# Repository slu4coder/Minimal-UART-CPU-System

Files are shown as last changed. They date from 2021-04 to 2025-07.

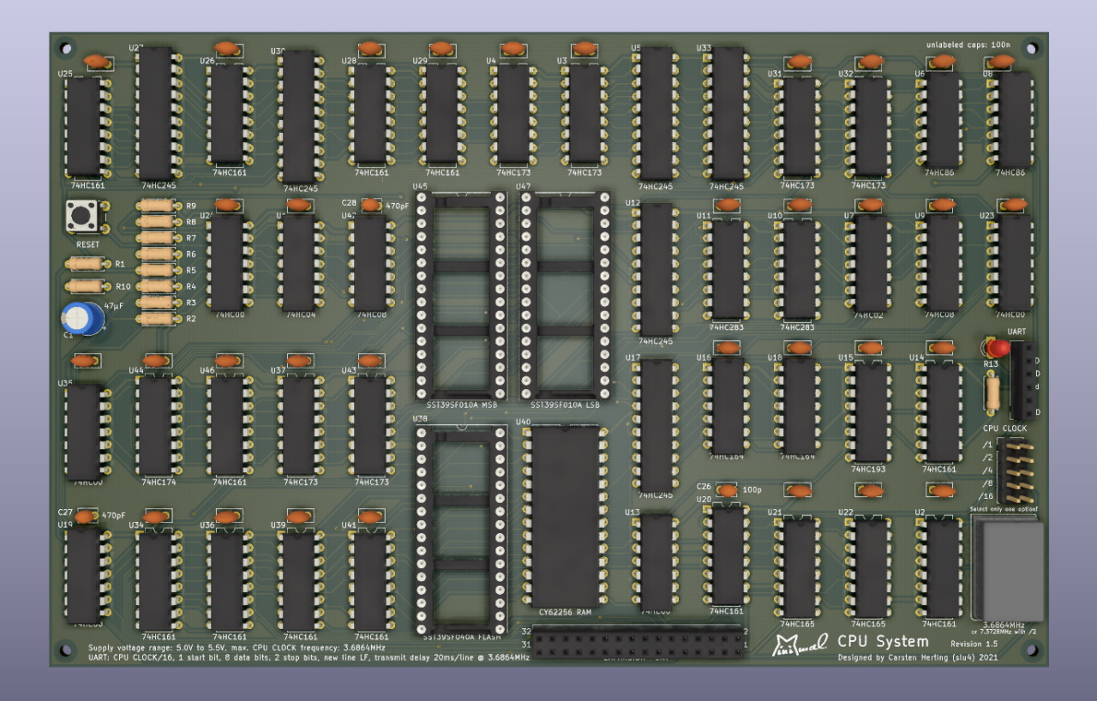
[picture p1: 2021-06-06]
Revisions 1.3 - 1.6 (FLASH)/Revision 1.5 (Expanded)/Minimal 1.5 Layout.jpg

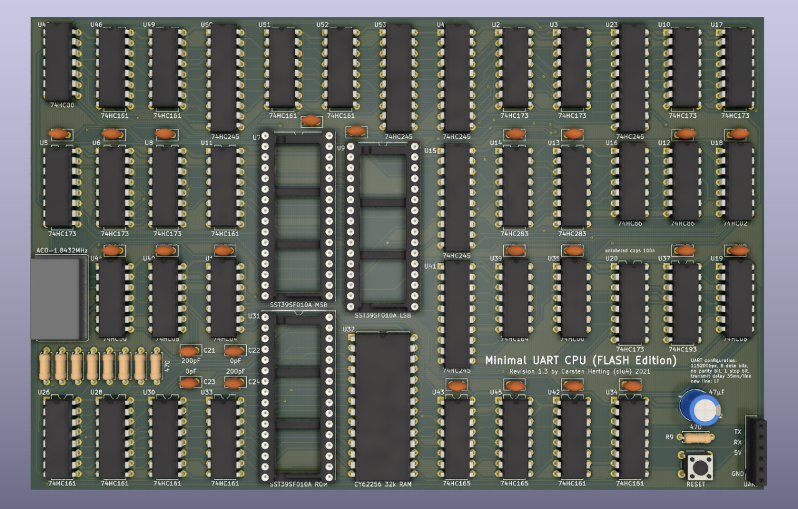
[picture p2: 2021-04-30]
Revisions 1.3 - 1.6 (FLASH)/Revision 1.3 (FLASH Edition)/Minimal 1.3 Layout.jpg

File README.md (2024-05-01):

# Legacy: Minimal UART CPU System

See https://github.com/slu4coder/Minimal-64x4-Home-Computer for the most recent version.

Quick note: This is a free and non-commercial project. I am in no way associated with any activies selling this as a product.
Any such activity represents a license violation. Individual licenses apply for hardware and software parts. Please refer to
appropriate documentations for detailed licensing information.

Minimal CPU 2.0 'Ultra' is now running at 10MHz(!) and may well be the fastest 8-bit general purpose 74HC logic breadboard computer to this date:

Ultra

Latest PCB version 1.5:

test

● Build your own 'Minimal CPU System' on breadboards: https://www.youtube.com/watch?v=Gz1VVOsNn_8

● Python-like high-level programming language MIN released: https://www.youtube.com/watch?v=H342TwW4R7k

● 'Minimal VGA Extension Card' released! https://github.com/slu4coder/DIY-VideoRAM/tree/main/KiCAD

● 'Minimal CPU System' Emulator released! See user manual chapter 'Minimal Emulator' for details.

● Native assembler and text editor released!

● User Manual and Reference: https://docs.google.com/document/d/1c2ZHtLd1BBAwcBAjBZZJmCA3AXpbpv80dlAtsMYpuF4/edit?usp=sharing

● Revision 1.5 is out now featuring 512KB FLASH SSD, 3.6864MHz clock speed and an expansion port!
https://www.youtube.com/watch?v=osVi06VKvA0

● Minimal Python Assembler released: https://www.youtube.com/watch?v=rdKX9hzA2lU

● The Minimal CPU System now has a dedicated hardware serial 'Minimal Terminal': https://github.com/slu4coder/Minimal-Terminal
but can also be operated via a USB-to-serial breakout board and a terminal emulation (e. g. Tera Term) of cause.

I've built my own Computer from scratch - using nothing but TTL chips, because, well, why not? I wanted a CPU that is easy to understand, fun to build and powerful enough to allow for programming educational stuff and little games on it. Ah, and by the way - it should be as simple as possible - sort of the "Simplest Usable Personal Computer". This repo provides you with everything you need to follow my one-and-a-half-year journey down this rabbit hole. Besides running some video game classics, this little DIY CPU is capable of parsing arbitrary mathmatical expressions and performing floating point calculations in single (32-bit) precision. And it comes with an SSD file system, too, since it uses it's own FLASH IC as permanent SSD storage. Over the last year I have written an entire native toolchain: a text editor, an assembler and the Python-like high-level programming language MIN.

WHAT YOU GET:

  ● Block diagram of the CPU and overview it's instruction set
  
  ● KiCAD project files with detailed schematics and PCB layout
  
  ● Gerber files ready to be submitted at any PCB manufacturer of your choice
  
  ● Bill of material
  
  ● Images in .bin format of both the ROM and the CPU's control microcode
  
  ● Source code of the minimal operating system MinOS and several demos and games
  
  ● Cross-assembler 'asm.exe' running on Windows (or Python) to comfortably write, assemble and upload your own software

TECHNICAL SPECIFICATION:
  
  ● Processing power (1.0Mips @8.3MHz) comparable to 2.3 x Commodore 64 or Apple II
  
  ● Clear(est?) and simple(st? – you judge!) design for fun and education
  
  ● 8-bit data bus, 16-bit address bus, Von-Neumann architecture
  
  ● 64 instructions (conditional branching, subroutines, stack and word ops)
  
  ● 32KB RAM / 512KB FLASH ROM (OS, memory monitor, disassembler, tools)
  
  ● SSD file system (commands LOAD, SAVE, DIR, DELETE, FORMAT as you'd expect)
  
  ● UART interface (up to 500kbps) for terminal display, keyboard input and file I/O
 
  ● Expansion port (I/O card and VGA card available, build your own!)
   
  ● 24 (16) control signals, 2 registers A and B, ALU (arithmetic and logic unit) = simple adder, 3 flags (negative, carry and zero)
  
  ● Built from 74HCxx TTL logic on 120mm x 190mm PCB or 8 breadboards

I hope you find this information useful, educational or otherwise interesting. I'd love to hear about your build, so meet me on YouTube.

https://www.youtube.com/channel/UCXYQcMpUBT3aaQKfmAVJNow

Have fun!
slu4

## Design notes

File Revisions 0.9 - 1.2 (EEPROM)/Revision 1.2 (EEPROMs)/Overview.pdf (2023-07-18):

- Comparable to Altair 8800 or Apple 1
- Clear(est?) and simple(st? – you judge!) design for fun and education
- 8-bit data bus, 16-bit address bus, Von-Neumann architecture
- 64 instructions (conditional branching, subroutines, stack and word ops)
- 1,8432MHz clock with 0.25Mips
(Altair 8800: 0.29Mips, Apple 1: 0.43Mips)
- 24kB RAM / 8kB ROM (OS, memory monitor, disassembler, tools, games)
- UART interface (115.2kbps)
for terminal display, keyboard input and file I/O
- 16 control signals
- 2 registers A and B
- ALU (arithmetic and logic unit) = simple adder
- 3 flags (negative, carry and zero)
- 74HCxx TTL logic on 120mm x 190mm PCB
- Cross-assembler (Windows 10) for easy programming and upload via terminal 'cut & past'

## Minimal UART Computer – Performance Overview

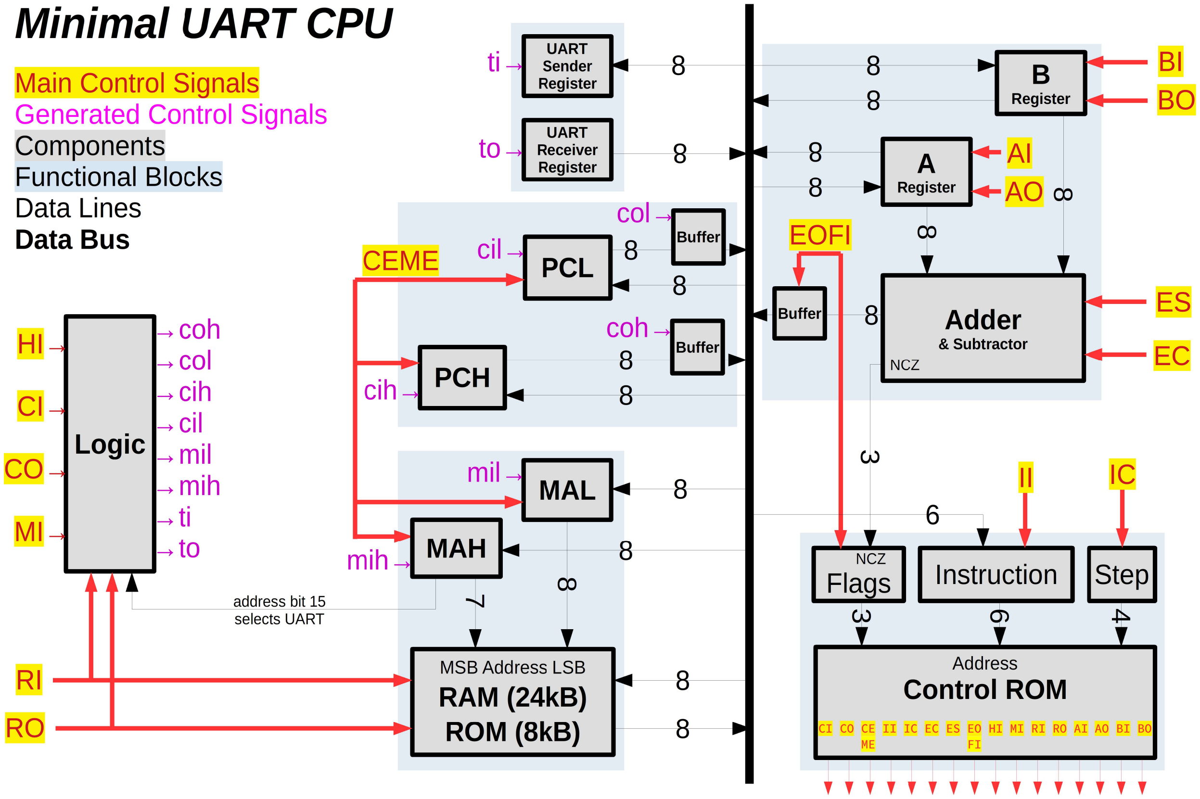
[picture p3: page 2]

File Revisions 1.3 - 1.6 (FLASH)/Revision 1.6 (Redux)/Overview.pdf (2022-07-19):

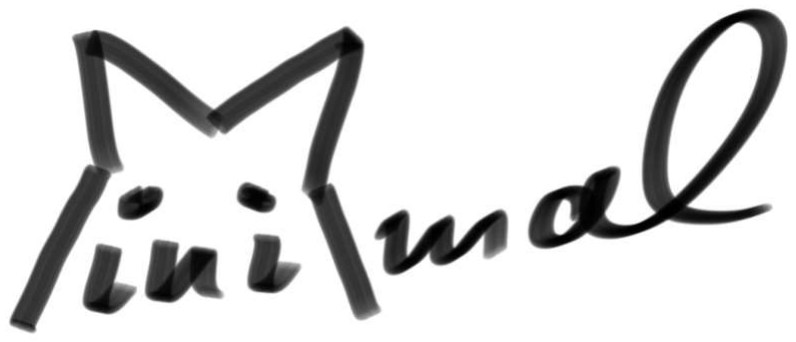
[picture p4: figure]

- Von-Neumann architecture, 8-bit data bus, 16-bit address bus
- 64 instructions including conditional branching, subroutines, stack and word operations
- UART interface for terminal display, keyboard input, data I/O & upload via 'cut & paste'
- 32KB RAM, 512KB FLASH with file system (format, load, save, dir, delete commands)
- Expansion port (I/O card, VGA card)
- Maximum clock speed 8.3MHz, 1.01Mips =
- 2 data registers A and B
- Simple adder
- 3 flags (negative, carry and zero)
- 24 control signals
- 39 TTL chips (74HCxx logic, 62256 SRAM, 39SF0x0 FLASH)
- Online reference manual
- Games like TETRIS, cross-assembler (Win10 or Python), cycle-exact emulator (Win10)
- Native tool-chain: Operating system, text editor, assembler, Python-like interpreter

# CPU System 1.6 Redux Beast Mode

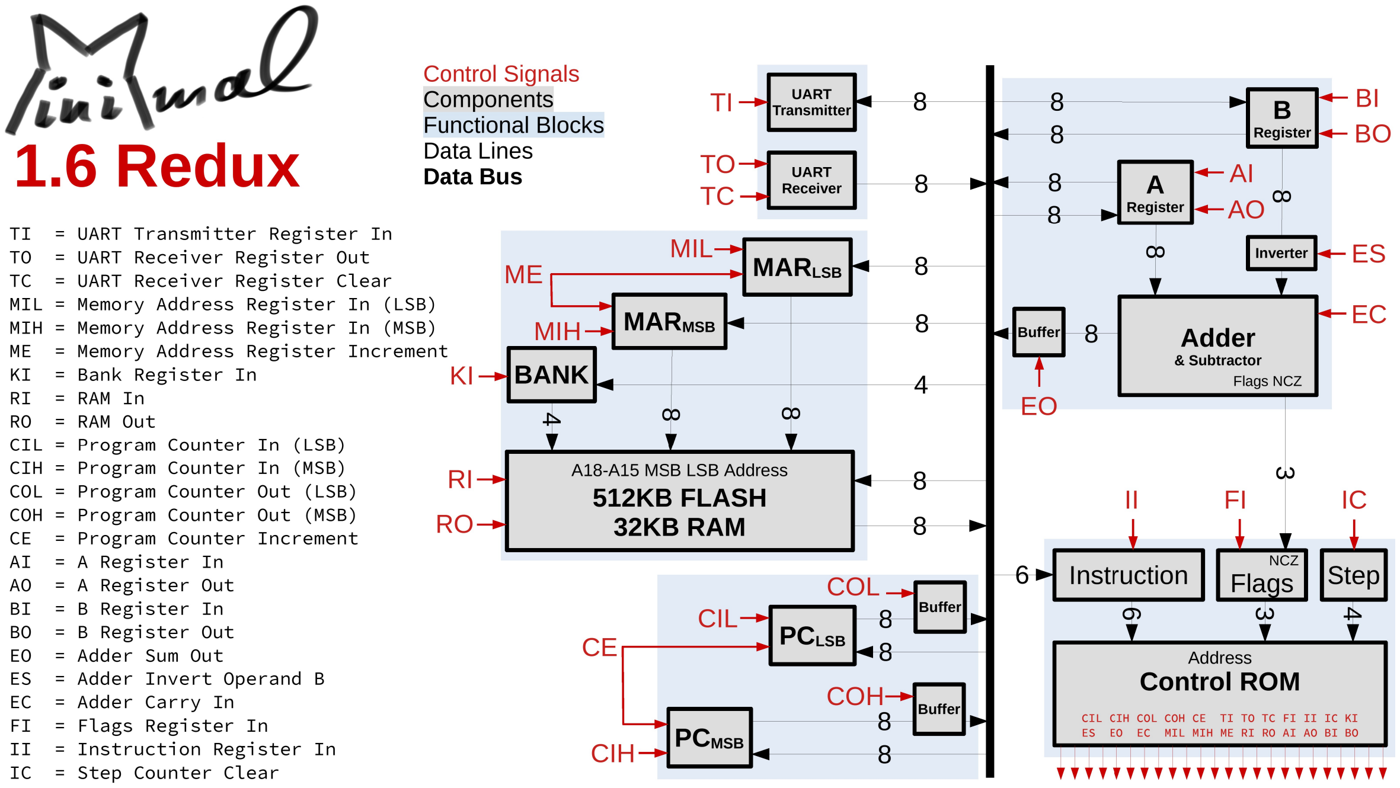
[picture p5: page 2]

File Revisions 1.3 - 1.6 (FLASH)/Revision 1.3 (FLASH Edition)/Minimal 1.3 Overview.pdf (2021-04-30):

- Comparable to Altair 8800 or Apple 1
- Clear(est?) and simple(st? – you judge!) design for fun and education
- 8-bit data bus, 16-bit address bus, Von-Neumann architecture
- 64 instructions (conditional branching, subroutines, stack and word operations)
- 1,8432MHz clock speed with 0.25Mips (Altair 8800: 0.29Mips, Apple 1: 0.43Mips)
- 32KB RAM and 4KB FLASH ROM (OS: memory monitor, tools, file system)
- 28KB SSD (file system: LOAD, SAVE, DELETE, SHOW) for games and demos
- UART interface (115.2kbps) for terminal display, keyboard input and data I/O
- only 16 control signals
- 2 data registers A and B
- ALU (arithmetic and logic unit) = simple adder
- 3 flags (negative, carry and zero)
- 74HCxx TTL logic on 115mm x 175mm PCB (all ICs also available in SMD package)
- Cross-assembler (Windows 10) for easy programming / upload via terminal 'cut & past'

## Minimal UART CPU (FLASH Edition) – Overview

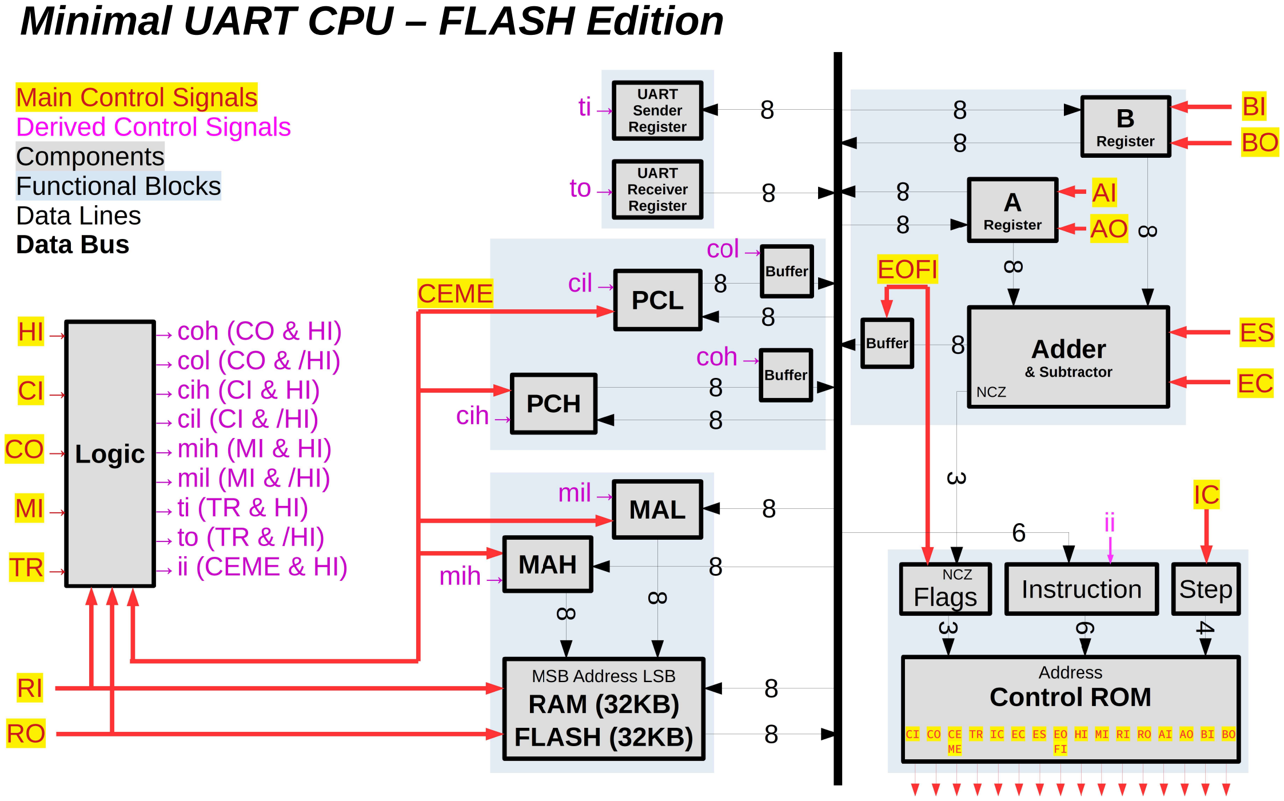
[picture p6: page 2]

Minimal UART CPU – FLASH Edition

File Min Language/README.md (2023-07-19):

# Min Is Not Python...
... but an interpreted computer language I develop for fun and as a learning experience, mainly to deploy it on my DIY 'Minimal UART CPU' project and also on my latest 'Minimal 64 Home Computer'.

This educational version of Min is written in 230 lines of Python code. Visit my YouTube channel for more information: https://www.youtube.com/channel/UCXYQcMpUBT3aaQKfmAVJNow

USAGE: python min.py blocks.min

What you get:

o Python-style indentation

o if-elif-else, while-break, print, def-return

o str(), input(), int(), len(), key(), random()

o string and integer data types

o local and global variables and 1-dimensional arrays

o functions with parameters and C-style referencing

o optional : and ; syntax sugar

o .. slicing operator replacing :

o 'A' replacing ord("A")

Have fun!

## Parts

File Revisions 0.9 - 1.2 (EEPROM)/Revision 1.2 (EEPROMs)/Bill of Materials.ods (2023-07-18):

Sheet: BOM sorted by reference
Ref | Value | Footprint
C1-C9 | 100nF | Capacitor_THT:C_Disc_D5.0mm_W2.5mm_P2.50mm
C10 | 100pF | Capacitor_THT:C_Disc_D5.0mm_W2.5mm_P2.50mm
C11-C51 | 100nF | Capacitor_THT:C_Disc_D5.0mm_W2.5mm_P2.50mm
C52 | 47µF | Capacitor_THT:CP_Radial_D7.5mm_P2.50mm
J1 | UART | Connector_PinSocket_1x06_P2.54mm_Vertical
R1-R8 | 470 | Resistor_THT_Axial_L6.3mm_D2.5mm_P7.62mm_Horizontal
R9 | 10k | Resistor_THT_Axial_L6.3mm_D2.5mm_P7.62mm_Horizontal
R10 | jumper wire | Resistor_THT_Axial_L6.3mm_D2.5mm_P7.62mm_Horizontal
SW1 | RESET | Button_Switch_THT:SW_PUSH_6mm
U1 | 74HC04 | Package_DIP:DIP-14_W7.62mm
U2 | 74HC173 | Package_DIP:DIP-16_W7.62mm
U3 | 74HC173 | Package_DIP:DIP-16_W7.62mm
U4 | 74HC245 | Package_DIP:DIP-20_W7.62mm
U5 | 74HC173 | Package_DIP:DIP-16_W7.62mm
U6 | 74HC173 | Package_DIP:DIP-16_W7.62mm
U7 | AT28C64B CTRL MSB | Package_DIP:DIP-28_W15.24mm_Socket
U8 | 74HC173 | Package_DIP:DIP-16_W7.62mm
U9 | AT28C64B CTRL LSB | Package_DIP:DIP-28_W15.24mm_Socket
U10 | 74HC173 | Package_DIP:DIP-16_W7.62mm
U11 | 74HC161 | Package_DIP:DIP-16_W7.62mm
U12 | 74HC86 | Package_DIP:DIP-14_W7.62mm
U13 | 74HC283 | Package_DIP:DIP-16_W7.62mm
U14 | 74HC283 | Package_DIP:DIP-16_W7.62mm
U15 | 74HC245 | Package_DIP:DIP-20_W7.62mm
U16 | 74HC86 | Package_DIP:DIP-14_W7.62mm
U17 | 74HC173 | Package_DIP:DIP-16_W7.62mm
U18 | 74HC02 | Package_DIP:DIP-14_W7.62mm
U19 | 74HC08 | Package_DIP:DIP-14_W7.62mm
U23 | 74HC245 | Package_DIP:DIP-20_W7.62mm
U24 | 74HC32 | Package_DIP:DIP-14_W7.62mm
U26 | 74HC161 | Package_DIP:DIP-16_W7.62mm
U28 | 74HC161 | Package_DIP:DIP-16_W7.62mm
U29 | 74HC32 | Package_DIP:DIP-14_W7.62mm
U30 | 74HC161 | Package_DIP:DIP-16_W7.62mm
U31 | AT28C64B 8k ROM | Package_DIP:DIP-28_W15.24mm_Socket
U32 | CY62256 32k RAM | Package_DIP:DIP-28_W15.24mm
U33 | 74HC161 | Package_DIP:DIP-16_W7.62mm
U34 | 74HC161 | Package_DIP:DIP-16_W7.62mm
U35 | 74HC00 | Package_DIP:DIP-14_W7.62mm
U36 | 74HC173 | Package_DIP:DIP-16_W7.62mm
U37 | 74HC193 | Package_DIP:DIP-16_W7.62mm
U38 | 74HC173 | Package_DIP:DIP-16_W7.62mm
U39 | 74HC164 | Package_DIP:DIP-14_W7.62mm
U40 | 74HC02 | Package_DIP:DIP-14_W7.62mm
U41 | 74HC173 | Package_DIP:DIP-16_W7.62mm
U42 | 74HC161 | Package_DIP:DIP-16_W7.62mm
U43 | 74HC165 | Package_DIP:DIP-16_W7.62mm
U44 | 74HC00 | Package_DIP:DIP-14_W7.62mm
U45 | 74HC165 | Package_DIP:DIP-16_W7.62mm
U46 | 74HC161 | Package_DIP:DIP-16_W7.62mm
U48 | 74HC32 | Package_DIP:DIP-14_W7.62mm
U49 | 74HC161 | Package_DIP:DIP-16_W7.62mm
U50 | 74HC245 | Package_DIP:DIP-20_W7.62mm
U51 | 74HC161 | Package_DIP:DIP-16_W7.62mm
U52 | 74HC161 | Package_DIP:DIP-16_W7.62mm
U53 | 74HC245 | Package_DIP:DIP-20_W7.62mm
X1 | ACO-1.8432MHz | Oscillator:Oscillator_DIP-14

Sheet: BOM sorted by value
Qty | Value | Footprint
47 | 100nF | Capacitor_THT:C_Disc_D5.0mm_W2.5mm_P2.50mm
1 | 100pF | Capacitor_THT:C_Disc_D5.0mm_W2.5mm_P2.50mm
1 | 47µF | Capacitor_THT:CP_Radial_D7.5mm_P2.50mm
1 | UART | Connector_PinSocket_2.54mm:PinSocket_1x06_P2.54mm_Vertical
8 | 470 | Resistor_THT:R_Axial_DIN0207_L6.3mm_D2.5mm_P7.62mm_Horizontal
1 | 10k | Resistor_THT:R_Axial_DIN0207_L6.3mm_D2.5mm_P7.62mm_Horizontal
1 | jumper wire | Resistor_THT:R_Axial_DIN0207_L6.3mm_D2.5mm_P7.62mm_Horizontal
1 | RESET | Button_Switch_THT:SW_PUSH_6mm
1 | 74HC04 | Package_DIP:DIP-14_W7.62mm
10 | 74HC173 | Package_DIP:DIP-16_W7.62mm
5 | 74HC245 | Package_DIP:DIP-20_W7.62mm
11 | 74HC161 | Package_DIP:DIP-16_W7.62mm
2 | 74HC86 | Package_DIP:DIP-14_W7.62mm
2 | 74HC283 | Package_DIP:DIP-16_W7.62mm
2 | 74HC02 | Package_DIP:DIP-14_W7.62mm
1 | 74HC08 | Package_DIP:DIP-14_W7.62mm
3 | 74HC32 | Package_DIP:DIP-14_W7.62mm
3 | AT28C64B 8k EEPROM | Package_DIP:DIP-28_W15.24mm
3 | DIP-28_W15.24mm_Socket | Package_DIP:DIP-28_W15.24mm_Socket
1 | CY62256 32k RAM | Package_DIP:DIP-28_W15.24mm
2 | 74HC00 | Package_DIP:DIP-14_W7.62mm
1 | 74HC193 | Package_DIP:DIP-16_W7.62mm
1 | 74HC164 | Package_DIP:DIP-14_W7.62mm
2 | 74HC165 | Package_DIP:DIP-16_W7.62mm
1 | ACO-1.8432MHz | Oscillator:Oscillator_DIP-14

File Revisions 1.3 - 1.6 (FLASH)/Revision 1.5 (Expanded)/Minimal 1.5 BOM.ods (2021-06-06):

Item | Qty | Reference(s) | Value | LibPart | Footprint
1 | 1 | C1 | 47µF | Device:CP_Small | Capacitor_THT:CP_Radial_D6.3mm_P2.50mm
2 | 33 | C2, C3, C4, C5, C6, C7, C8, C9, C10, C11, C12, C13, C14, C15, C16, C17, C18, C19, C20, C21, C22, C23, C24, C25, C29, C30, C31, C32, C33, C34, C35, C36, C37 | 100nF | Device:C_Small | Capacitor_THT:C_Disc_D5.0mm_W2.5mm_P2.50mm
3 | 1 | C26 | 100p | Device:C_Small | Capacitor_THT:C_Disc_D3.8mm_W2.6mm_P2.50mm
4 | 2 | C27, C28 | 470pF | Device:C_Small | Capacitor_THT:C_Disc_D3.8mm_W2.6mm_P2.50mm
5 | 1 | D3 | 5V | Device:LED | LED_THT:LED_D3.0mm
7 | 1 | J1 | UART | Connector:Conn_01x06_Female | Connector_PinSocket_2.54mm:PinSocket_1x06_P2.54mm_Vertical
8 | 1 | J2 | CLOCK SEL | Connector_Generic:Conn_02x04_Odd_Even | Connector_PinHeader_2.54mm:PinHeader_2x04_P2.54mm_Vertical
9 | 1 | J3 | EXPANSION PORT | Connector_Generic:Conn_02x16_Top_Bottom | Connector_PinSocket_2.54mm:PinSocket_2x16_P2.54mm_Vertical
10 | 2 | R1, R10 | 4.7k | Device:R | Resistor_THT:R_Axial_DIN0207_L6.3mm_D2.5mm_P7.62mm_Horizontal
11 | 8 | R2, R3, R4, R5, R6, R7, R8, R9 | 470 | Device:R | Resistor_THT:R_Axial_DIN0207_L6.3mm_D2.5mm_P7.62mm_Horizontal
12 | 1 | R13 | 1k | Device:R | Resistor_THT:R_Axial_DIN0207_L6.3mm_D2.5mm_P7.62mm_Horizontal
13 | 1 | SW1 | RESET | Switch:SW_Push | Button_Switch_THT:SW_PUSH_6mm
14 | 1 | U1 | 74HC04 | 74xx:74HC04 | Package_DIP:DIP-14_W7.62mm
15 | 12 | U2, U14, U20, U25, U26, U28, U29, U34, U36, U39, U41, U46 | 74HC161 | 8-Bit CPU 32k:74HC161 | Package_DIP:DIP-16_W7.62mm
16 | 6 | U3, U4, U31, U32, U37, U43 | 74HC173 | 8-Bit CPU 32k:74HC173 | Package_DIP:DIP-16_W7.62mm
17 | 6 | U5, U12, U17, U27, U30, U33 | 74HC245 | 74xx:74HC245 | Package_DIP:DIP-20_W7.62mm
18 | 2 | U6, U8 | 74HC86 | 74xx:74HC86 | Package_DIP:DIP-14_W7.62mm
19 | 1 | U7 | 74HC02 | 74xx:74HC02 | Package_DIP:DIP-14_W7.62mm
20 | 2 | U9, U42 | 74HC08 | 8-Bit CPU 32k:74HC08 | Package_DIP:DIP-14_W7.62mm
21 | 2 | U10, U11 | 74HC283 | 8-Bit CPU 32k:74HC283 | Package_DIP:DIP-16_W7.62mm
22 | 5 | U13, U19, U23, U24, U35 | 74HC00 | 74xx:74HC00 | Package_DIP:DIP-14_W7.62mm
23 | 1 | U15 | 74HC193 | 8-Bit CPU 32k:74HC193 | Package_DIP:DIP-16_W7.62mm
24 | 2 | U16, U18 | 74HC164 | 74xx:74HC164 | Package_DIP:DIP-14_W7.62mm
25 | 2 | U21, U22 | 74HC165 | 8-Bit CPU 32k:74HC165 | Package_DIP:DIP-16_W7.62mm
26 | 1 | U38 | SST39SF040A FLASH | 8-Bit CPU 32k:SST39SF040A | Package_DIP:DIP-32_W15.24mm_Socket
27 | 1 | U40 | CY62256 RAM | 8-Bit CPU 32k:CY62256 | Package_DIP:DIP-28_W15.24mm_Socket
28 | 1 | U44 | 74HC174 | 8-Bit CPU 32k:74HC174 | Package_DIP:DIP-16_W7.62mm
29 | 1 | U45 | SST39SF010A MSB | 8-Bit CPU 32k:SST39SF010A | Package_DIP:DIP-32_W15.24mm_Socket
30 | 1 | U47 | SST39SF010A LSB | 8-Bit CPU 32k:SST39SF010A | Package_DIP:DIP-32_W15.24mm_Socket
31 | 1 | X1 | 7.3728MHz or 3.6864MHz | Oscillator:ACO-xxxMHz | Oscillator:Oscillator_DIP-14

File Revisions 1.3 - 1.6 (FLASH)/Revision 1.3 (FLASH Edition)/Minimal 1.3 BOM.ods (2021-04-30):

Qty | Reference(s) | Value
20 | C1-C20 | 100nF ceramic cap
4 | C21, C22, C23, C24 | 200pF ceramic cap
1 | C52 | 47µF electrolytic cap
1 | J1 | Connector 1x6 2,54mm female
9 | R1, R2, R3, R4, R5, R6, R7, R8, R9 | 470R
1 | SW1 | 6mm x 6mm x 5mm push button
1 | U1 | 74HC04
8 | U2, U3, U5, U6, U8, U10, U17, U20 | 74HC173
6 | U4, U15, U23, U41, U50, U53 | 74HC245
11 | U11, U26, U28, U30, U33, U34, U42, U46, U49, U51, U52 | 74HC161
2 | U12, U16 | 74HC86
2 | U13, U14 | 74HC283
1 | U18 | 74HC02
2 | U19, U40 | 74HC08
3 | U35, U44, U48 | 74HC00
1 | U37 | 74HC193
1 | U39 | 74HC164
2 | U43, U45 | 74HC165
1 | X1 | ACO-1.8432MHz crystal
3 | U7, U9, U31 | SST39SF010A FLASH
1 | U32 | CY62256 RAM

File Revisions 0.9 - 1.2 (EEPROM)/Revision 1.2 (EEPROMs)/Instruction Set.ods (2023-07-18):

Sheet: Overview
Version 1.2.0 | Legend: | not applicable |  | not implemented |  | implemented
Description | Accumulator No Operand | Accumulator Immediate | Accumulator Abs Address | Accumulator Rel Address | Byte at Abs Address | Word at Abs Address | Stack at SP + Offset | 64
Load A from |  | LDI | LDA | LDR |  |  | LDS |  | 1 | 1 | 1 |  |  | 1
Store A to |  |  | STA | STR |  |  | STS |  |  | 1 | 1 |  |  | 1
Clear |  |  |  |  | CLB | CLW |  |  |  |  |  | 1 | 1
Negate | NEG |  |  |  | NEB | NEW |  | 1 |  |  |  | 1 | 1
Increment | INC |  |  |  | INB | INW |  | 1 |  |  |  | 1 | 1
Decrement | DEC |  |  |  | DEB | DEW |  | 1 |  |  |  | 1 | 1
Add |  | ADI | ADA | ADR | ADB | ADW |  |  | 1 | 1 | 1 | 1 | 1
Subtract |  | SBI | SBA | SBR | SBB | SBW |  |  | 1 | 1 | 1 | 1 | 1
Compare |  | CPI | CPA | CPR |  |  |  |  | 1 | 1 | 1
Add with Carry In |  | ACI | ACA | ACR | ACB | ACW |  |  | 1 | 1 | 1 | 1 | 1
Subtract with Carry In |  | SCI | SCA | SCR | SCB | SCW |  |  | 1 | 1 | 1 | 1 | 1
Jump to |  |  | JPA | JPR |  |  |  |  |  | 1 | 1
Jump to Subroutine |  |  | JPS |  |  |  |  |  |  | 1
Return from Subroutine | RTS |  |  |  |  |  |  | 1
No Operation (16 clocks) | NOP |  |  |  |  |  |  | 1
Terminal Input | INP |  |  |  |  |  |  | 1
Wait on Terminal Input | WIN |  |  |  |  |  |  | 1
Output A to Terminal | OUT |  |  |  |  |  |  | 1
Clear Carry In Flag | CLC |  |  |  |  |  |  | 1
Set Carry In Flag | SEC |  | Description |  | Accumulator No Operand | Accumulator Immediate | Accumulator Abs Address | 1
Logical Shift Left (= ASL) | LSL |  |  |  |  |  |  | 1
Rotate Shift Left | ROL |  | Branch on Non-Zero |  |  |  | BNE | 1 |  |  |  |  |  | 1
Logical Shift Right | LSR |  | Branch on Zero |  |  |  | BEQ | 1 |  |  |  |  |  | 1
Rotate Shift Right | ROR |  | Branch on Carry Clear |  |  |  | BCC | 1 |  |  |  |  |  | 1
Arithmetic Shift Right | ASR |  | Branch on Carry Set |  |  |  | BCS | 1 |  |  |  |  |  | 1
Push on Stack | PHS |  | Branch on Plus |  |  |  | BPL | 1 |  |  |  |  |  | 1
Pull from Stack | PLS |  | Branch on Minus |  |  |  | BMI | 1 |  |  |  |  |  | 1

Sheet: Properties
Version 1.2.0 |  |  |  | Legend: A=accumulator, R=result, M=most significant byte, ?=undefined, -=unchanged
Instruction | Code |  | Description | Target | Operand |  | Accumulator | Flags |  |  | Clock
Name | DEC | HEX |  |  | Type | Size | Change | N | C | Z | Cycles
NOP | 0 | 00 | No Operation | none | none | 0 | none | - | - | - | 16
WIN | 1 | 01 | Wait on Terminal Input | A | UART | 0 | result | A | 0 | A | n/a
OUT | 2 | 02 | Output to Terminal | UART | A | 0 | none | 1 | 0 | 0 | 6
CLC | 3 | 03 | Clear Carry In Flag | none | none | 0 | none | 1 | 0 | 0 | 5
SEC | 4 | 04 | Set Carry In Flag | none | none | 0 | none | 0 | 1 | 1 | 5
LSL | 5 | 05 | Logical Shift Left (=ASL) | A | none | 0 | result | R | R | R | 5
ROL | 6 | 06 | Rotate Shift Left | A | none | 0 | result | R | R | R | 5
LSR | 7 | 07 | Logical Shift Right | A | none | 0 | result | R | R | R | 13
ROR | 8 | 08 | Rotate Shift Right | A | none | 0 | result | R | R | R | 12
ASR | 9 | 09 | Arithmetic Shift Right | A | none | 0 | result | R | R | R | 15
INP | 10 | 0A | Clear | A | none | 0 | result | 1 | 0 | 0 | 6
NEG | 11 | 0B | Negate | A | none | 0 | result | A | ? | A | 6
INC | 12 | 0C | Increment | A | none | 0 | result | R | R | R | 5
DEC | 13 | 0D | Decrement | A | none | 0 | result | R | R | R | 5
LDI | 14 | 0E | Load from | A | immediate | 1 | result | - | - | - | 4
ADI | 15 | 0F | Add | A | immediate | 1 | result | R | R | R | 5
SBI | 16 | 10 | Subtract | A | immediate | 1 | result | R | R | R | 5
CPI | 17 | 11 | Compare | A | immediate | 1 | none | R | R | R | 5
ACI | 18 | 12 | Add with Carry In | A | immediate | 1 | result | R | R | R | 5
SCI | 19 | 13 | Subtract with Carry In | A | immediate | 1 | result | R | R | R | 5
JPA | 20 | 14 | Jump to | PC | abs address | 2 | none | - | - | - | 6
LDA | 21 | 15 | Load from | A | abs address | 2 | result | - | - | - | 7
STA | 22 | 16 | Store A to | byte @ | abs address | 2 | none | - | - | - | 8
ADA | 23 | 17 | Add | A | abs address | 2 | result | R | R | R | 8
SBA | 24 | 18 | Subtract | A | abs address | 2 | result | R | R | R | 8
CPA | 25 | 19 | Compare | A | abs address | 2 | none | R | R | R | 8
ACA | 26 | 1A | Add with Carry In | A | abs address | 2 | result | R | R | R | 8
SCA | 27 | 1B | Subtract with Carry In | A | abs address | 2 | result | R | R | R | 8
JPR | 28 | 1C | Jump to | PC | rel address | 2 | none | - | - | - | 9
LDR | 29 | 1D | Load from | A | rel address | 2 | result | - | - | - | 10
STR | 30 | 1E | Store A to | byte @ | rel address | 2 | none | - | - | - | 10
ADR | 31 | 1F | Add | A | rel address | 2 | result | R | R | R | 11
SBR | 32 | 20 | Subtract | A | rel address | 2 | result | R | R | R | 11
CPR | 33 | 21 | Compare | A | rel address | 2 | none | R | R | R | 11
ACR | 34 | 22 | Add with Carry In | A | rel address | 2 | result | R | R | R | 11
SCR | 35 | 23 | Subtract with Carry In | A | rel address | 2 | result | R | R | R | 11
CLB | 36 | 24 | Clear | byte @ | abs address | 2 | like target | 0 | 1 | 0 | 8
NEB | 37 | 25 | Negate | byte @ | abs address | 2 | like target | A | ? | A | 10
INB | 38 | 26 | Increment | byte @ | abs address | 2 | like target | R | R | R | 10
DEB | 39 | 27 | Decrement | byte @ | abs address | 2 | like target | R | R | R | 10
ADB | 40 | 28 | Add | byte @ | abs address | 2 | none | R | R | R | 9
SBB | 41 | 29 | Subtract | byte @ | abs address | 2 | none | R | R | R | 10
ACB | 42 | 2A | Add with Carry In | byte @ | abs address | 2 | none | R | R | R | 9
SCB | 43 | 2B | Subtract with Carry In | byte @ | abs address | 2 | none | R | R | R | 10
CLW | 44 | 2C | Clear | word @ | abs address | 2 | none | 0 | 1 | 0 | 10
NEW | 45 | 2D | Negate | word @ | abs address | 2 | not preserved | M | ? | M | 12
INW | 46 | 2E | Increment | word @ | abs address | 2 | not preserved | M | M | M | 12
DEW | 47 | 2F | Decrement | word @ | abs address | 2 | not preserved | M | M | M | 12
ADW | 48 | 30 | Add | word @ | abs address | 2 | not preserved | M | M | M | 11
SBW | 49 | 31 | Subtract | word @ | abs address | 2 | not preserved | M | M | M | 12
ACW | 50 | 32 | Add with Carry In | word @ | abs address | 2 | not preserved | M | M | M | 12
SCW | 51 | 33 | Subtract with Carry In | word @ | abs address | 2 | not preserved | M | M | M | 13
LDS | 52 | 34 | Load from Stack | A | offset | 1 | result | ? | ? | ? | 9
STS | 53 | 35 | Store A on Stack | stack | offset | 1 | none | ? | ? | ? | 16
PHS | 54 | 36 | Push on Stack | stack | none | 0 | none | ? | ? | ? | 12
PLS | 55 | 37 | Pull from Stack | A | none | 0 | result | ? | ? | ? | 10
JPS | 56 | 38 | Jump to Subroutine | PC | abs address | 2 | not preserved | ? | ? | ? | 16
RTS | 57 | 39 | Return from Subroutine | PC | none | 0 | not preserved | ? | ? | ? | 14
BNE | 58 | 3A | Branch on Non-Zero | PC | abs address | 2 | none | - | - | - | 5/6
BEQ | 59 | 3B | Branch on Zero | PC | abs address | 2 | none | - | - | - | 5/6
BCC | 60 | 3C | Branch on Carry Clear | PC | abs address | 2 | none | - | - | - | 5/6
BCS | 61 | 3D | Branch on Carry Set | PC | abs address | 2 | none | - | - | - | 5/6
BPL | 62 | 3E | Branch on Plus | PC | abs address | 2 | none | - | - | - | 5/6
BMI | 63 | 3F | Branch on Minus | PC | abs address | 2 | none | - | - | - | 5/6

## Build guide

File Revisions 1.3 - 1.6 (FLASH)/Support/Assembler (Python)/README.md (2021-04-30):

# Let's Code an Assembler from Scratch in Python (< 100 Lines)

Project files of YouTube video https://www.youtube.com/watch?v=rdKX9hzA2lU

Usage: python asm.py hello.txt

Cut & paste output into your terminal (e. g. Tera Term) to upload the program into the 'Minimal CPU System'.

Have fun!
slu4

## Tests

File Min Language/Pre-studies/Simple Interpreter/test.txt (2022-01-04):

sub demo                    # do some commenting
{
  a = "math expressions "
  b = (10 + 1*2 + (4 + 5)*2 )*3 - val("111")
	print "Test " + a + str(b), "\n"
	if 0 | 5 > -2 | 0 print "True" else print "False"
	x=0 
  while x<20
	{
		if !x<10 break
		print "." x=x+1
	}
}

print "Hello, World!\n"     # program entry point
gosub demo

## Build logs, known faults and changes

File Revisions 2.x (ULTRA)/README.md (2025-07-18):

# Breadboard version 2.0 (Experimental)

Experimental evolutionary revision of my Minimal UART CPU, exploring the idea of efficient PC-to-MAR transfer.
My later Minimal 64x4 TTL computer uses a better approach.

ONLY USE HIGH-QUALITY BREADBOARDS FOR YOUR BUILD!

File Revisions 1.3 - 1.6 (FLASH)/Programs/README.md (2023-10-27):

0. Copy "Support/Assembler (Win64)/asm.exe" into this folder.

1. Start a command shell (cmd) and type:

	asm hello.txt

2. Cut and paste the output into your terminal emulation (e. g. Tera Term)
   to upload the program into the memory of the Minimal UART CPU System.

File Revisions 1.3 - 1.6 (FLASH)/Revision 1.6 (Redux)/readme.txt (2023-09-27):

Revision 1.6 ("Redux") is software-compatible to revision 1.5. The schematics and the microcode, however, have been optimized for build-simplicity on breadboards. Only 39 ICs are being used, compared to the 47 ICs of revision 1.5.

NEW: Minimal 'Beast Mode' can run at up to 8.3MHz clock speed.

ONLY USE HIGH-QUALITY BREADBOARDS FOR YOUR BUILD!

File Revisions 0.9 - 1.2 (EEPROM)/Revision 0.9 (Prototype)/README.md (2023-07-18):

# Minimalistic 8-Bit CPU Revision 0.9 (First Breadboard Prototype)

This a legacy version! Latest revision: https://github.com/slu4coder/Minimal-UART-CPU-System

Hi there! You have made it to my repo where I keep track of the files relevant to my 'Minimal 8-Bit Computer' design.
This includes:

- KiCad schematics
- Control logic microcode (EEPROM data)
- Arduino sketches (VGA card and clock / RAM upload)
- Assember written in C++ (Win64 only)
- Emulator written in C++/OpenGL (Win64 only)
- Operating system 'MinOS' (memory monitor aka WOZMON, absolute loader, bootstrap loader, save routine, memory filler, help screen, etc.)
- Software projects (32-bit math, displaying numbers in HEX / DEC, PONG and TETRIS clones I've written for fun, etc.)

See my video series about the design on YouTube: https://www.youtube.com/channel/UCXYQcMpUBT3aaQKfmAVJNow

Cheers,
Slu4

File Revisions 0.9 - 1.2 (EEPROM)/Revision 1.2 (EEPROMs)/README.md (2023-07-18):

# Minimal UART Computer Revision 1.2 with EEPROMs

Current version: https://github.com/slu4coder/Minimal-UART-CPU-System

Hi there, I built my own Computer from scratch - using nothing but TTL chips, because, well, that's what I wanted to do, I guess! I wanted
a CPU that is easy to understand, fun to build and powerful enough to allow for programming educational stuff and little games on it.
Ah, and by the way - it should be as simple as possible - sort of the "Simplest Usable Personal Computer Ever". Well, in case you're
interested, this repo aims to provide you with everything you need to follow my one-and-a-half year journey down this rabbit hole. 

WHAT YOU GET HERE:

  ● Block diagram of the CPU and overview it's instruction set

  ● KiCAD project files with detailed schematics and PCB layout

  ● Gerber files ready to be submitted at any PCB manufacturer of your choice

  ● Bill of material

  ● Images in .bin format of both the ROM and the CPU's control microcode

  ● Source code of the minimal operating system MinOS and several demos and games

  ● Cross-assembler 'asm.exe' running on Windows in order to comfortably write, assemble and upload your own software

TECHNICAL SPECIFICATION:

  ● Comparable to Altair 8800 or Apple 1

  ● Clear(est?) and simple(st? – you judge!) design for fun and education

  ● 8-bit data bus, 16-bit address bus, Von-Neumann architecture

  ● 64 instructions (conditional branching, subroutines, stack and word ops)

  ● 1,8432MHz clock with 0.25Mips (Altair 8800: 0.29Mips, Apple 1: 0.43Mips)

  ● 24kB RAM / 8kB ROM (OS, memory monitor, disassembler, tools, games)

  ● UART interface (115.2kbps) for terminal display, keyboard input and file I/O

  ● 16 control signals, 2 registers A and B, ALU (arithmetic and logic unit) = simple adder, 3 flags (negative, carry and zero)

  ● Built from 74HCxx TTL logic on 120mm x 190mm PCB

I hope you find this information useful, educational or otherwise interesting. I'd love to hear about you build, so meet me on YouTube.

https://www.youtube.com/channel/UCXYQcMpUBT3aaQKfmAVJNow

Cheers,
Slu4

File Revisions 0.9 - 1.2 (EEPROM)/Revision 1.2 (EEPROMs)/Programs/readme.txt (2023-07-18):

1. Start a command shell (cmd) in this folder and type:

	asm examples/hello.txt

2. Cut and paste the output into your terminal emulation to upload the program into the memory of the Minimal UART CPU.

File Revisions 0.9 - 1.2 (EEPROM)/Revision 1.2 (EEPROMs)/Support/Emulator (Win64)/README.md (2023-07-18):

# Legacy Educational Version of the 'Minimal-UART-CPU Emulator' Revision 1.2

Files I've used in my educational YouTube video about how to emulate a 'Minimal UART CPU System' cycle-exactly and in real-time in under 250 lines of C++ code.

I write a cycle exact real-time emulator for a simple CPU system in C++ in about 250 lines of code and briefly explain some of my concepts along the way. Update: The instruction set is now compatible with the Minimal UART Computer (FLASH Edition).

Infos on the current state of the corresponding hardware project: https://github.com/slu4coder/Minimal-UART-Computer

Visit my YouTube channel to check out my latest developments: https://www.youtube.com/channel/UCXYQcMpUBT3aaQKfmAVJNow

Have fun!

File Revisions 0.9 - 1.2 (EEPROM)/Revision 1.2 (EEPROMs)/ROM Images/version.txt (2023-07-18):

2020_12_23 Initial release, microcode version 1.2, ROM version 1.2.0
2021_02_12 Updated instruction set. Please note that it is NOT 100% compatible to board
           revisions 1.3 and onwards (aka FLASH Editions) due to a slightly different CPU architecture.

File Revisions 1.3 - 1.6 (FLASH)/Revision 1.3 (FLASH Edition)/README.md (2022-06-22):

See folder "Revision 1.5" for ROM images and microcode information.

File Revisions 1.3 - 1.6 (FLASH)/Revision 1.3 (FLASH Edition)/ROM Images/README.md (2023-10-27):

See folder "Revision 1.5" for ROM images and microcode information.

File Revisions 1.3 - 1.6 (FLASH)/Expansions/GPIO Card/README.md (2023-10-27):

See my YouTube channel for more information.

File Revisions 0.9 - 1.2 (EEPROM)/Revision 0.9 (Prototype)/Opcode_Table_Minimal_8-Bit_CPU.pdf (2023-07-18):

Opcode Table of the Minimal 8-Bit CPU

description | no operand (A) | immediate | abs address | rel address | word at abs adr | (SP + rel offset)
Load A from | | LDI (0x0b) | LDA (0x15) | LDR (0x21) | | LDS (0x2c)
Store A to | | | STA (0x16) | STR (0x22) | | STS (0x2d)
Clear | | | CLA (0x17) | CLR (0x23) | CLW (0x32)
Negate | NEG (0x0c) | | NEA (0x18) | NER (0x24) | NEW (0x33)
Increment | INC (0x0d) | | INA (0x19) | INR (0x25) | INW (0x34)
Decrement | DEC (0x0e) | | DEA (0x1a) | DER (0x26) | DEW (0x35)
Add | | ADI (0x0f) | ADA (0x1b) | ADR (0x27) | ADW (0x36)
Subtract | | SBI (0x10) | SBA (0x1c) | SBR (0x28) | SBW (0x37)
Compare | | CPI (0x11) | CPA (0x1d) | CPR (0x29)
Add with Carry | | ACI (0x12) | ACA (0x1e) | ACR (0x2a) | ACW (0x38)
Sub with Carry | | SCI (0x13) | SCA (0x1f) | SCR (0x2b) | SCW (0x39)
Jump to | | | JPA (0x14) | JPR (0x20)
Jump to subroutine | | | JPS (0x30)
description | no operand (A) | immediate | abs address | rel address | word at abs adr | (SP + rel offset)
No Operation | NOP (0x00)
Wait on Terminal Input | WIN (0x01)
Output A to Terminal | OUT (0x02)
Clear Carry In Flag | CLC (0x03)
Set Carry In Flag | SEC (0x04)
Logical NOT | NOT (0x05)
Logical Shift Left | LSL (0x06)
Rotate Shift Left | ROL (0x07)
Logical Shift Right | LSR (0x08)
Rotate Shift Right | ROR (0x09)
Arithmetic Shift Right | ASR (0x0a)
Return from Subroutine | RTS (0x31)
Push on Stack | PHS (0x2e)
Pull from Stack | PLS (0x2f)
description | no operand (A) | immediate | abs address | rel address | word at abs adr | (SP + rel offset)
Branch on Carry Set | | | BCS (0x3d)
Branch on Carry Clear | | | BCC (0x3c)
Branch on minus | | | BMI (0x3f)
Branch on plus | | | BPL (0x3e)
Branch if Zero | | | BEQ (0x3b)
Branch if not Zero | | | BNE (0x3a)

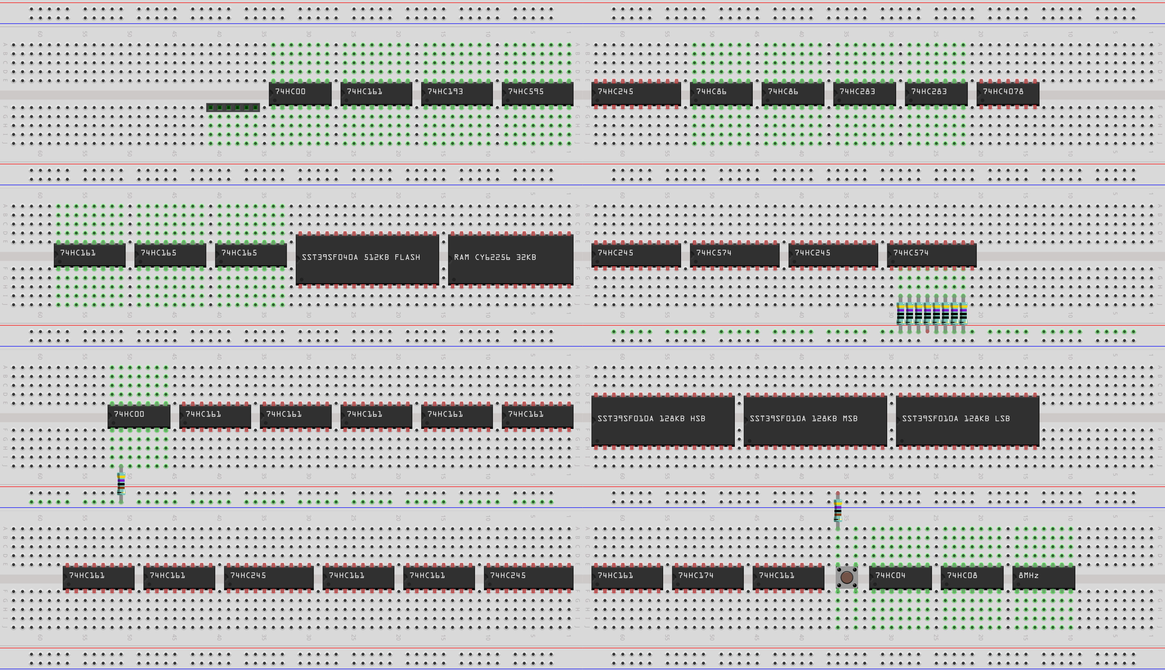
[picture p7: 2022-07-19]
Revisions 1.3 - 1.6 (FLASH)/Revision 1.6 (Redux)/Layout.jpg

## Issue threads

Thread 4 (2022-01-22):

Potential error in OS.TXT

paulscottrobson, 2022-01-22:
In the listing code the following sequence occurs :

```
listweiter:     INW OS_PtrA
                  DEB OS_Count
                  CPI 8 BNE notmiddle
                    JPS OS_PrintSpace               ; print an extra space after 8 bytes
  notmiddle:      CPI 0 BNE nextlist
                    JPS OS_PrintEnter

```
This works because RTS changes A to an undefined value, which could, theoretically be 0, though I think A is set to SP.Low so it's very unlikely :) It should probably skip out past the CPI 0 test.

Closed 2022-01-25.

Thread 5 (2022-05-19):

Why not use some on-board signal for flow control of the UART port?

NeoNatural, 2022-05-19:
Since this machine is of no UART interrupt or timer-based polling mechanism for RX, the programme should take full responsibility to read out the received byte before the next one coming in. This may constrain the programme staying within a polling loop for not missing any bytes. I think a hardware flow control signal like RTS/CTS may help avoid data loss while maintaining code flexibility (the PC terminal side is with much larger TX buffer than only one byte RX buffer on this board).

I guess 2 signals within the UART receiver block can server as the RTS: the output Q of the SR latch (marked with blue frame) or the DATA_READY (DR, marked with orange frame) signal. The former one turns High after the first falling edge of RX input while the latter one turns High after the entire byte being received. And they both will not turn Low unless the received byte is read out, which makes them suitable to act as the RTS flow control signal.
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

I will link these wires to the CTS pin of the serial adapter and check whether this would work (as soon as I receive the chips and PCB and build up this machine). Post this issue here for discussion first.

slu4coder, 2022-05-20:
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

Hi NeoNatural,

I've tried Q and DR as RTS and connected the signal to CTS of my FTDI interface with RTS/CTS handshaking enabled. This works well *in principle*, however, unfortunately if Q goes high at the start of a datum (DR does the same at the end of a datum), this does not prevent the sender from sending one more(!) datum. It seems to already be in the pipeline of my FTDI chip. This 2nd datum is too much for the single-byte buffer of the Minimal CPU if the CPU is busy and thus not constantly polling. So we have to stick to avoid that situation in software.

It's a bit of a pity, but this very nice idea does not work in practice - and this is not because of the Minimal CPU System but because the FTDI chip being as it is. Anyway, thanks a lot for thinking through this and for coming up with this plan.

Cheers,
slu4.

NeoNatural, 2022-05-28:
Hi! I'd like to make a supplement. I tried simulating the DR line of the UART receiver module, which turns high after receiving one datum. This could work (Figure 1), but the actual time delay should be considered further. Roughly speaking, if the RTS signal was given after  the half time of the stop bit, the second datum would not be blocked (Figure 2).

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

Closed 2022-05-20.

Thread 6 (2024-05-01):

ULTRA2.0: which flash goes with which file?

joelburton, 2024-05-01:
I've been assembling the v2 ULTRA of this, and am at the point of burning the flash chips to add them. Apologies if I'm missing something obvious, but I don't see which of U6/U12/U30 goes with which of the lsb/msb/hsb files. Any help would be appreciated!

(also: I've looked through the [very helpful!] docs, but those focus on v1.6 or before --- if I get this started up, what would the baud rate for the serial port be? 115200? Something else?)

Thanks, and thanks for all the videos and interesting designs, @slu4coder .

slu4coder, 2024-05-01:
Hi Joel,

please note that revision 2.0 was intended and released as a 'breadboard only' version to demonstrate higher clockrates (see my videos about it on YouTube). The PCB version is untested and was never released.

joelburton, 2024-05-01:
Ah! I hadn't realized that. I also had some of your 64x4 boards made, but I was going to make this first since I assumed it would be a bit easier to debug given that it doesn't have VGA/keyboard in the circuit.

Thanks for the help — and I'll let you know if the design works :)

Closed 2024-05-01.

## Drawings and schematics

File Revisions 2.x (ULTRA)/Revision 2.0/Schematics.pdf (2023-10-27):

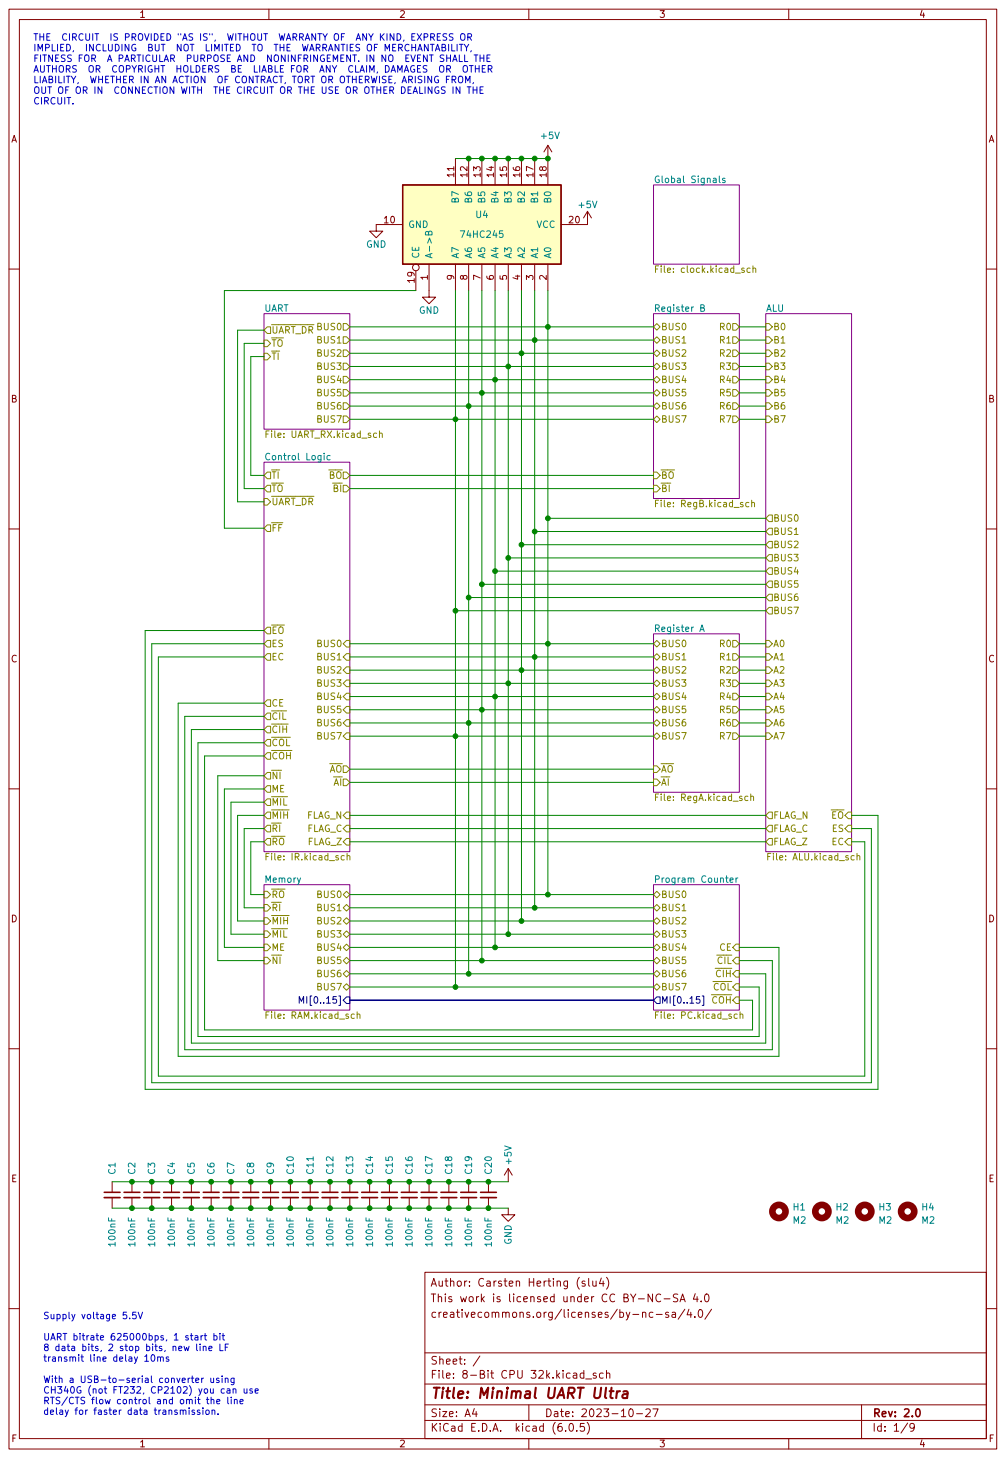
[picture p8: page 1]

THE CIRCUIT IS PROVIDED "AS IS", WITHOUT WARRANTY OF ANY KIND, EXPRESS OR
IMPLIED, INCLUDING BUT NOT LIMITED TO THE WARRANTIES OF MERCHANTABILITY, FITNESS FOR A PARTICULAR PURPOSE AND NONINFRINGEMENT. IN NO EVENT SHALL THE

AUTHORS OR COPYRIGHT HOLDERS BE LIABLE FOR ANY CLAIM, DAMAGES OR OTHER
LIABILITY, WHETHER IN AN ACTION OF CONTRACT, TORT OR OTHERWISE, ARISING FROM, OUT OF OR IN CONNECTION WITH THE CIRCUIT OR THE USE OR OTHER DEALINGS IN THE CIRCUIT.

Global Signals File: clock.kicad_sch BUS0 BUS1 BUS2 BUS3 BUS4 BUS5 ~{AI}

File: 8-Bit CPU 32k.kicad_sch Sheet: / creativecommons.org/licenses/by-nc-sa/4.0/ This work is licensed under CC BY-NC-SA 4.0 Author: Carsten Herting (slu4) BUS0 BUS1 BUS2 BUS3 BUS4 BUS5 BUS6 BUS7 ~{RO} ME
~{MIH}
~{MIL}

Program Counter File: PC.kicad_sch
~{COL} BUS3 BUS1 BUS0 BUS2 BUS4 BUS6 BUS7 BUS5 MI[0..15]

UART bitrate 625000bps, 1 start bit
8 data bits, 2 stop bits, new line LF
transmit line delay 10ms

With a USB-to-serial converter using
CH340G (not FT232, CP2102) you can use RTS/CTS flow control and omit the line

Id: 1/9 Title: Minimal UART Ultra

delay for faster data transmission.

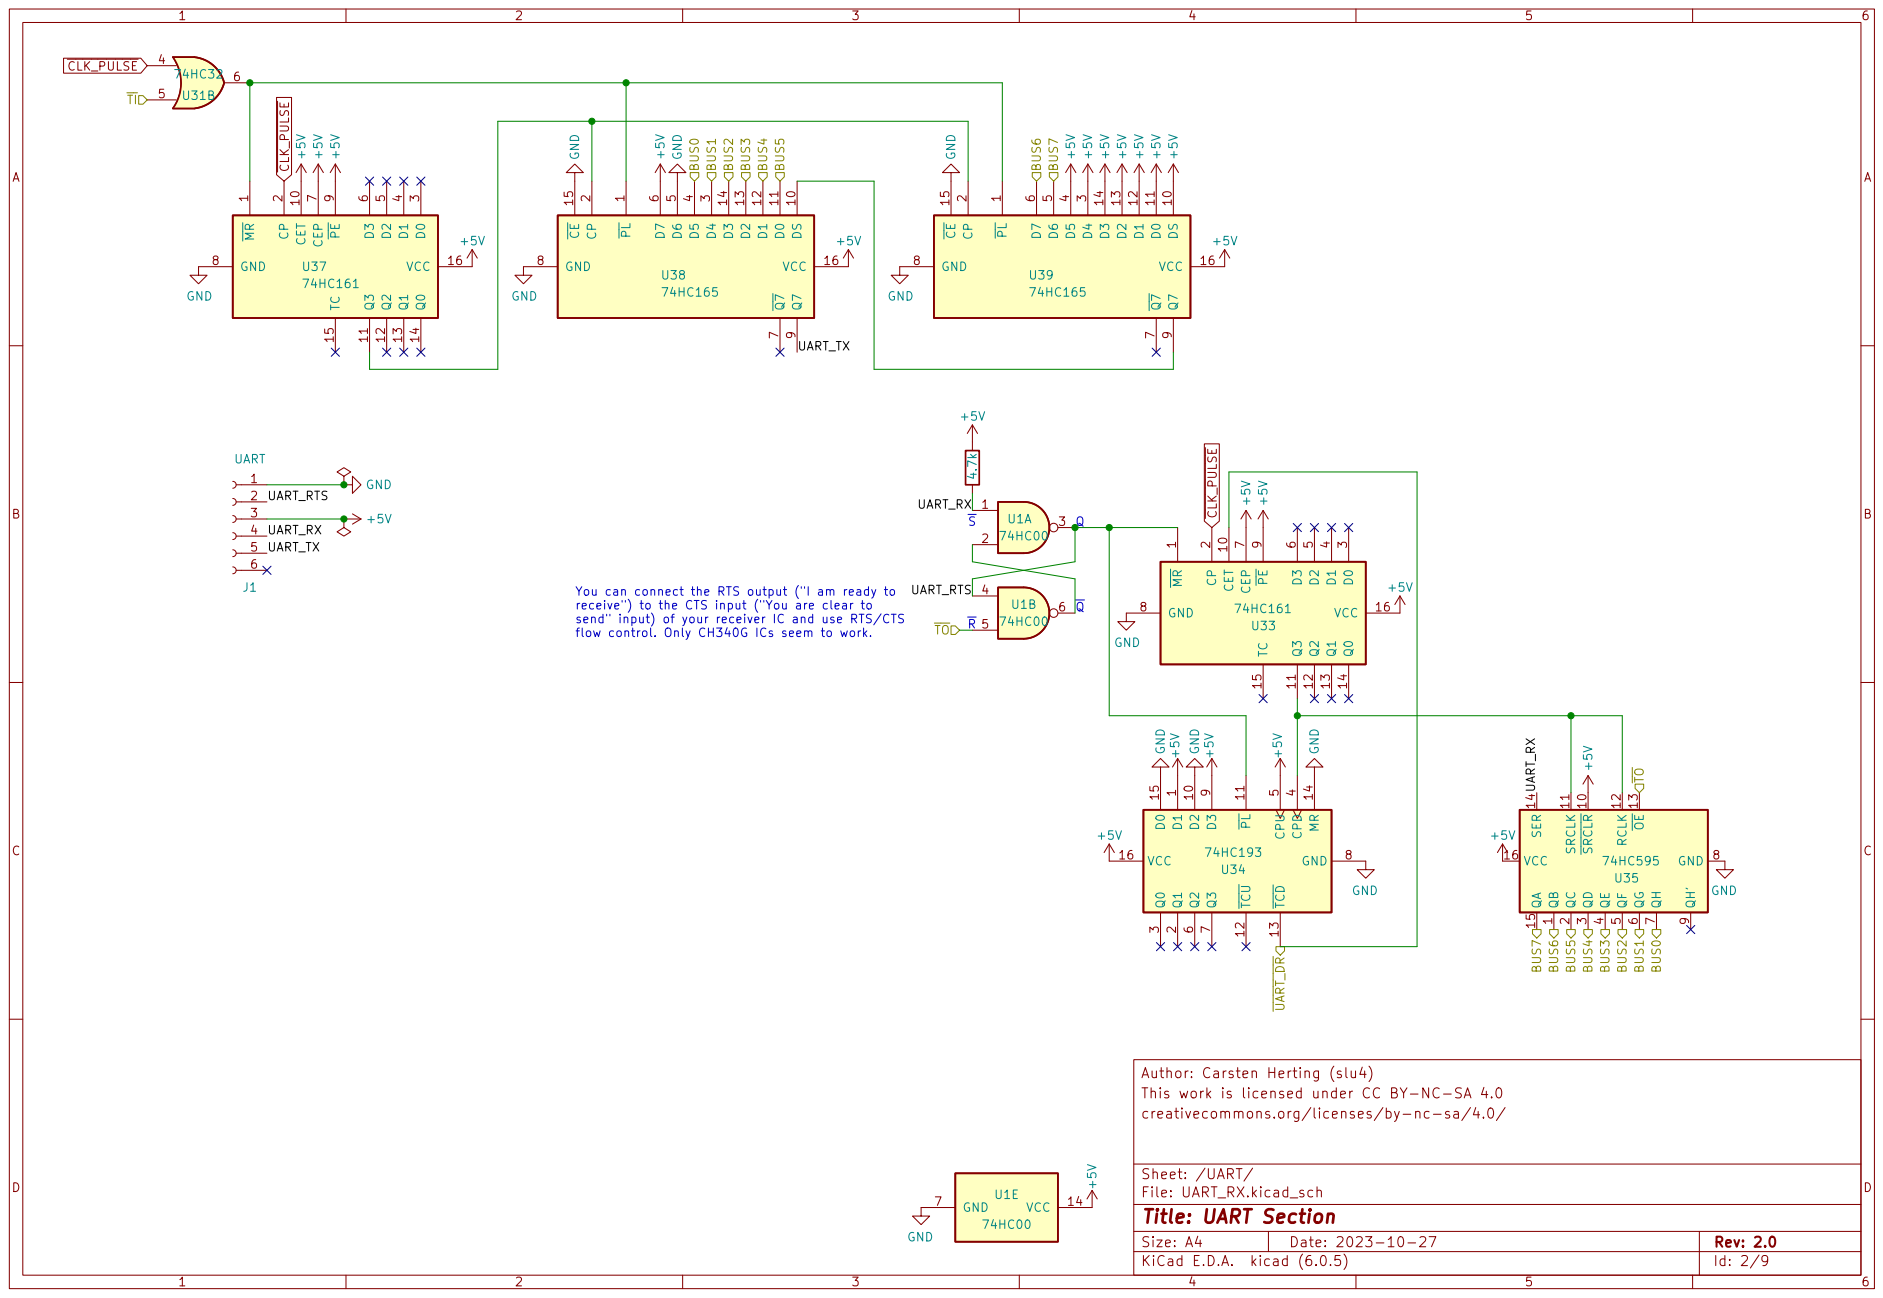
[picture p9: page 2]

1 DS 10 D0 11 D1 12 D2 13 D3 14 ~{CE} 15 VCC 16 CP

You can connect the RTS output ("I am ready to
receive") to the CTS input ("You are clear to
send" input) of your receiver IC and use RTS/CTS
flow control. Only CH340G ICs seem to work.

1 D2 10 ~{PL} 11 ~{TCU} 12 ~{TCD} 13 MR 14 D0 15 VCC 16 Q1

1 ~{SRCLR}10 SRCLK 11 RCLK 12 ~{OE}13 SER 14 QA 15 VCC 16 QC

File: UART_RX.kicad_sch Sheet: /UART/ creativecommons.org/licenses/by-nc-sa/4.0/ This work is licensed under CC BY-NC-SA 4.0 Author: Carsten Herting (slu4)

Id: 2/9 Title: UART Section

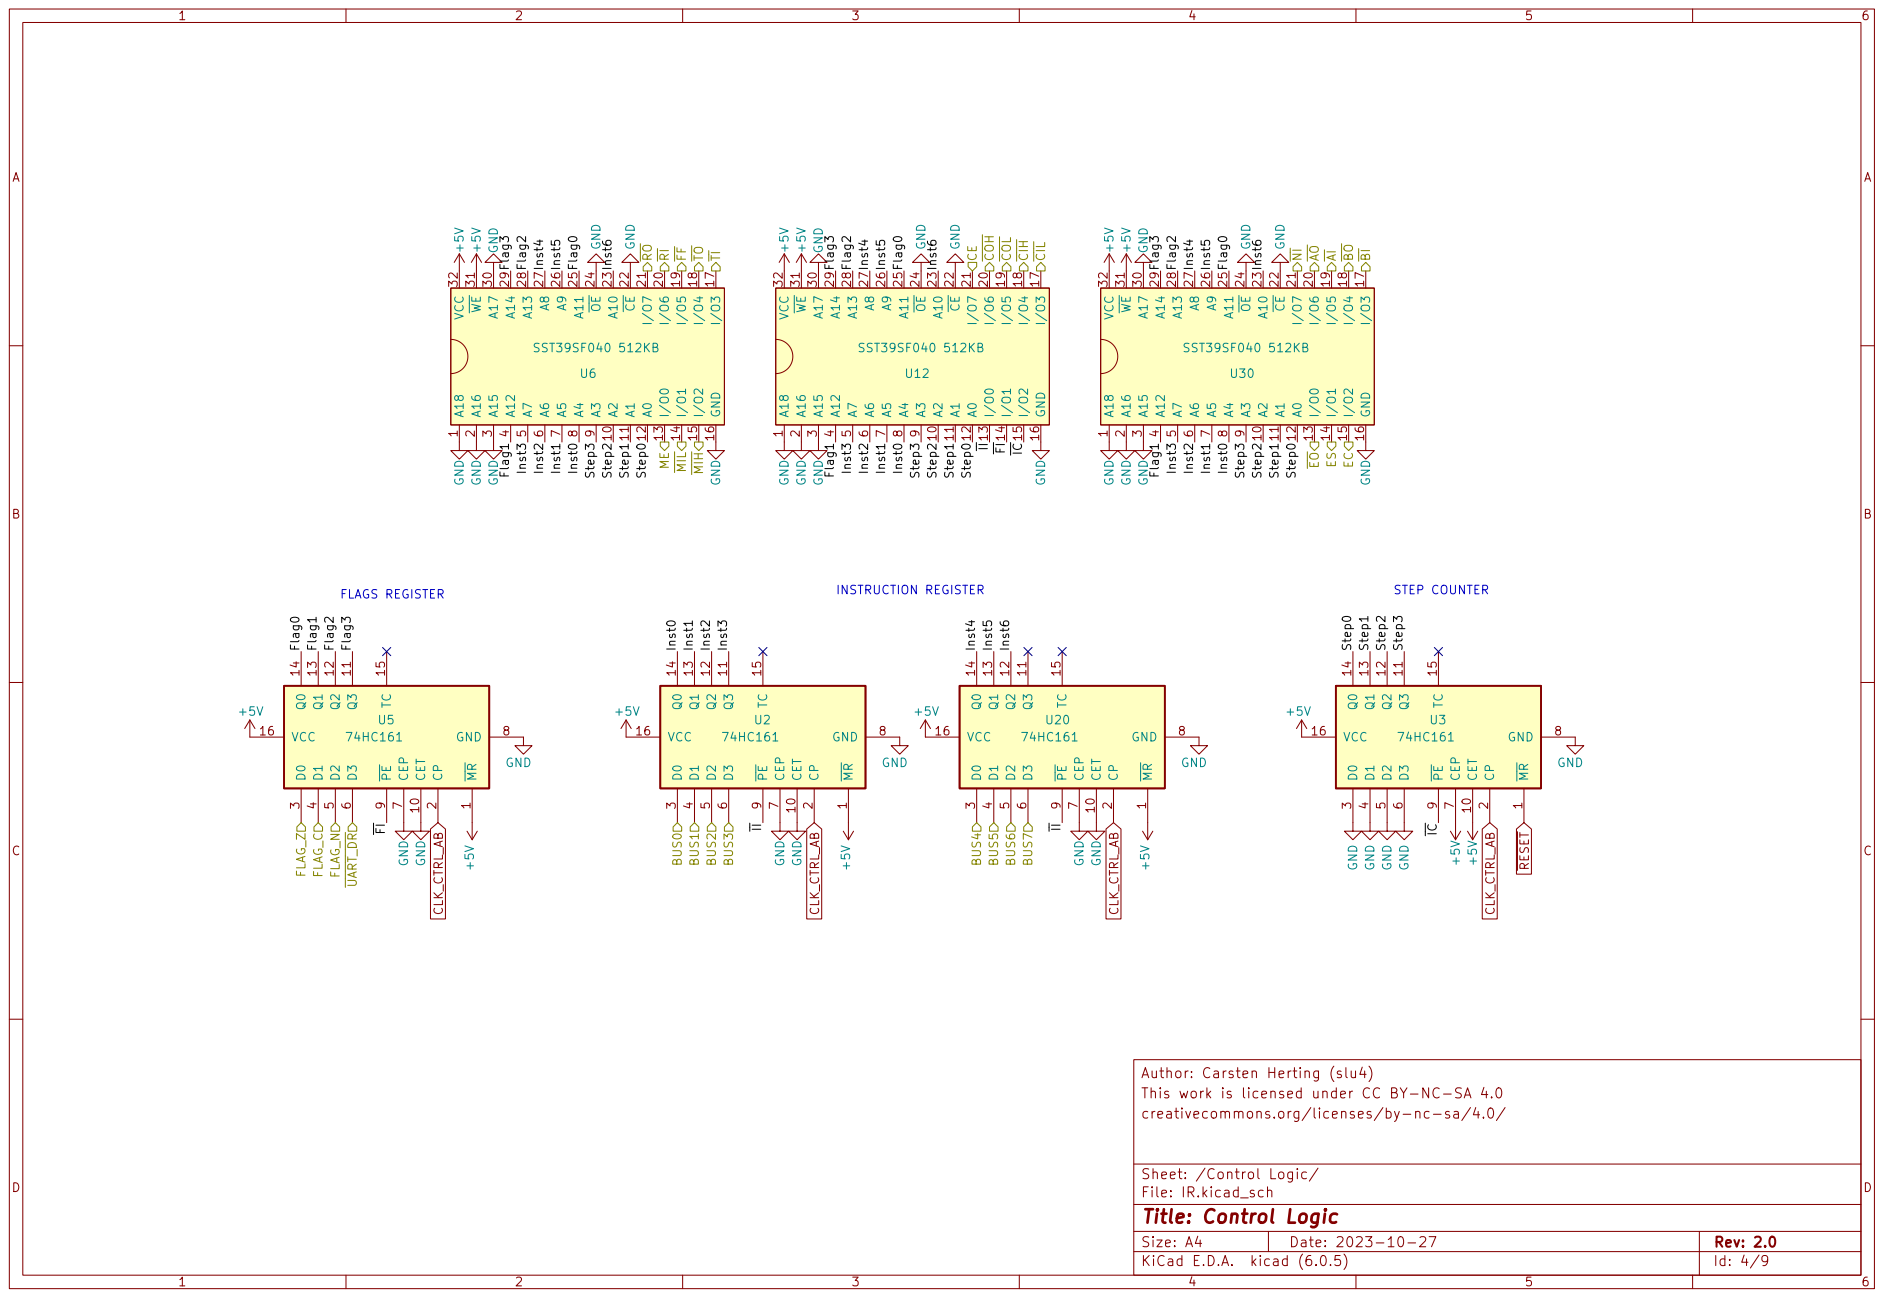
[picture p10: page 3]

9 U30 SST39SF040 512KB GND GND GND GND GND CE~{AI} ~{BO} BUS5 BUS6 ~{RO} ~{RI} ~{FF} ~{TO} ~{TI} ~{CIH} ~{NI} ~{MIH} ME ~{UART_DR} ~{COH} ~{MIL} EC ~{COL} BUS0 BUS1 BUS2 BUS3 BUS4 ~{CIL} ~{AO} ~{BI} ~{EO} ES FLAG_C BUS7 FLAG_Z FLAG_N CLK_CTRL_AB ~{RESET} CLK_CTRL_AB CLK_CTRL_AB CLK_CTRL_AB Flag0 Flag1 Flag2 Flag3 Flag1 Inst3 Inst2 Inst1 Inst0 ~{II} Inst4 Inst5 Flag0 Inst6 Step0 Inst5 ~{FI} Flag3 Flag2 Inst4 Flag0 Step2 Step1 Step0~{II} Step3 Inst2 Inst1 Inst0 Flag3 Flag2 Inst5 Flag0 Flag1 Inst5 Inst3 Inst0 Inst1 Inst2 Inst3 Inst4 Inst6 Inst3 Inst2 Inst0 ~{IC} Inst6 Step1 Step0 Inst1 Step2 Flag1 Step3 Step2 Step0 Step1 Step2 Step3 ~{IC} Step3 Step1 ~{II} Flag3 Flag2 Inst4 Inst6 ~{FI}

9 U6 SST39SF040 512KB GND GND GND +5V GND +5V +5V GND A18

creativecommons.org/licenses/by-nc-sa/4.0/ This work is licensed under CC BY-NC-SA 4.0 Author: Carsten Herting (slu4) GND

Sheet: /Control Logic/
File: IR.kicad_sch
Id: 4/9 Title: Control Logic

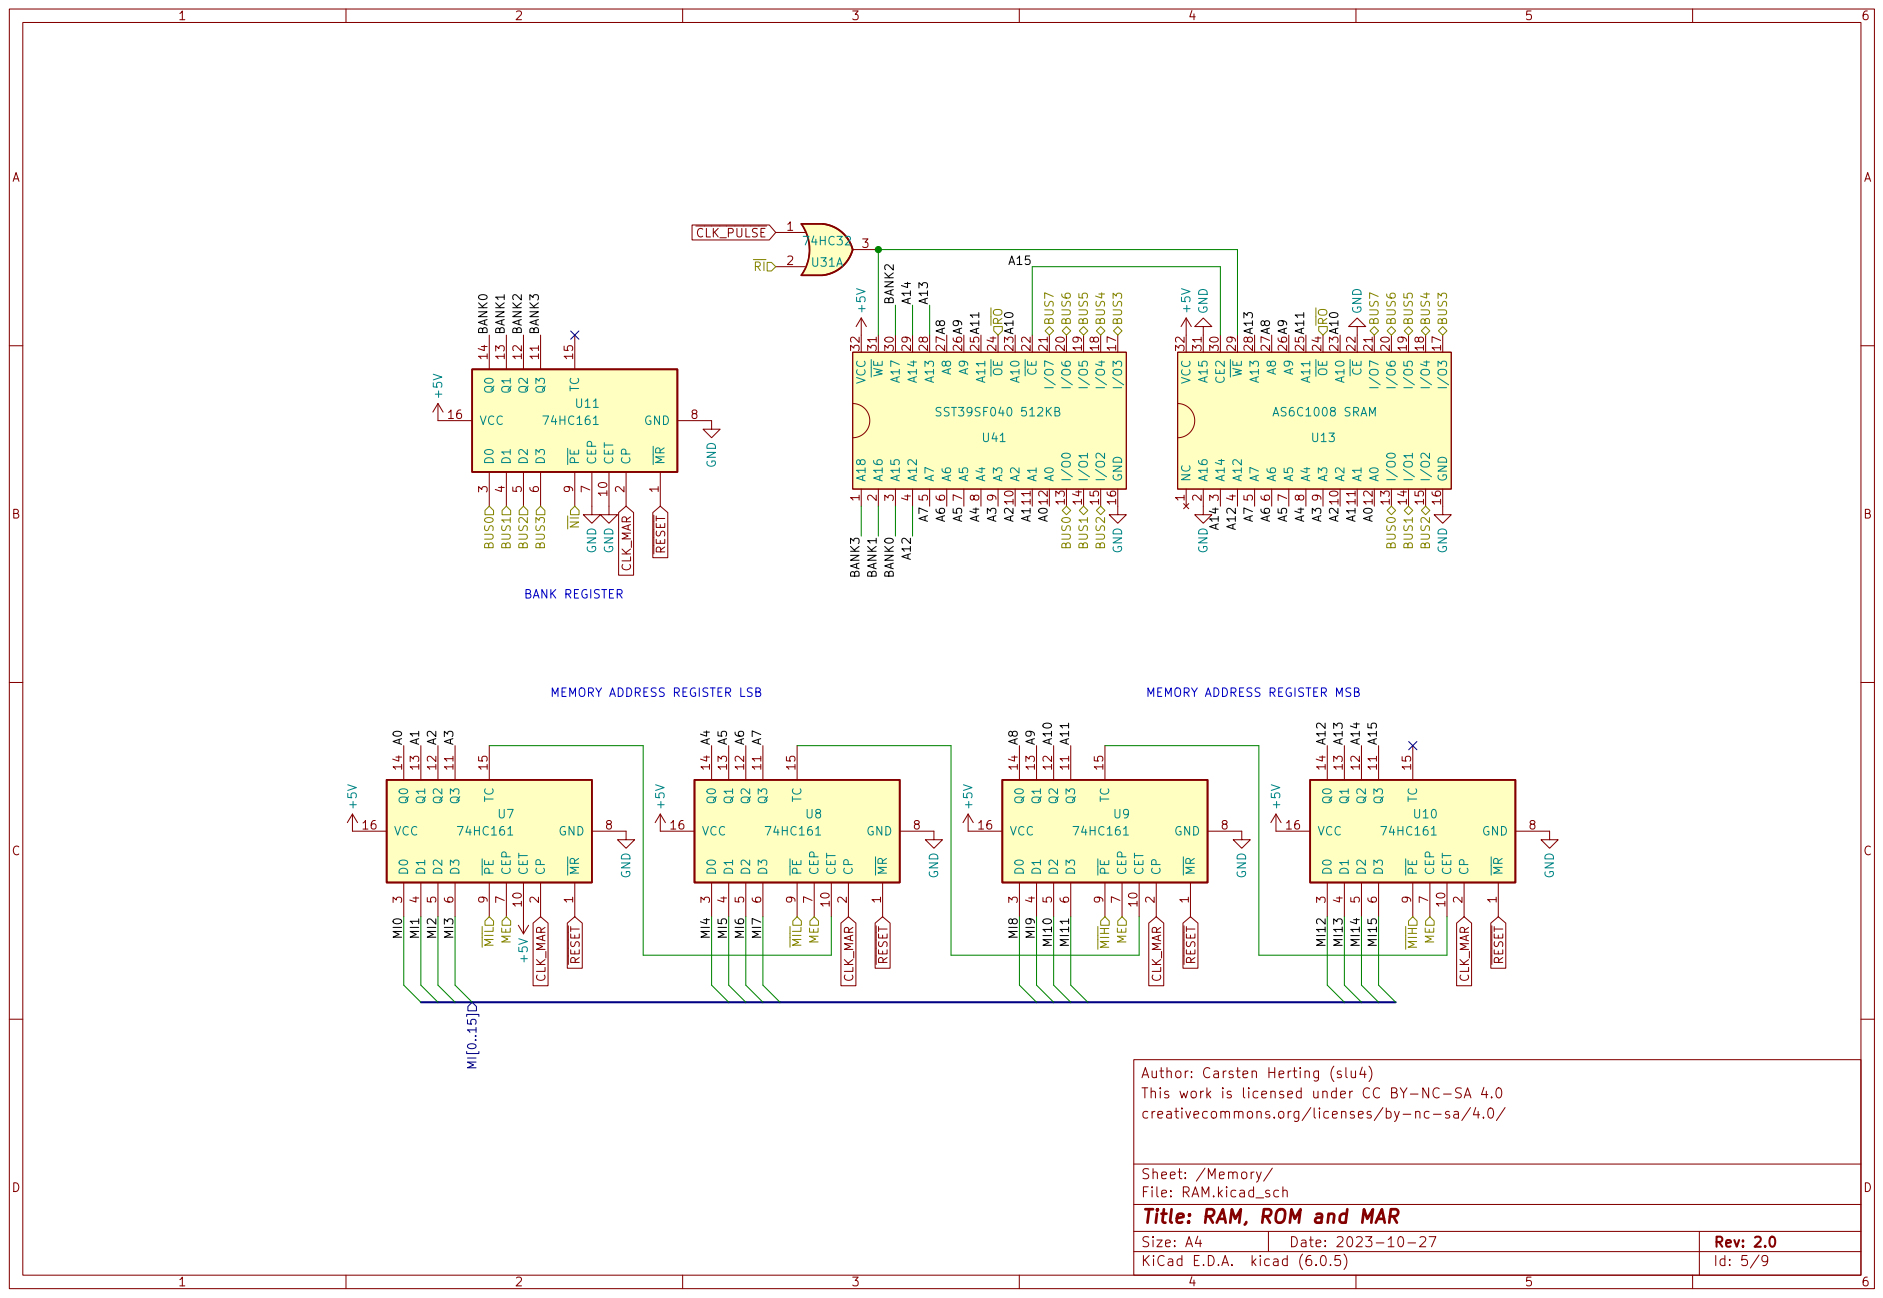
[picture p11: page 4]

9 U13 AS6C1008 SRAM GND GND ~{MR} 1 CET 10 Q3 11 Q2 12 Q1 13 Q0 14 TC 15 VCC 16 CP

9 U41 SST39SF040 512KB +5V ~{MR} 1 CET 10 Q3 11 Q2 12 Q1 13 Q0 14 TC 15 VCC 16 CP

1 CET 10 Q3 11 Q2 12 Q1 13 Q0 14 TC 15 VCC 16 CP

Sheet: /Memory/
File: RAM.kicad_sch
Id: 5/9 Title: RAM, ROM and MAR

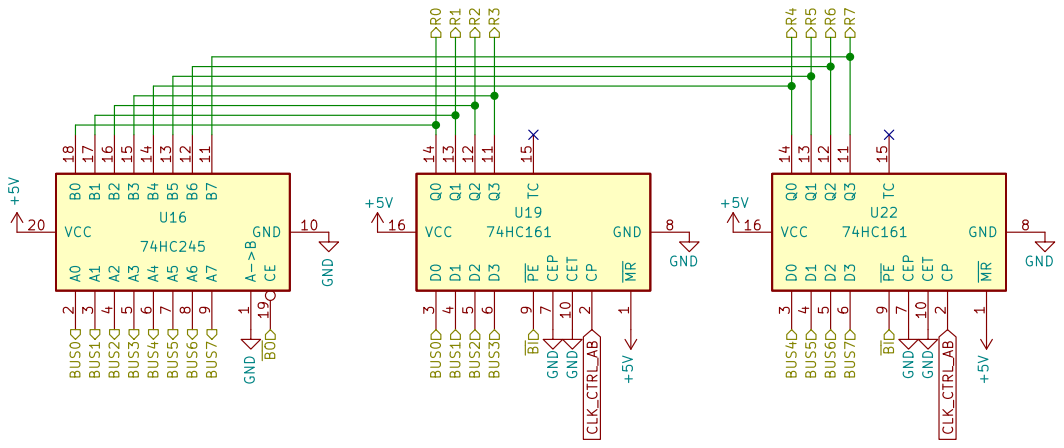
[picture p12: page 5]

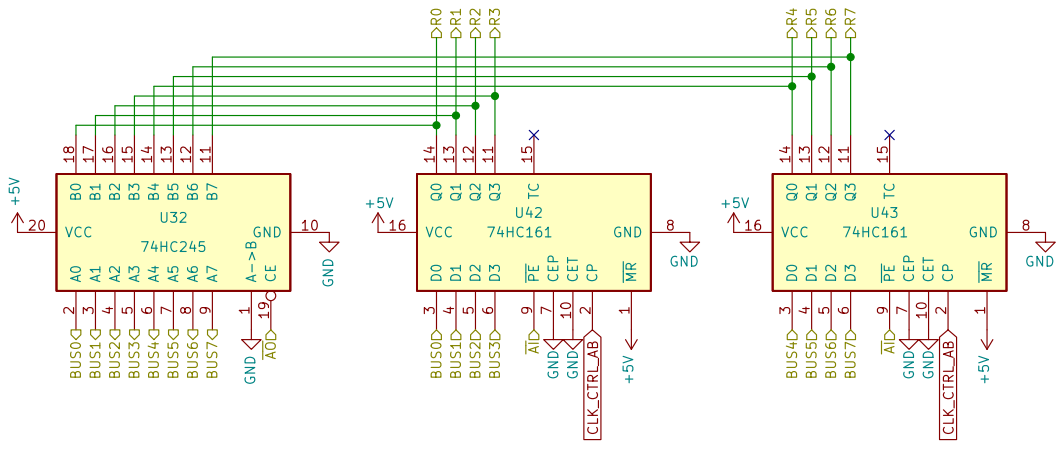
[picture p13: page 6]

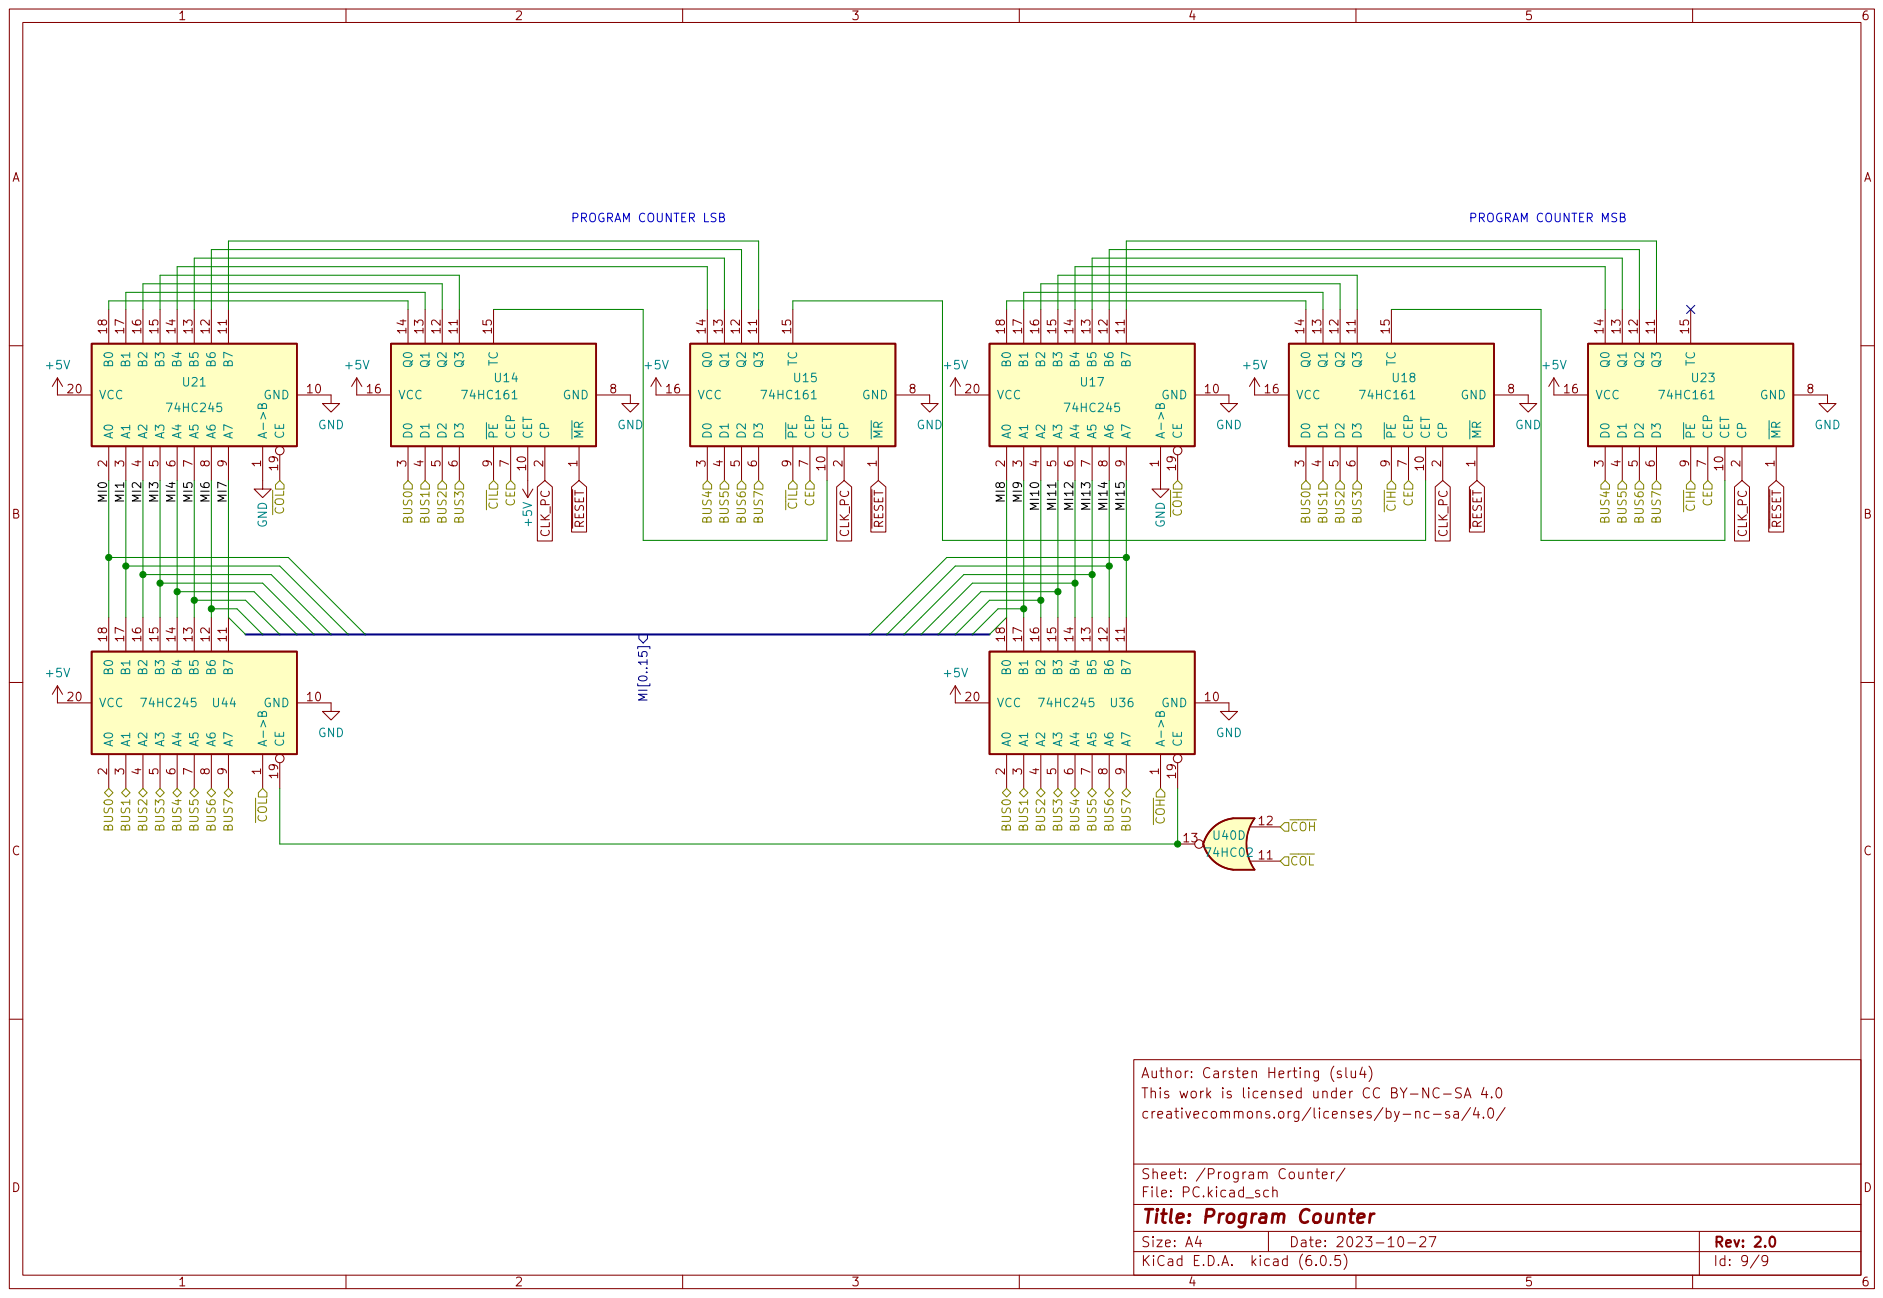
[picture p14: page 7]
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

Sheet: /Program Counter/
File: PC.kicad_sch
Id: 9/9 Title: Program Counter

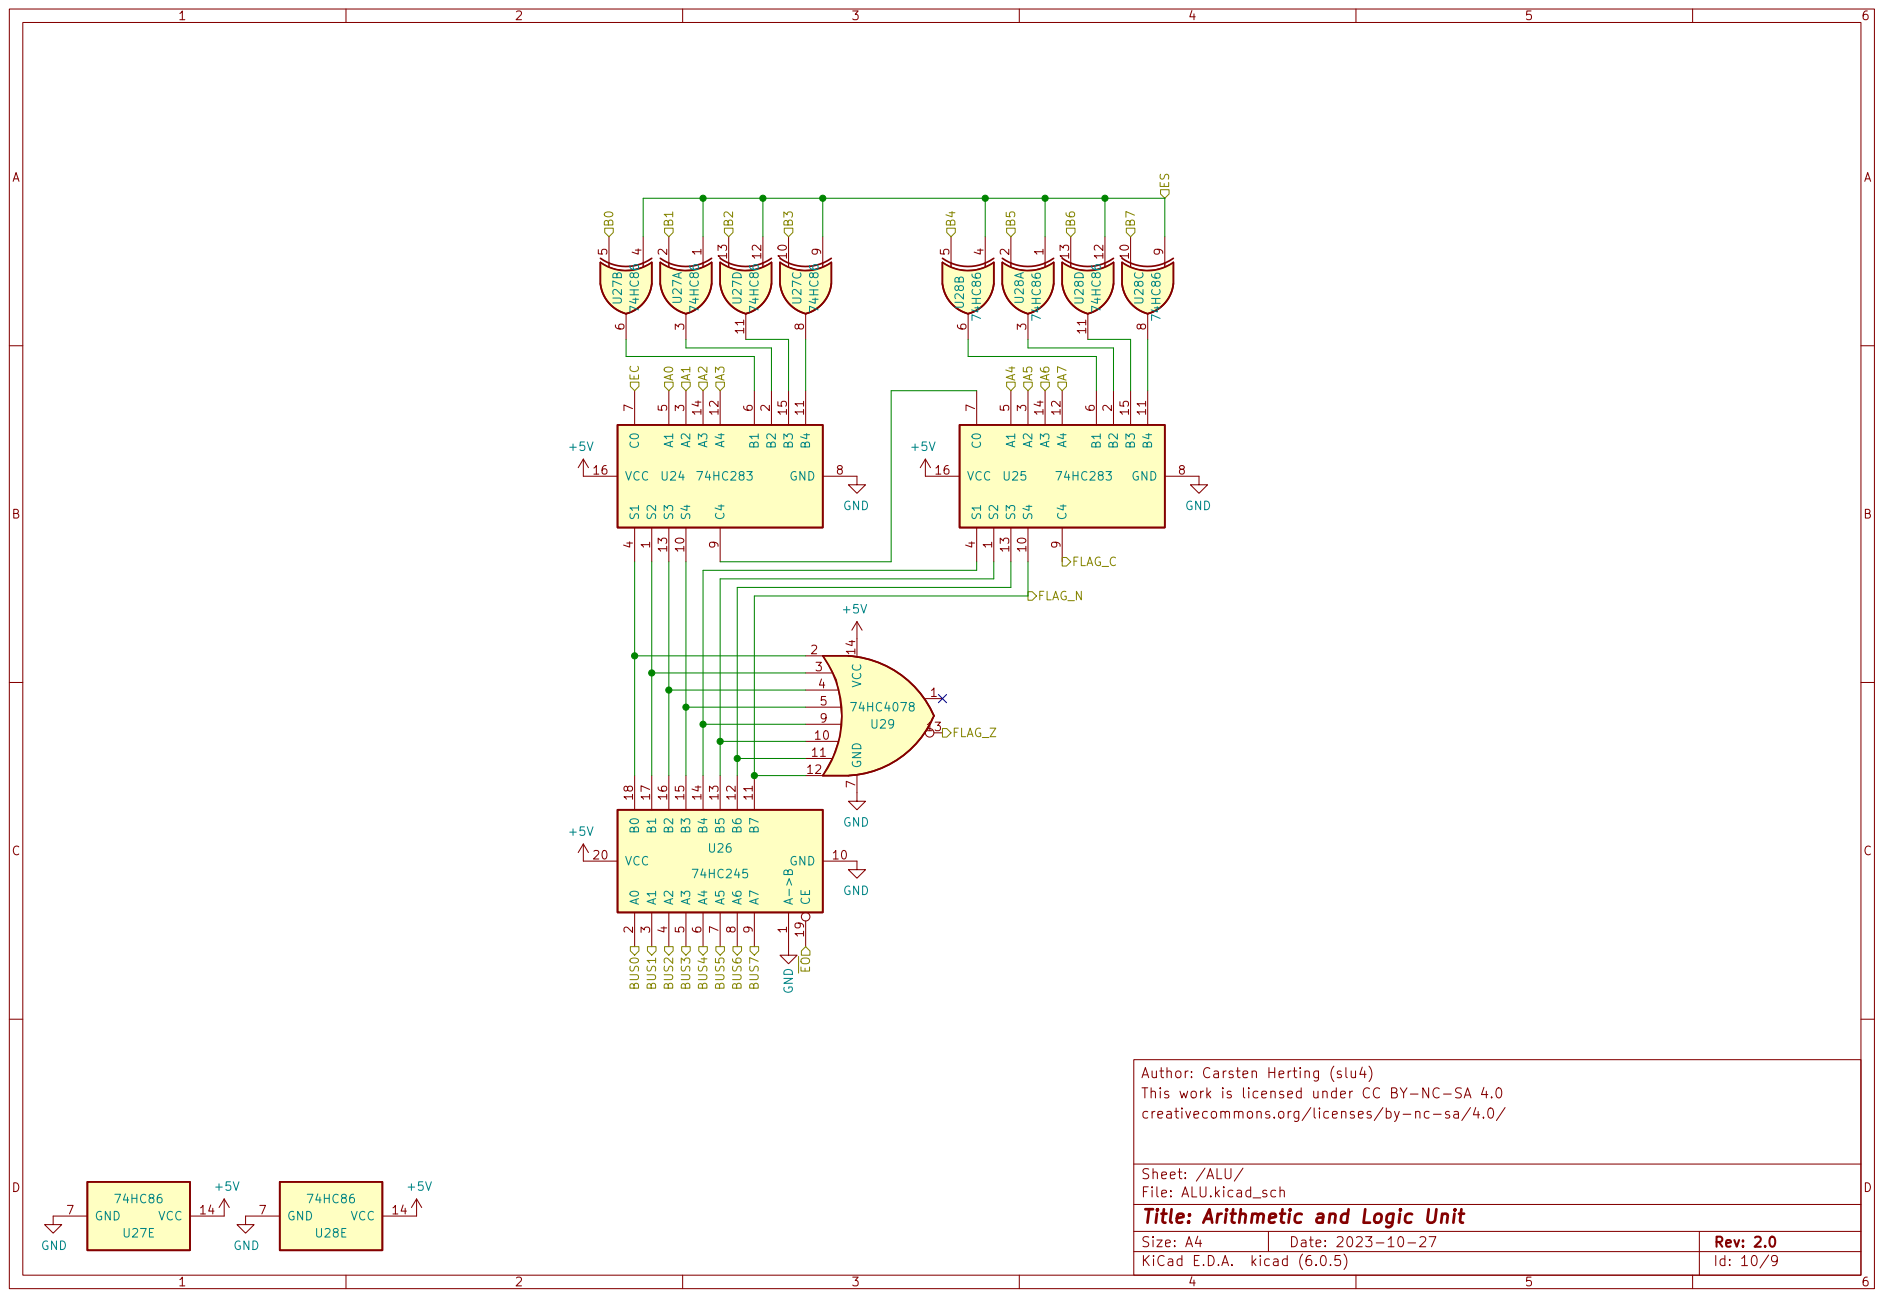
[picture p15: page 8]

Id: 10/9 Title: Arithmetic and Logic Unit

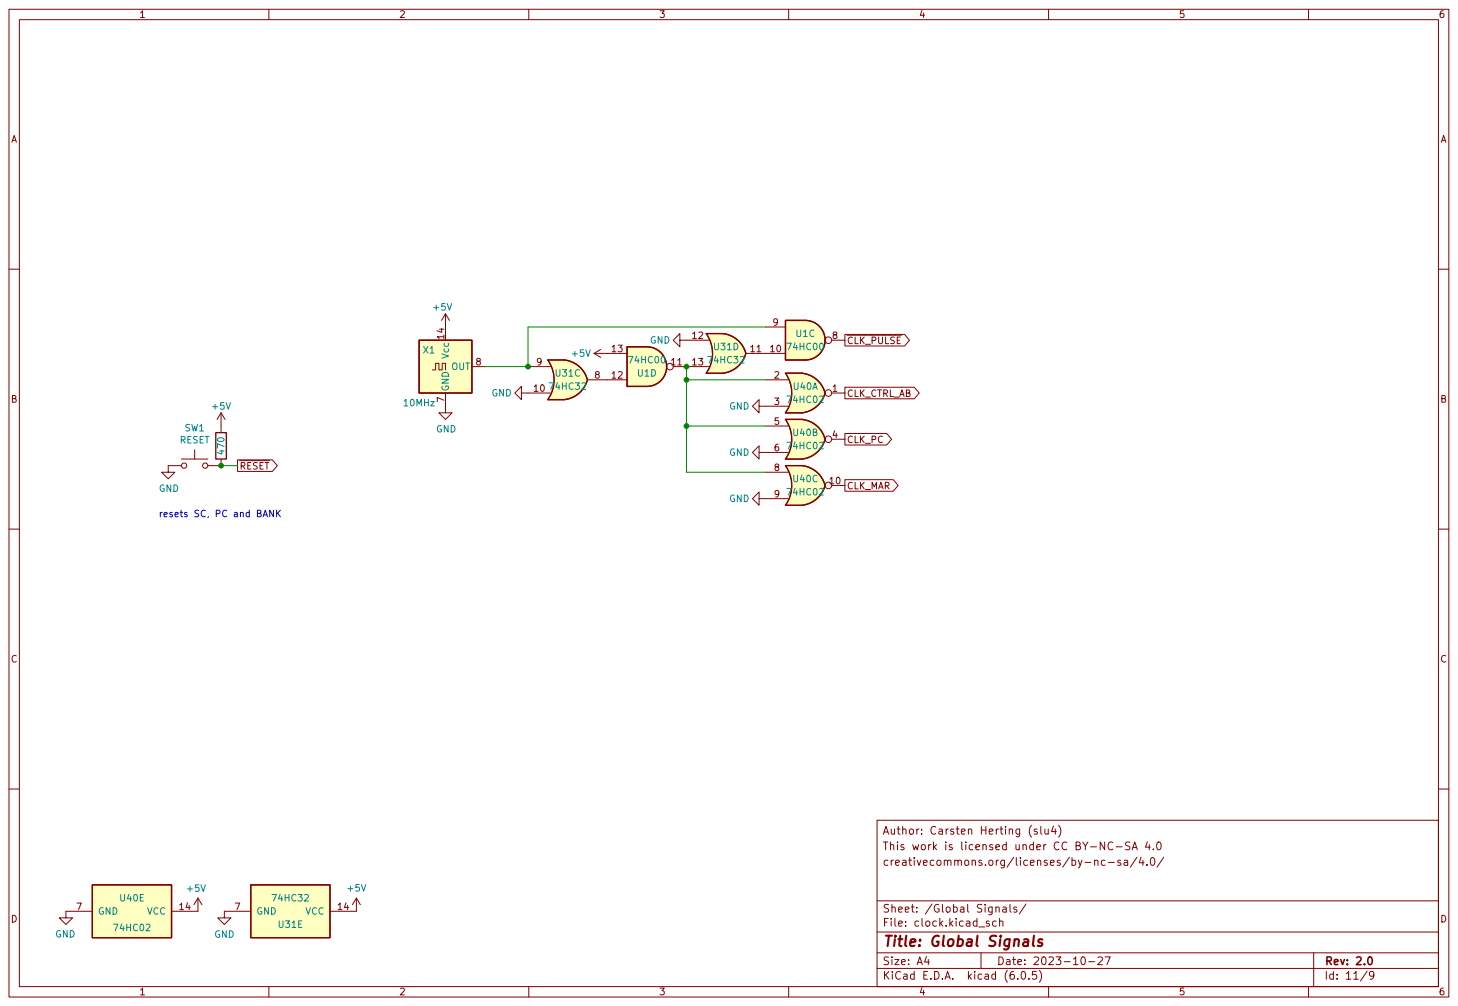
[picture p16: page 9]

creativecommons.org/licenses/by-nc-sa/4.0/ This work is licensed under CC BY-NC-SA 4.0 Author: Carsten Herting (slu4) Vcc 14 GND

resets SC, PC and BANK

Sheet: /Global Signals/
File: clock.kicad_sch
Id: 11/9 Title: Global Signals

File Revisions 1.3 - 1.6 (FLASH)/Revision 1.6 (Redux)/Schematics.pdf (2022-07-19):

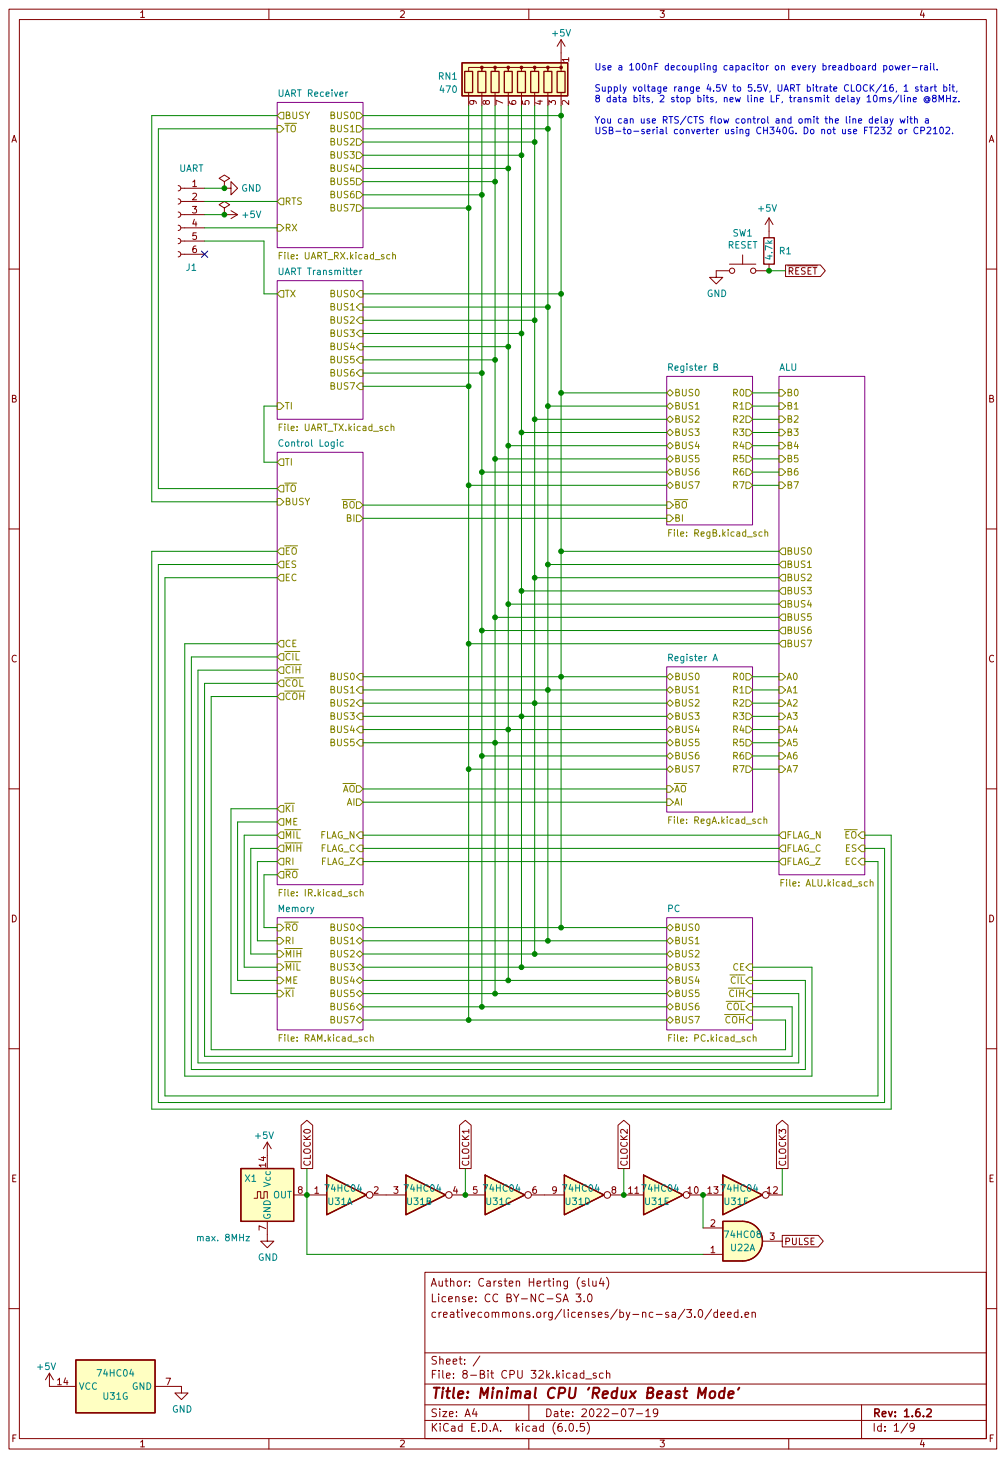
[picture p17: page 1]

TI UART Transmitter File: UART_TX.kicad_sch BUS0 BUS1 BUS2 BUS3 BUS4 BUS5 BUS6 BUS7 ~{TO} RX

Use a 100nF decoupling capacitor on every breadboard power-rail.

Supply voltage range 4.5V to 5.5V, UART bitrate CLOCK/16, 1 start bit,
8 data bits, 2 stop bits, new line LF, transmit delay 10ms/line @8MHz.

You can use RTS/CTS flow control and omit the line delay with a
USB-to-serial converter using CH340G. Do not use FT232 or CP2102.

~{CIH} CERI ME Control Logic File: IR.kicad_sch BUS0 BUS1 BUS2 BUS3 BUS4 BUS5 BUS6 BUS7 ~{RO} ME
TI ~{TO} BUSY

File: RegB.kicad_sch BUS0 BUS1 BUS2 BUS3 BUS4 BUS5AI ~{AO} BI ~{BO}

License: CC BY-NC-SA 3.0 Author: Carsten Herting (slu4)

File: 8-Bit CPU 32k.kicad_sch Sheet: / creativecommons.org/licenses/by-nc-sa/3.0/deed.en

Id: 1/9 Title: Minimal CPU 'Redux Beast Mode'

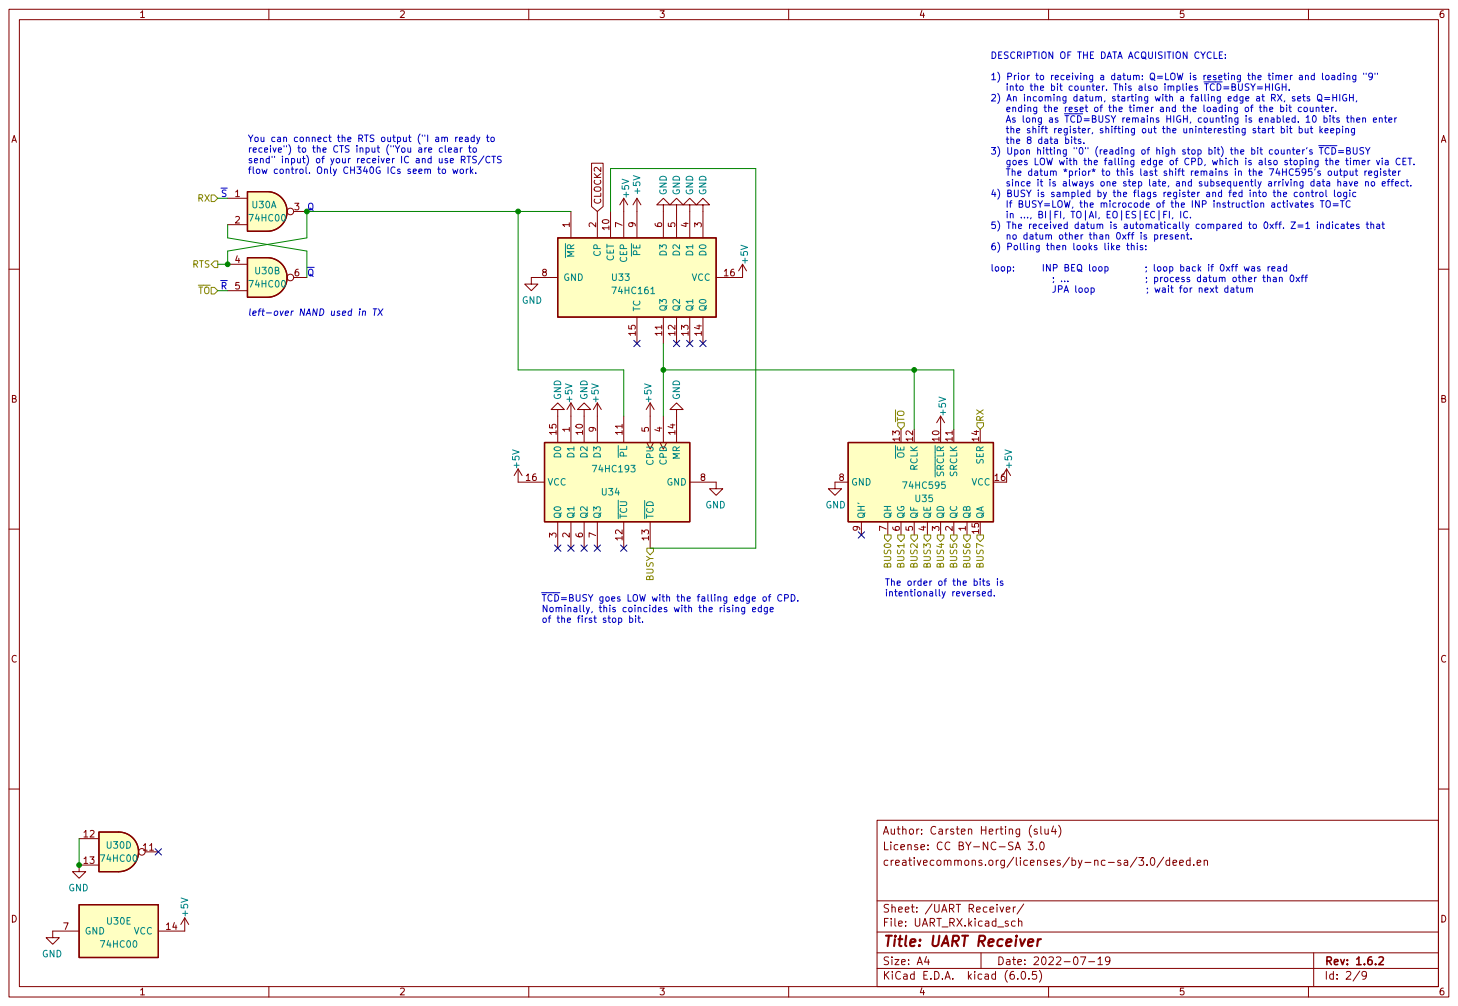
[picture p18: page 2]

into the bit counter. This also implies ~{TCD}=BUSY=HIGH.
2) An incoming datum, starting with a falling edge at RX, sets Q=HIGH,
ending the reset of the timer and the loading of the bit counter.
As long as ~{TCD}=BUSY remains HIGH, counting is enabled. 10 bits then enter
the shift register, shifting out the uninteresting start bit but keeping
the 8 data bits. 3) Upon hitting "0" (reading of high stop bit) the bit counter's ~{TCD}=BUSY

You can connect the RTS output ("I am ready to
receive") to the CTS input ("You are clear to
send" input) of your receiver IC and use RTS/CTS
flow control. Only CH340G ICs seem to work.

goes LOW with the falling edge of CPD, which is also stoping the timer via CET.
The datum *prior* to this last shift remains in the 74HC595's output register
since it is always one step late, and subsequently arriving data have no effect.
4) BUSY is sampled by the flags register and fed into the control logic
If BUSY=LOW, the microcode of the INP instruction activates TO=TC
5) The received datum is automatically compared to 0xff. Z=1 indicates that
no datum other than 0xff is present.
6) Polling then looks like this:

left-over NAND used in TX

License: CC BY-NC-SA 3.0 Author: Carsten Herting (slu4) +5V GND

1 D2 10 ~{PL} 11 ~{TCU} 12 ~{TCD} 13 MR 14 D0 15 VCC 16 Q1

1 ~{SRCLR}10 SRCLK 11 RCLK 12 ~{OE}13 SER 14 QA 15 VCC 16 QC

The order of the bits is
intentionally reversed.

~{TCD}=BUSY goes LOW with the falling edge of CPD.
Nominally, this coincides with the rising edge
of the first stop bit.

File: UART_RX.kicad_sch Sheet: /UART Receiver/ creativecommons.org/licenses/by-nc-sa/3.0/deed.en

Id: 2/9 Title: UART Receiver

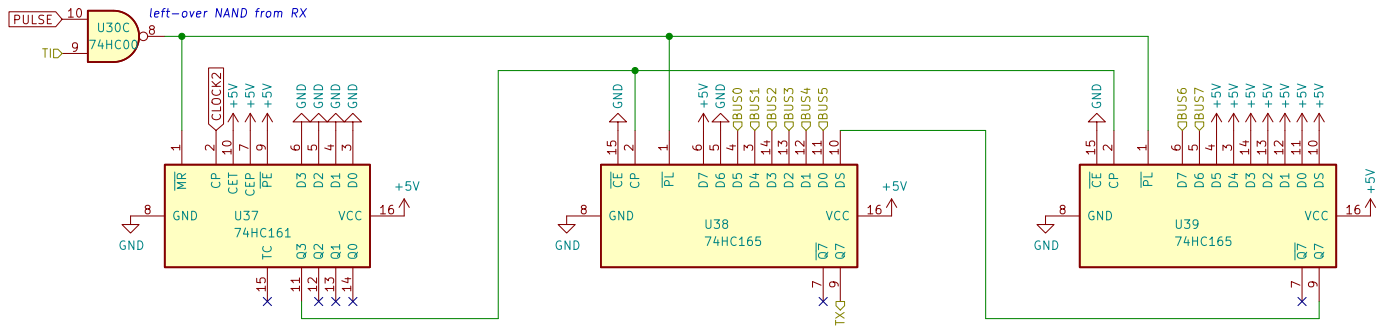
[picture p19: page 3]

File: UART_TX.kicad_sch Sheet: /UART Transmitter/ creativecommons.org/licenses/by-nc-sa/3.0/deed.en

Id: 3/9 Title: UART Transmitter


9 U5 SST39SF010A MSB GND~{EO} ES ~{MIH} ME ~{MIL} EC CE~{COH} ~{COL} ~{CIL} ~{BO} BI ~{AO} ~{KI} ~{RO} RI ~{TO} TI AI BUS0 BUS1 BUS2 BUS3 BUS4 BUS5 FLAG_Z FLAG_C BUSY FLAG_N ~{CIH} CLOCK0 ~{RESET} CLOCK0 PULSE Flag1 Inst3 Step3 Step2 Inst2 Inst1 Inst0 Flag3 Inst4 Inst5 Flag1 Flag0 Step1 Step0 Flag1 Flag0 II Step0 ~{FI} ~{IC} Step2 Step1 Step0 Flag2 Step1 Inst0 Inst5 Inst3 Inst2 Inst1 Step3 Inst0 Step3 Step2 Inst1 ~{IC} Flag0 Flag1 Flag2 Flag3 Inst0 Inst2 Inst3 Inst4 Inst5 Step0 Step1 Flag3 II Flag3 Inst4 Inst1 Flag2 ~{FI} Inst4 Flag2 Inst3 Inst2 Inst5 Flag0 Step2 Step3
License: CC BY-NC-SA 3.0 Author: Carsten Herting (slu4) NC

9 U6 SST39SF010A LSB GND +5V +5V GND GND GND GND GND +5V ~{MR} 1 CET 10 Q3 11 Q2 12 Q1 13 Q0 14 TC 15 VCC 16 CP

creativecommons.org/licenses/by-nc-sa/3.0/deed.en

Sheet: /Control Logic/
File: IR.kicad_sch
Id: 4/9 Title: Control Logic


The expansion port pinout
is included here just for
completeness. It may not
be sensible to implement

9 EXPANSION PORT GND GND +5V GND A18

2 ~{CE} 20 A0 21 ~{OE} 22 A1 23 A2 24 A3 25 A4 26 ~{WE} 27 VCC 28 A7

and PC=0. This ensures that after COL|MIL and COH|MIH also MAR=0. MEMORY ADDRESS REGISTER LSB

A MAR reset is not needed: While ~{RESET}
is pressed, the clock runs with Step=0

creativecommons.org/licenses/by-nc-sa/3.0/deed.en

Sheet: /Memory/
File: RAM.kicad_sch
Id: 5/9 Title: RAM, ROM and MAR


License: CC BY-NC-SA 3.0 Author: Carsten Herting (slu4) OE

creativecommons.org/licenses/by-nc-sa/3.0/deed.en


creativecommons.org/licenses/by-nc-sa/3.0/deed.en


License: CC BY-NC-SA 3.0 Author: Carsten Herting (slu4) GND

File: PC.kicad_sch Sheet: /PC/ creativecommons.org/licenses/by-nc-sa/3.0/deed.en
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






























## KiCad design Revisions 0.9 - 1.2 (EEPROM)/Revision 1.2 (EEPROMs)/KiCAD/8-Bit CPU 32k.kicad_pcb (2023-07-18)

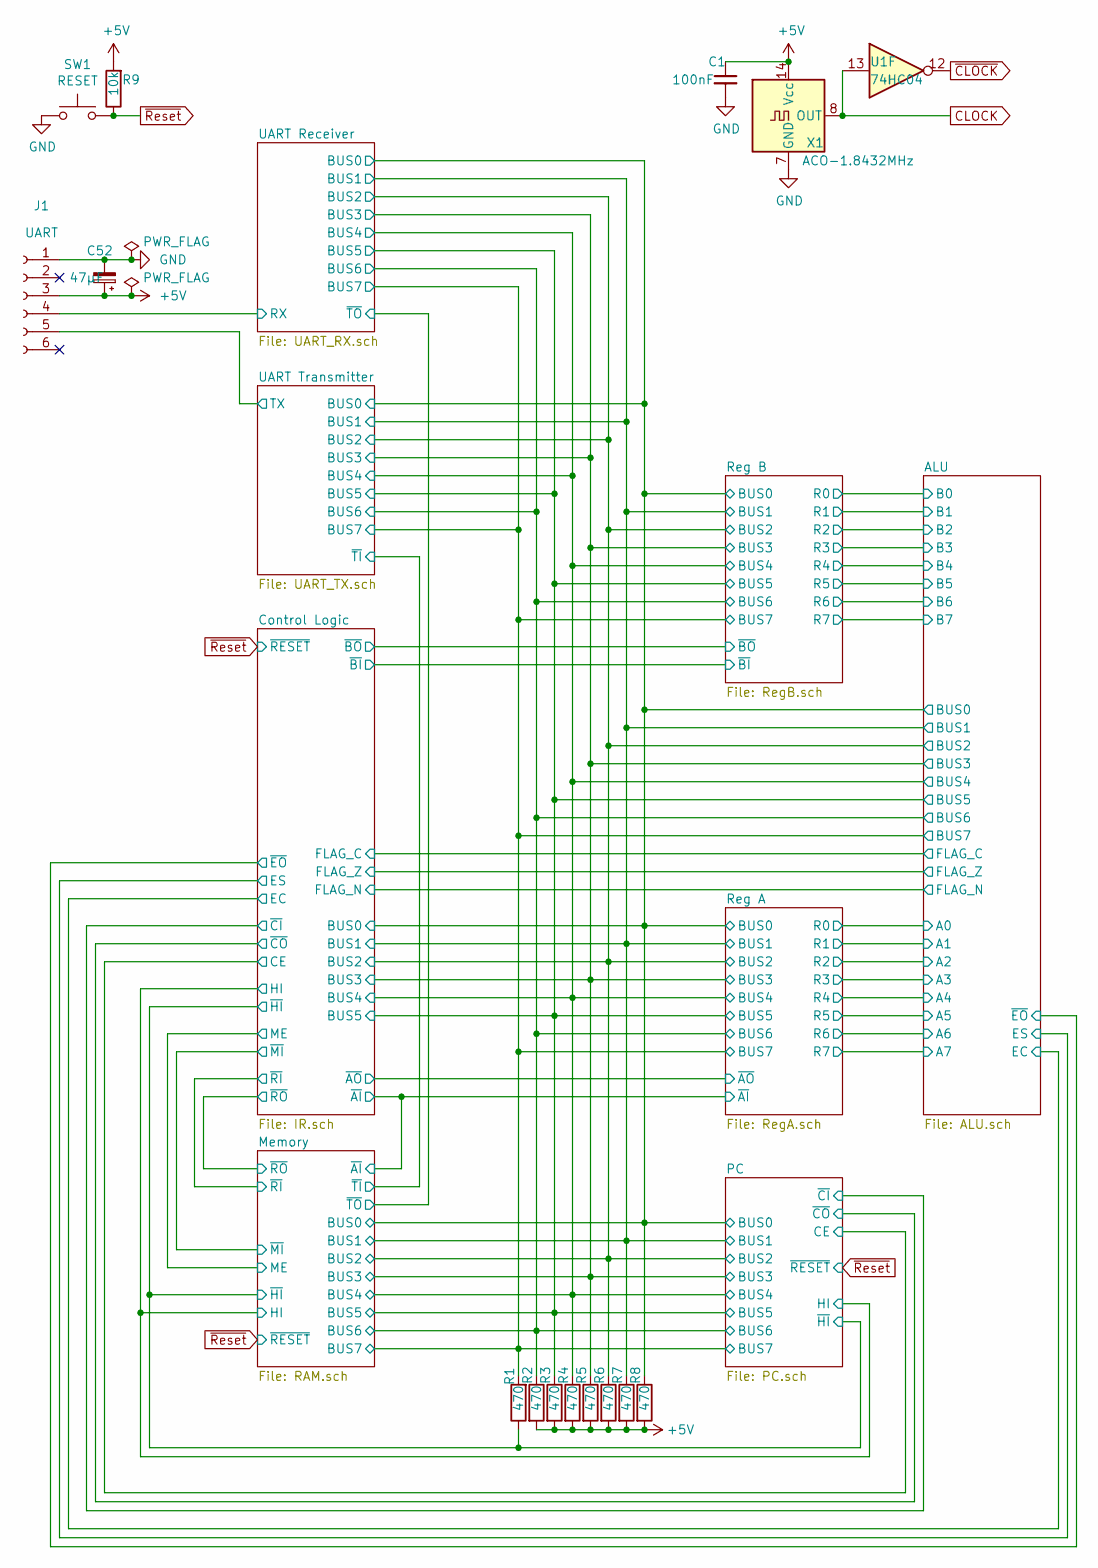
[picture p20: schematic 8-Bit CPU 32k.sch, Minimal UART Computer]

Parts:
C1: 100nF; C_Disc_D5.0mm_W2.5mm_P2.50mm
C52: 47µF; CP_Radial_D7.5mm_P2.50mm
J1: UART; PinSocket_1x06_P2.54mm_Vertical
R1, R2, R3, R4, R5, R6, R7, R8: 470; R_Axial_DIN0207_L6.3mm_D2.5mm_P7.62mm_Horizontal
R9: 10k; R_Axial_DIN0207_L6.3mm_D2.5mm_P7.62mm_Horizontal
SW1: RESET; SW_PUSH_6mm
U1: 74HC04; DIP-14_W7.62mm
X1: ACO-1.8432MHz; Oscillator_DIP-14

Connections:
+5V: C1.1, C52.1, J1.3, R2.2, R3.2, R4.2, R5.2, R6.2, R7.2, R8.2, R9.2, X1.14 (Vcc); also elsewhere on the board
/ALU/BUS0: R8.1; also elsewhere on the board
/ALU/BUS1: R7.1; also elsewhere on the board
/ALU/BUS2: R6.1; also elsewhere on the board
/ALU/BUS3: R5.1; also elsewhere on the board
/ALU/BUS4: R4.1; also elsewhere on the board
/ALU/BUS5: R3.1; also elsewhere on the board
/ALU/BUS6: R2.1; also elsewhere on the board
/ALU/BUS7: R1.2; also elsewhere on the board
/Control Logic/~HI: R1.1; also elsewhere on the board
/UART Receiver/RX: J1.4; also elsewhere on the board
/UART Transmitter/TX: J1.5; also elsewhere on the board
CLOCK: U1.13, X1.8 (OUT); also elsewhere on the board
GND: C1.2, C52.2, J1.1, SW1.1, X1.7 (GND); also elsewhere on the board
~CLOCK: U1.12; also elsewhere on the board
~Reset: R9.1, SW1.2; also elsewhere on the board

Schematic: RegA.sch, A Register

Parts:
C2, C3, C4: 100nF; C_Disc_D5.0mm_W2.5mm_P2.50mm
U2, U3: 74HC173; DIP-16_W7.62mm
U4: 74HC245; DIP-20_W7.62mm

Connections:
+5V: C2.1, C3.1, C4.1, U2.16, U3.16, U4.1 (A->B), U4.20 (VCC); also elsewhere on the board
/ALU/A0: U3.3, U4.2 (A0); also elsewhere on the board
/ALU/A1: U3.4, U4.3 (A1); also elsewhere on the board
/ALU/A2: U3.5, U4.4 (A2); also elsewhere on the board
/ALU/A3: U3.6, U4.5 (A3); also elsewhere on the board
/ALU/A4: U2.3, U4.6 (A4); also elsewhere on the board
/ALU/A5: U2.4, U4.7 (A5); also elsewhere on the board
/ALU/A6: U2.5, U4.8 (A6); also elsewhere on the board
/ALU/A7: U2.6, U4.9 (A7); also elsewhere on the board
/ALU/BUS0: U3.14, U4.18 (B0); also elsewhere on the board
/ALU/BUS1: U3.13, U4.17 (B1); also elsewhere on the board
/ALU/BUS2: U3.12, U4.16 (B2); also elsewhere on the board
/ALU/BUS3: U3.11, U4.15 (B3); also elsewhere on the board
/ALU/BUS4: U2.14, U4.14 (B4); also elsewhere on the board
/ALU/BUS5: U2.13, U4.13 (B5); also elsewhere on the board
/ALU/BUS6: U2.12, U4.12 (B6); also elsewhere on the board
/ALU/BUS7: U2.11, U4.11 (B7); also elsewhere on the board
/Control Logic/~AI: U2.9, U2.10, U3.9, U3.10; also elsewhere on the board
/Control Logic/~AO: U4.19 (CE); also elsewhere on the board
CLOCK: U2.7, U3.7; also elsewhere on the board
GND: C2.2, C3.2, C4.2, U2.1, U2.2, U2.8, U2.15, U3.1, U3.2, U3.8, U3.15, U4.10 (GND); also elsewhere on the board

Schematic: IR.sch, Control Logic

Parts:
C5, C6, C7, C8, C9, C11: 100nF; C_Disc_D5.0mm_W2.5mm_P2.50mm
C10: 100pF; C_Disc_D5.0mm_W2.5mm_P2.50mm
R10: wire; R_Axial_DIN0207_L6.3mm_D2.5mm_P7.62mm_Horizontal
U1: 74HC04; DIP-14_W7.62mm
U5, U6, U8: 74HC173; DIP-16_W7.62mm
U7: AT28C64B CTRL MSB; DIP-28_W15.24mm_Socket
U9: AT28C64B CTRL LSB; DIP-28_W15.24mm_Socket
U11: 74HC161; DIP-16_W7.62mm
U19: 74HC08; DIP-14_W7.62mm

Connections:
+5V: C5.1, C6.1, C7.1, C8.1, C9.1, C11.1, U5.16, U6.16, U7.27, U7.28, U8.16, U9.27, U9.28, U11.7, U11.9, U11.10, U11.16; also elsewhere on the board
/ALU/BUS0: U8.14; also elsewhere on the board
/ALU/BUS1: U8.13; also elsewhere on the board
/ALU/BUS2: U8.12; also elsewhere on the board
/ALU/BUS3: U8.11; also elsewhere on the board
/ALU/BUS4: U6.14; also elsewhere on the board
/ALU/BUS5: U6.13; also elsewhere on the board
/ALU/EC: U7.13; also elsewhere on the board
/ALU/ES: U7.12; also elsewhere on the board
/ALU/FLAG_C: U5.13; also elsewhere on the board
/ALU/FLAG_N: U5.12; also elsewhere on the board
/ALU/FLAG_Z: U5.14, U19.6
/ALU/~EO: U5.9, U5.10, U7.11; also elsewhere on the board
/Control Logic/CE: U7.17; also elsewhere on the board
/Control Logic/HI: U1.1, U9.19; also elsewhere on the board
/Control Logic/~AI: U9.15; also elsewhere on the board
/Control Logic/~AO: U9.13; also elsewhere on the board
/Control Logic/~BI: U9.12; also elsewhere on the board
/Control Logic/~BO: U9.11; also elsewhere on the board
/Control Logic/~CI: U7.19; also elsewhere on the board
/Control Logic/~CO: U7.18; also elsewhere on the board
/Control Logic/~HI: U1.2; also elsewhere on the board
/Control Logic/~MI: U9.18; also elsewhere on the board
/Control Logic/~RI: U9.17; also elsewhere on the board
/Control Logic/~RO: U9.16; also elsewhere on the board
CLOCK: U5.7, U6.7, U8.7; also elsewhere on the board
GND: C5.2, C6.2, C7.2, C8.2, C9.2, C10.2, C11.2, U5.1, U5.2, U5.8, U5.11, U5.15, U6.1, U6.2, U6.8, U6.11, U6.12, U6.15, U7.14, U7.20, U7.22, U8.1, U8.2, U8.8, U8.15, U9.14, U9.20, U9.22, U11.8; also elsewhere on the board
unnamed: C10.1, R10.2, U19.10
unnamed: R10.1, U7.15
unnamed: U5.3, U7.21, U9.21
unnamed: U5.4, U7.23, U9.23
unnamed: U5.5, U7.2, U9.2
unnamed: U6.3, U7.25, U9.25
unnamed: U6.4, U7.24, U9.24
unnamed: U6.9, U6.10, U7.16, U8.9, U8.10
unnamed: U7.3, U8.6, U9.3
unnamed: U7.4, U8.5, U9.4
unnamed: U7.5, U8.4, U9.5
unnamed: U7.6, U8.3, U9.6
unnamed: U11.1, U19.8
unnamed: U7.7, U9.7, U11.11
unnamed: U7.8, U9.8, U11.12
unnamed: U7.9, U9.9, U11.13
unnamed: U7.10, U9.10, U11.14
unnamed 105: U19.1; also elsewhere on the board
unnamed 106: U19.2; also elsewhere on the board
unnamed 107: U19.12; also elsewhere on the board
unnamed 108: U19.13; also elsewhere on the board
unnamed: U19.3, U19.4
unnamed: U19.5, U19.11
~CLOCK: U11.2; also elsewhere on the board
~Reset: U19.9; also elsewhere on the board

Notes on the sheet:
~IC
~II
~FI

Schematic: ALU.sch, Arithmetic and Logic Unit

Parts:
C12, C13, C14, C16, C17, C18: 100nF; C_Disc_D5.0mm_W2.5mm_P2.50mm
U12, U16: 74HC86; DIP-14_W7.62mm
U13, U14: 74HC283; DIP-16_W7.62mm
U15: 74HC245; DIP-20_W7.62mm
U18: 74HC02; DIP-14_W7.62mm
U19: 74HC08; DIP-14_W7.62mm

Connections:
+5V: C12.1, C13.1, C14.1, C16.1, C17.1, C18.1, U12.14 (VCC), U13.16, U14.16, U15.20 (VCC), U16.14 (VCC), U18.14 (VCC), U19.14 (VCC); also elsewhere on the board
/ALU/A0: U14.5; also elsewhere on the board
/ALU/A1: U14.3; also elsewhere on the board
/ALU/A2: U14.14; also elsewhere on the board
/ALU/A3: U14.12; also elsewhere on the board
/ALU/A4: U13.5; also elsewhere on the board
/ALU/A5: U13.3; also elsewhere on the board
/ALU/A6: U13.14; also elsewhere on the board
/ALU/A7: U13.12; also elsewhere on the board
/ALU/B0: U16.13; also elsewhere on the board
/ALU/B1: U16.10; also elsewhere on the board
/ALU/B2: U16.5; also elsewhere on the board
/ALU/B3: U16.2; also elsewhere on the board
/ALU/B4: U12.13; also elsewhere on the board
/ALU/B5: U12.10; also elsewhere on the board
/ALU/B6: U12.5; also elsewhere on the board
/ALU/B7: U12.2; also elsewhere on the board
/ALU/BUS0: U15.2 (A0); also elsewhere on the board
/ALU/BUS1: U15.3 (A1); also elsewhere on the board
/ALU/BUS2: U15.4 (A2); also elsewhere on the board
/ALU/BUS3: U15.5 (A3); also elsewhere on the board
/ALU/BUS4: U15.6 (A4); also elsewhere on the board
/ALU/BUS5: U15.7 (A5); also elsewhere on the board
/ALU/BUS6: U15.8 (A6); also elsewhere on the board
/ALU/BUS7: U15.9 (A7); also elsewhere on the board
/ALU/EC: U14.7; also elsewhere on the board
/ALU/ES: U12.1, U12.4, U12.9, U12.12, U16.1, U16.4, U16.9, U16.12; also elsewhere on the board
/ALU/FLAG_C: U13.9; also elsewhere on the board
/ALU/FLAG_N: U13.10, U15.11 (B7), U18.12; also elsewhere on the board
/ALU/FLAG_Z: U19.6; also elsewhere on the board
/ALU/~EO: U15.19 (CE); also elsewhere on the board
GND: C12.2, C13.2, C14.2, C16.2, C17.2, C18.2, U12.7 (GND), U13.8, U14.8, U15.1 (A->B), U15.10 (GND), U16.7 (GND), U18.7 (GND), U19.7 (GND); also elsewhere on the board
unnamed: U12.3, U13.11
unnamed: U12.6, U13.15
unnamed: U12.8, U13.2
unnamed: U12.11, U13.6
unnamed: U13.1, U15.13 (B5), U18.9
unnamed: U13.4, U15.14 (B4), U18.8
unnamed: U13.7, U14.9
unnamed: U13.13, U15.12 (B6), U18.11
unnamed: U14.1, U15.17 (B1), U18.3
unnamed: U14.2, U16.8
unnamed: U14.4, U15.18 (B0), U18.2
unnamed: U14.6, U16.11
unnamed: U14.10, U15.15 (B3), U18.6
unnamed: U14.11, U16.3
unnamed: U14.13, U15.16 (B2), U18.5
unnamed: U14.15, U16.6
unnamed: U18.1, U19.1
unnamed: U18.4, U19.2
unnamed: U18.10, U19.12
unnamed: U18.13, U19.13
unnamed: U19.3, U19.4
unnamed: U19.5, U19.11

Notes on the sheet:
C=100nF intentionally left out due to layout.

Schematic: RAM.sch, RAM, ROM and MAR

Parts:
C22, C23, C24, C25, C26, C27, C28, C29, C31: 100nF; C_Disc_D5.0mm_W2.5mm_P2.50mm
U1: 74HC04; DIP-14_W7.62mm
U24, U29: 74HC32; DIP-14_W7.62mm
U26, U28, U30, U33: 74HC161; DIP-16_W7.62mm
U31: AT28C64B 8k ROM; DIP-28_W15.24mm_Socket
U32: CY62256 32k RAM; DIP-28_W15.24mm
U44: 74HC00; DIP-14_W7.62mm

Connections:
+5V: C22.1, C23.1, C24.1, C25.1, C26.1, C27.1, C28.1, C29.1, C31.1, U1.14 (VCC), U24.14, U26.1, U26.16, U28.1, U28.16, U29.14, U30.16, U31.27, U31.28, U32.28, U33.16; also elsewhere on the board
/ALU/BUS0: U28.3, U31.11, U32.11, U33.3; also elsewhere on the board
/ALU/BUS1: U28.4, U31.12, U32.12, U33.4; also elsewhere on the board
/ALU/BUS2: U28.5, U31.13, U32.13, U33.5; also elsewhere on the board
/ALU/BUS3: U28.6, U31.15, U32.15, U33.6; also elsewhere on the board
/ALU/BUS4: U26.3, U30.3, U31.16, U32.16; also elsewhere on the board
/ALU/BUS5: U26.4, U30.4, U31.17, U32.17; also elsewhere on the board
/ALU/BUS6: U26.5, U30.5, U31.18, U32.18; also elsewhere on the board
/ALU/BUS7: U26.6, U30.6, U31.19, U32.19; also elsewhere on the board
/Control Logic/CE: U26.7, U28.7, U30.7, U33.7, U33.10; also elsewhere on the board
/Control Logic/HI: U24.1; also elsewhere on the board
/Control Logic/~AI: U29.13; also elsewhere on the board
/Control Logic/~HI: U24.5; also elsewhere on the board
/Control Logic/~MI: U24.2, U24.4; also elsewhere on the board
/Control Logic/~RI: U1.11, U29.9; also elsewhere on the board
/Control Logic/~RO: U24.13, U31.22, U32.22; also elsewhere on the board
/Memory/M0: U31.10, U32.21, U33.14
/Memory/M1: U31.9, U32.23, U33.13
/Memory/M2: U31.8, U32.24, U33.12
/Memory/M3: U31.7, U32.25, U33.11
/Memory/M4: U30.14, U31.6, U32.26
/Memory/M5: U30.13, U31.5, U32.1
/Memory/M6: U30.12, U31.4, U32.2
/Memory/M7: U30.11, U31.3, U32.3
/Memory/M8: U28.14, U31.25, U32.4
/Memory/M9: U28.13, U31.24, U32.5
/Memory/M10: U28.12, U31.21, U32.6
/Memory/M11: U28.11, U31.23, U32.7
/Memory/M12: U26.14, U31.2, U32.8
/Memory/M13: U26.13, U29.1, U32.9
/Memory/M14: U26.12, U29.2, U32.10
/Memory/M15: U1.9, U24.9, U26.11, U29.5
/Memory/~TI: U29.8; also elsewhere on the board
/Memory/~TO: U29.11; also elsewhere on the board
CLOCK: U26.2, U28.2, U30.2, U33.2, U44.9; also elsewhere on the board
GND: C22.2, C23.2, C24.2, C25.2, C26.2, C27.2, C28.2, C29.2, C31.2, U1.7 (GND), U24.7, U26.8, U28.8, U29.7, U30.8, U31.14, U32.14, U33.8; also elsewhere on the board
unnamed: U1.5, U29.6, U31.20
unnamed: U1.6, U24.10
unnamed: U1.8, U24.12, U29.10
unnamed: U1.10, U44.10
unnamed: U24.3, U30.9, U33.9
unnamed: U24.6, U26.9, U28.9
unnamed: U24.8, U32.20
unnamed: U24.11, U29.12
unnamed: U26.10, U28.15
unnamed: U28.10, U30.15
unnamed: U29.3, U29.4
unnamed: U30.10, U33.15
unnamed: U32.27, U44.8
~Reset: U30.1, U33.1; also elsewhere on the board

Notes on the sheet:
~MIL
~MIH
~ROM_ENABLE
~RAM_ENABLE

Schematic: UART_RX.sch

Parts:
C32, C33, C34, C35, C36, C37, C39, C51: 100nF; C_Disc_D5.0mm_W2.5mm_P2.50mm
U1: 74HC04; DIP-14_W7.62mm
U34: 74HC161; DIP-16_W7.62mm
U35: 74HC00; DIP-14_W7.62mm
U36, U38, U41: 74HC173; DIP-16_W7.62mm
U37: 74HC193; DIP-16_W7.62mm
U39: 74HC164; DIP-14_W7.62mm
U40: 74HC02; DIP-14_W7.62mm

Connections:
+5V: C32.1, C33.1, C34.1, C35.1, C36.1, C37.1, C39.1, C51.1, U34.7, U34.9, U34.10, U34.16, U35.14 (VCC), U36.16, U37.5, U37.9, U37.15, U37.16, U38.16, U39.2 (DSB), U39.9 (~MR), U39.14 (VCC), U40.14 (VCC), U41.16; also elsewhere on the board
/ALU/BUS0: U36.6; also elsewhere on the board
/ALU/BUS1: U36.5; also elsewhere on the board
/ALU/BUS2: U36.4; also elsewhere on the board
/ALU/BUS3: U36.3; also elsewhere on the board
/ALU/BUS4: U38.6; also elsewhere on the board
/ALU/BUS5: U38.5; also elsewhere on the board
/ALU/BUS6: U38.4; also elsewhere on the board
/ALU/BUS7: U38.3; also elsewhere on the board
/Memory/~TO: U36.1, U36.2, U38.1, U38.2, U40.8; also elsewhere on the board
/UART Receiver/RX: U35.1, U39.1 (DSA); also elsewhere on the board
/UART Receiver/~RESET: U35.5, U35.9, U37.13
CLOCK: U34.2, U41.7; also elsewhere on the board
GND: C32.2, C33.2, C34.2, C35.2, C36.2, C37.2, C39.2, C51.2, U34.8, U35.7 (GND), U36.8, U36.9, U36.10, U37.1, U37.8, U37.10, U37.14, U38.8, U38.9, U38.10, U39.7 (GND), U40.7 (GND), U41.1, U41.2, U41.8, U41.9, U41.10; also elsewhere on the board
unnamed: U1.3, U41.3
unnamed: U1.4, U40.3
unnamed: U34.1, U35.3, U35.4, U37.11
unnamed: U34.11, U37.4, U39.8 (CP)
unnamed: U35.2, U35.6, U36.7, U38.7
unnamed: U35.10, U35.11
unnamed: U35.8, U35.12, U41.14
unnamed: U35.13, U40.13
unnamed: U36.11, U39.13 (Q7)
unnamed: U36.12, U39.12 (Q6)
unnamed: U36.13, U39.11 (Q5)
unnamed: U36.14, U39.10 (Q4)
unnamed: U36.15, U38.15, U40.10, U40.11, U40.12, U41.15
unnamed: U38.11, U39.6 (Q3)
unnamed: U38.12, U39.5 (Q2)
unnamed: U38.13, U39.4 (Q1)
unnamed: U38.14, U39.3 (Q0)
unnamed: U40.1, U40.5, U40.6
unnamed: U40.4, U40.9
~CLOCK: U40.2; also elsewhere on the board

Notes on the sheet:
DATA_READY

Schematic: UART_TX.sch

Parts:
C40, C41, C42, C43: 100nF; C_Disc_D5.0mm_W2.5mm_P2.50mm
U42: 74HC161; DIP-16_W7.62mm
U43, U45: 74HC165; DIP-16_W7.62mm
U44: 74HC00; DIP-14_W7.62mm

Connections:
+5V: C40.1, C41.1, C42.1, C43.1, U42.7, U42.9, U42.10, U42.16, U43.6, U43.16, U44.14 (VCC), U45.3, U45.4, U45.10, U45.11, U45.12, U45.13, U45.14, U45.16; also elsewhere on the board
/ALU/BUS0: U43.4; also elsewhere on the board
/ALU/BUS1: U43.3; also elsewhere on the board
/ALU/BUS2: U43.14; also elsewhere on the board
/ALU/BUS3: U43.13; also elsewhere on the board
/ALU/BUS4: U43.12; also elsewhere on the board
/ALU/BUS5: U43.11; also elsewhere on the board
/ALU/BUS6: U45.6; also elsewhere on the board
/ALU/BUS7: U45.5; also elsewhere on the board
/Memory/~TI: U44.4, U44.5; also elsewhere on the board
/UART Transmitter/TX: U43.9; also elsewhere on the board
CLOCK: U42.2, U44.2; also elsewhere on the board
GND: C40.2, C41.2, C42.2, C43.2, U42.8, U43.5, U43.8, U44.7 (GND), U44.12, U44.13, U45.8; also elsewhere on the board
unnamed: U42.1, U43.1, U44.3, U45.1
unnamed: U42.11, U43.2, U45.2
unnamed: U43.10, U45.9
unnamed: U43.15, U44.1, U44.6, U45.15

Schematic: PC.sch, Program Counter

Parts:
C44, C45, C46, C47, C48, C49, C50: 100nF; C_Disc_D5.0mm_W2.5mm_P2.50mm
U46, U49, U51, U52: 74HC161; DIP-16_W7.62mm
U48: 74HC32; DIP-14_W7.62mm
U50, U53: 74HC245; DIP-20_W7.62mm

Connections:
+5V: C44.1, C45.1, C46.1, C47.1, C48.1, C49.1, C50.1, U46.16, U48.14, U49.16, U50.20 (VCC), U51.16, U52.16, U53.20 (VCC); also elsewhere on the board
/ALU/BUS0: U49.3, U50.2 (A0), U52.3, U53.2 (A0); also elsewhere on the board
/ALU/BUS1: U49.4, U50.3 (A1), U52.4, U53.3 (A1); also elsewhere on the board
/ALU/BUS2: U49.5, U50.4 (A2), U52.5, U53.4 (A2); also elsewhere on the board
/ALU/BUS3: U49.6, U50.5 (A3), U52.6, U53.5 (A3); also elsewhere on the board
/ALU/BUS4: U46.3, U50.6 (A4), U51.3, U53.6 (A4); also elsewhere on the board
/ALU/BUS5: U46.4, U50.7 (A5), U51.4, U53.7 (A5); also elsewhere on the board
/ALU/BUS6: U46.5, U50.8 (A6), U51.5, U53.8 (A6); also elsewhere on the board
/ALU/BUS7: U46.6, U50.9 (A7), U51.6, U53.9 (A7); also elsewhere on the board
/Control Logic/CE: U46.7, U49.7, U51.7, U52.7, U52.10; also elsewhere on the board
/Control Logic/HI: U48.5, U48.9; also elsewhere on the board
/Control Logic/~CI: U48.10, U48.12; also elsewhere on the board
/Control Logic/~CO: U48.2, U48.4; also elsewhere on the board
/Control Logic/~HI: U48.1, U48.13; also elsewhere on the board
CLOCK: U46.2, U49.2, U51.2, U52.2; also elsewhere on the board
GND: C44.2, C45.2, C46.2, C47.2, C48.2, C49.2, C50.2, U46.8, U48.7, U49.8, U50.1 (A->B), U50.10 (GND), U51.8, U52.8, U53.1 (A->B), U53.10 (GND); also elsewhere on the board
unnamed: U46.9, U48.11, U49.9
unnamed: U46.10, U49.15
unnamed: U46.11, U50.11 (B7)
unnamed: U46.12, U50.12 (B6)
unnamed: U46.13, U50.13 (B5)
unnamed: U46.14, U50.14 (B4)
unnamed: U48.3, U50.19 (CE)
unnamed: U48.6, U53.19 (CE)
unnamed: U48.8, U51.9, U52.9
unnamed: U49.10, U51.15
unnamed: U49.11, U50.15 (B3)
unnamed: U49.12, U50.16 (B2)
unnamed: U49.13, U50.17 (B1)
unnamed: U49.14, U50.18 (B0)
unnamed: U51.10, U52.15
unnamed: U51.11, U53.11 (B7)
unnamed: U51.12, U53.12 (B6)
unnamed: U51.13, U53.13 (B5)
unnamed: U51.14, U53.14 (B4)
unnamed: U52.11, U53.15 (B3)
unnamed: U52.12, U53.16 (B2)
unnamed: U52.13, U53.17 (B1)
unnamed: U52.14, U53.18 (B0)
~Reset: U46.1, U49.1, U51.1, U52.1; also elsewhere on the board

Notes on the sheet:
~COH
~COL
~CIL
~CIH

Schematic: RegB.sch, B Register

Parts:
C19, C20, C21: 100nF; C_Disc_D5.0mm_W2.5mm_P2.50mm
U10, U17: 74HC173; DIP-16_W7.62mm
U23: 74HC245; DIP-20_W7.62mm

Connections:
+5V: C19.1, C20.1, C21.1, U10.16, U17.16, U23.1 (A->B), U23.20 (VCC); also elsewhere on the board
/ALU/B0: U17.3, U23.2 (A0); also elsewhere on the board
/ALU/B1: U17.4, U23.3 (A1); also elsewhere on the board
/ALU/B2: U17.5, U23.4 (A2); also elsewhere on the board
/ALU/B3: U17.6, U23.5 (A3); also elsewhere on the board
/ALU/B4: U10.3, U23.6 (A4); also elsewhere on the board
/ALU/B5: U10.4, U23.7 (A5); also elsewhere on the board
/ALU/B6: U10.5, U23.8 (A6); also elsewhere on the board
/ALU/B7: U10.6, U23.9 (A7); also elsewhere on the board
/ALU/BUS0: U17.14, U23.18 (B0); also elsewhere on the board
/ALU/BUS1: U17.13, U23.17 (B1); also elsewhere on the board
/ALU/BUS2: U17.12, U23.16 (B2); also elsewhere on the board
/ALU/BUS3: U17.11, U23.15 (B3); also elsewhere on the board
/ALU/BUS4: U10.14, U23.14 (B4); also elsewhere on the board
/ALU/BUS5: U10.13, U23.13 (B5); also elsewhere on the board
/ALU/BUS6: U10.12, U23.12 (B6); also elsewhere on the board
/ALU/BUS7: U10.11, U23.11 (B7); also elsewhere on the board
/Control Logic/~BI: U10.9, U10.10, U17.9, U17.10; also elsewhere on the board
/Control Logic/~BO: U23.19 (CE); also elsewhere on the board
CLOCK: U10.7, U17.7; also elsewhere on the board
GND: C19.2, C20.2, C21.2, U10.1, U10.2, U10.8, U10.15, U17.1, U17.2, U17.8, U17.15, U23.10 (GND); also elsewhere on the board

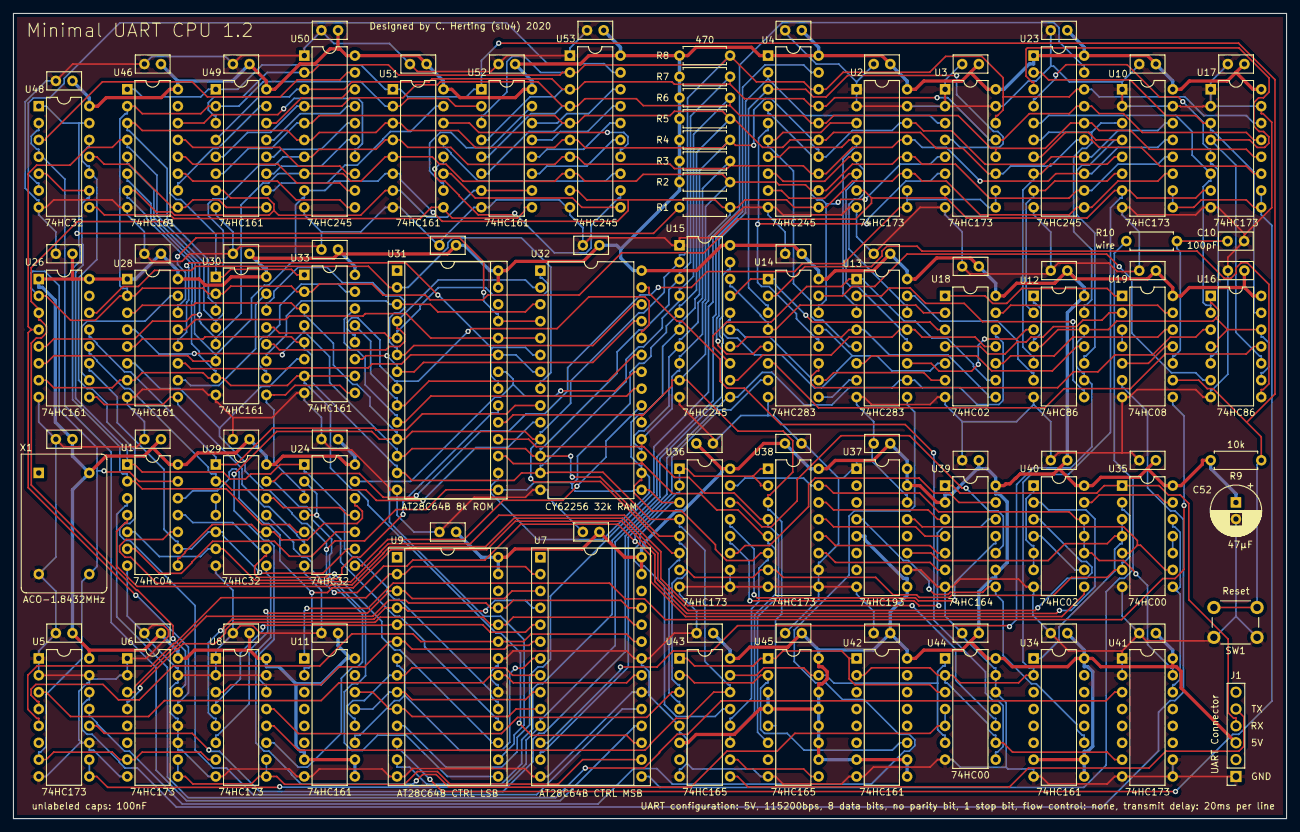
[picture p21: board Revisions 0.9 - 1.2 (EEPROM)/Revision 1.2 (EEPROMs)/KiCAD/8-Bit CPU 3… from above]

Board: 2 copper layers, 191.8 x 121.3 mm, 109 parts (0 on the bottom side), 166 nets.

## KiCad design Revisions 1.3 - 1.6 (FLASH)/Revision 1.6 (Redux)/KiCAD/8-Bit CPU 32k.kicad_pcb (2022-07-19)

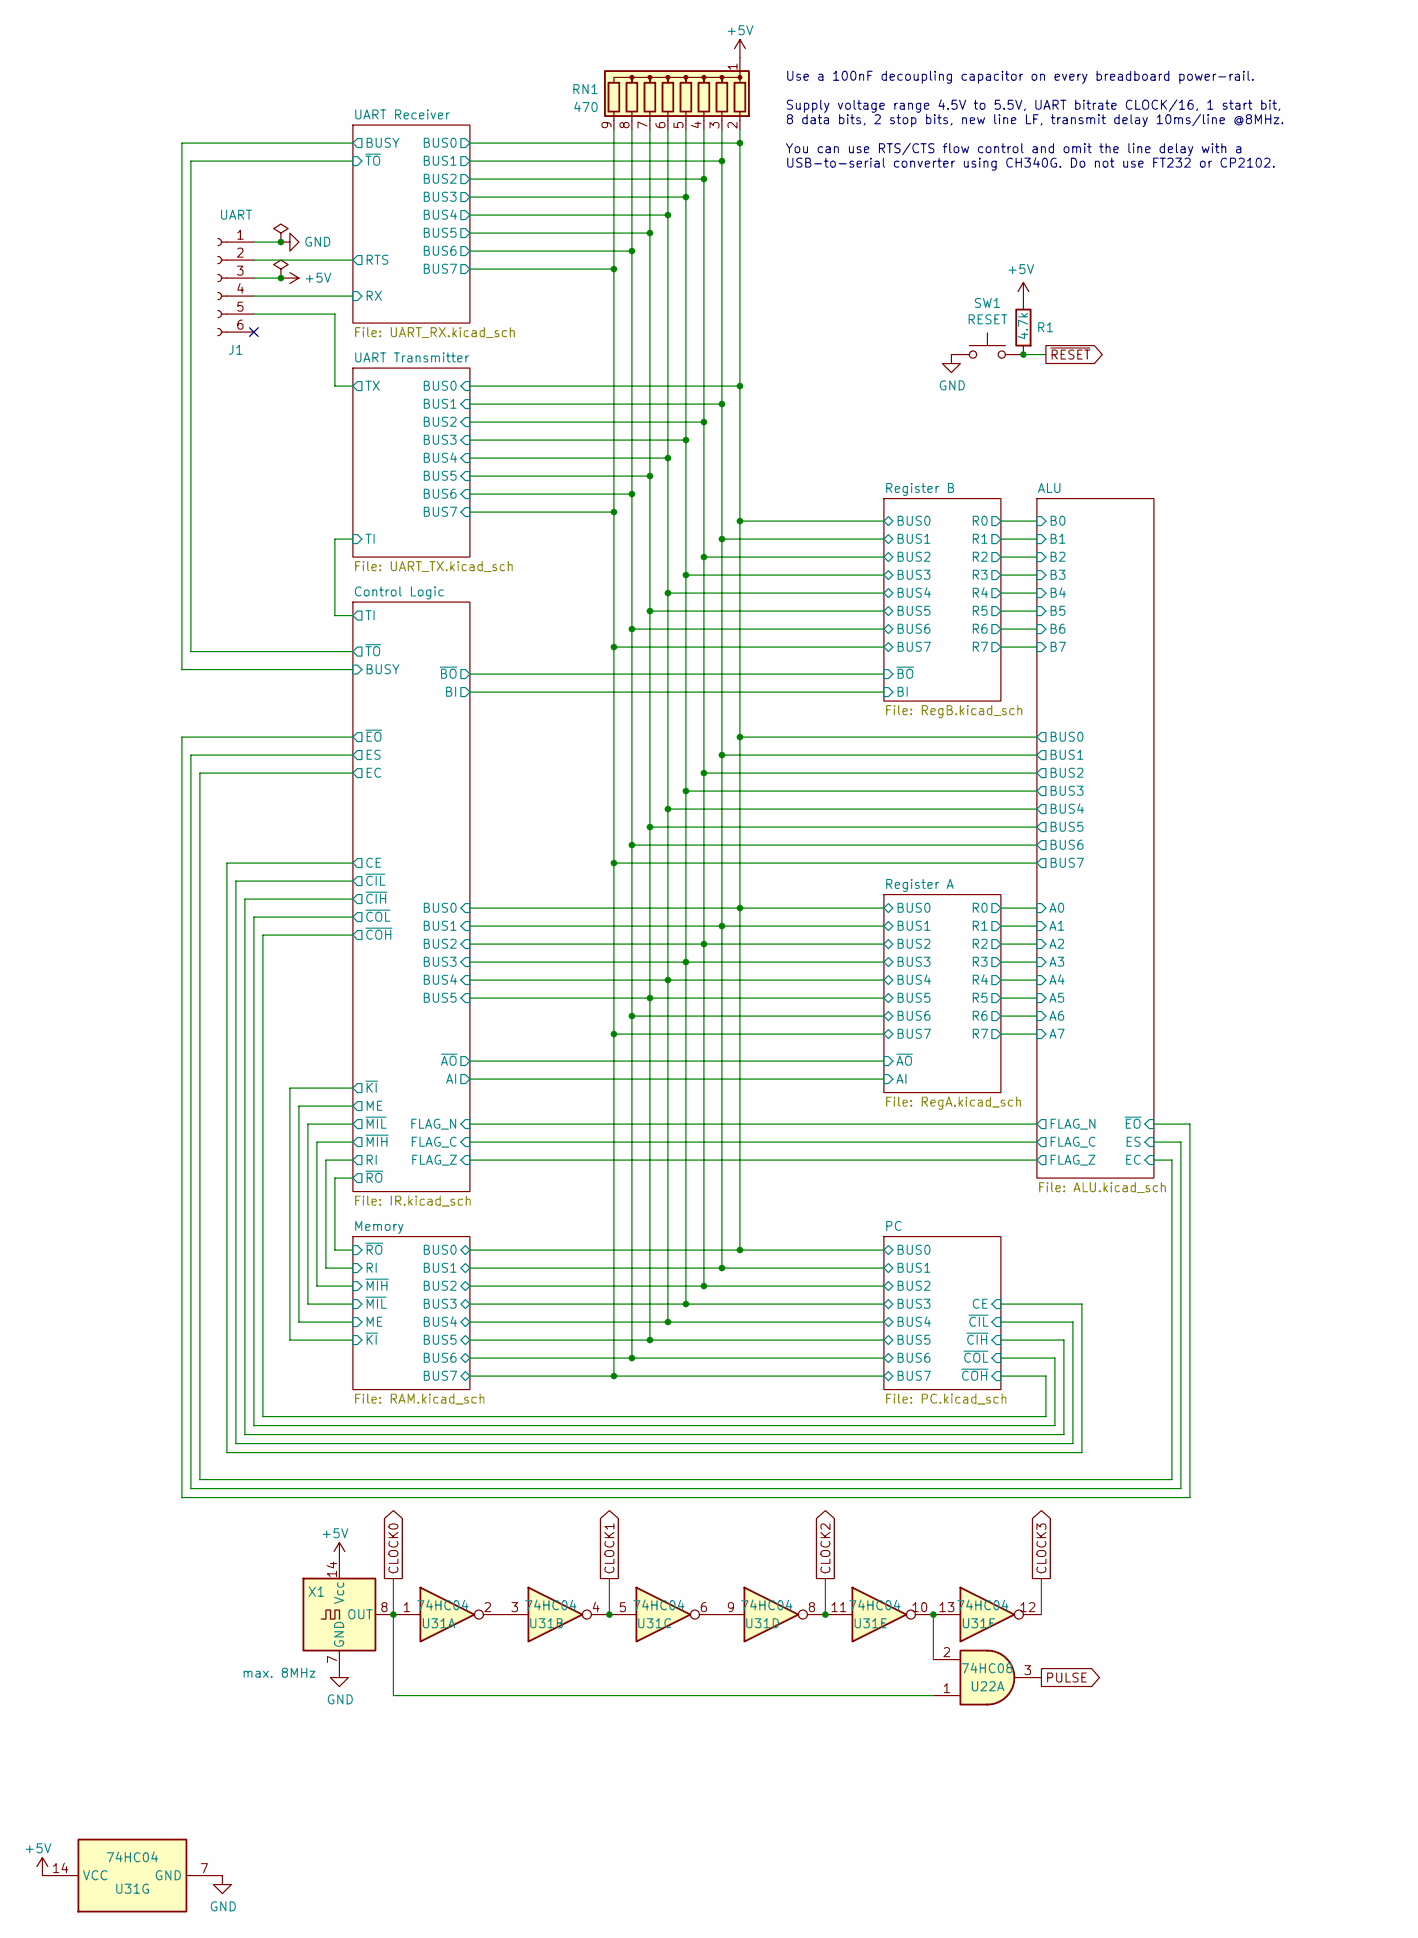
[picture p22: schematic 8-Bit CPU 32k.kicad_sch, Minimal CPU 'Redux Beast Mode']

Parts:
J1: UART; PinSocket_1x06_P2.54mm_Vertical
R1: 4.7k; R_Axial_DIN0207_L6.3mm_D2.5mm_P7.62mm_Horizontal
RN1: 470; R_Array_SIP9
SW1: RESET; SW_PUSH_6mm
U22: 74HC08; DIP-14_W7.62mm
U31: 74HC04; DIP-14_W7.62mm
X1: max. 8MHz; Oscillator_DIP-14

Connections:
+5V: J1.3, R1.1, RN1.1 (common), U31.14 (VCC), X1.14 (Vcc); also elsewhere on the board
/ALU/BUS0: RN1.2 (R1); also elsewhere on the board
/ALU/BUS1: RN1.3 (R2); also elsewhere on the board
/ALU/BUS2: RN1.4 (R3); also elsewhere on the board
/ALU/BUS3: RN1.5 (R4); also elsewhere on the board
/ALU/BUS4: RN1.6 (R5); also elsewhere on the board
/ALU/BUS5: RN1.7 (R6); also elsewhere on the board
/ALU/BUS6: RN1.8 (R7); also elsewhere on the board
/ALU/BUS7: RN1.9 (R8); also elsewhere on the board
/UART Receiver/RTS: J1.2; also elsewhere on the board
/UART Receiver/RX: J1.4; also elsewhere on the board
/UART Transmitter/TX: J1.5; also elsewhere on the board
CLOCK0: U22.1, U31.1, X1.8 (OUT); also elsewhere on the board
CLOCK1: U31.4, U31.5; also elsewhere on the board
CLOCK2: U31.8, U31.11; also elsewhere on the board
CLOCK3: U31.12; also elsewhere on the board
GND: J1.1, SW1.1, U31.7 (GND), X1.7 (GND); also elsewhere on the board
unnamed: U22.2, U31.10, U31.13
unnamed: U31.2, U31.3
unnamed: U31.6, U31.9
PULSE: U22.3; also elsewhere on the board
~RESET: R1.2, SW1.2; also elsewhere on the board

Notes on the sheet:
Use a 100nF decoupling capacitor on every breadboard power-rail. Supply voltage range 4.5V to 5.5V, UART bitrate CLOCK/16, 1 start bit, 8 data bits, 2 stop bits, new line LF, transmit delay 10ms/line @8MHz. You can use RTS/CTS flow control and omit the line delay with a USB-to-serial converter usin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

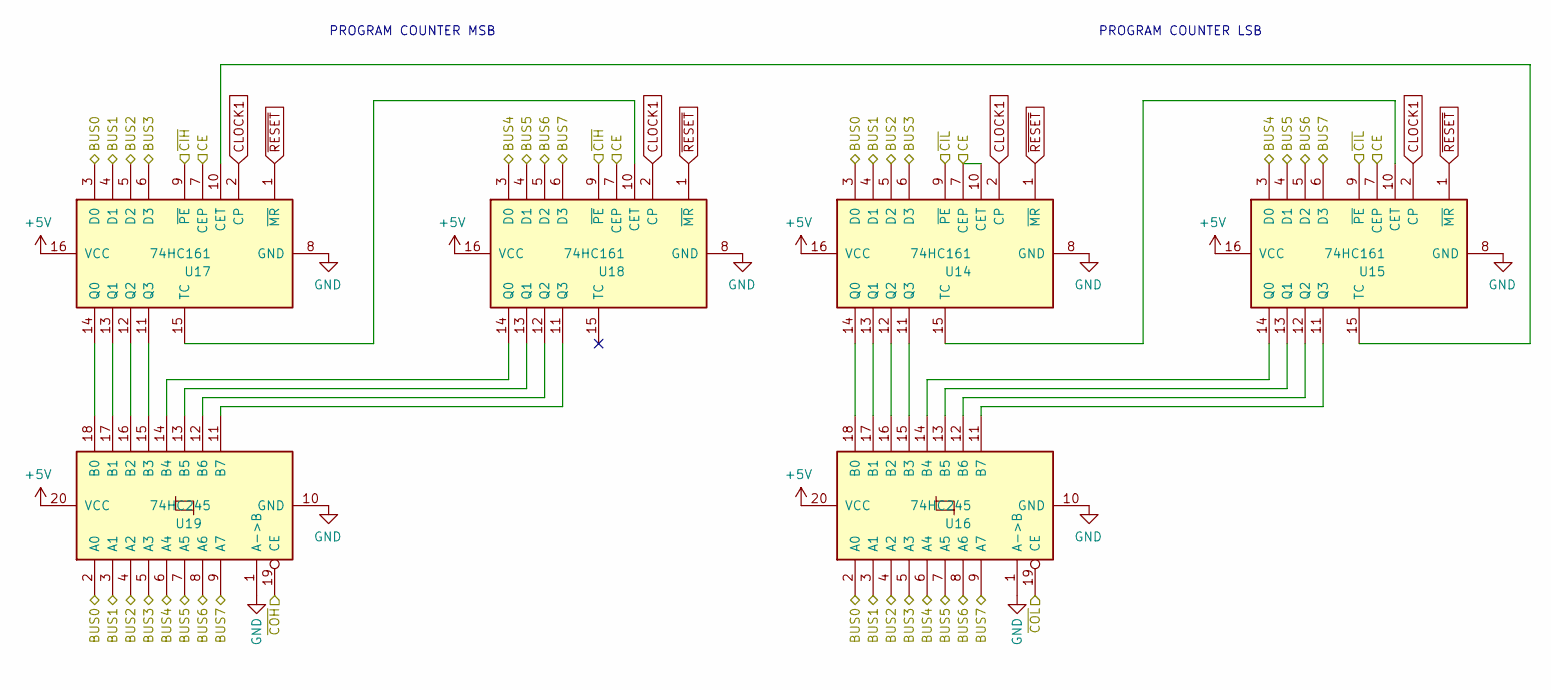
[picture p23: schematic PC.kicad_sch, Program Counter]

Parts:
U14, U15, U17, U18: 74HC161; DIP-16_W7.62mm
U16, U19: 74HC245; DIP-20_W7.62mm

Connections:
+5V: U14.16 (VCC), U15.16 (VCC), U16.20 (VCC), U17.16 (VCC), U18.16 (VCC), U19.20 (VCC); also elsewhere on the board
/ALU/BUS0: U14.3 (D0), U16.2 (A0), U17.3 (D0), U19.2 (A0); also elsewhere on the board
/ALU/BUS1: U14.4 (D1), U16.3 (A1), U17.4 (D1), U19.3 (A1); also elsewhere on the board
/ALU/BUS2: U14.5 (D2), U16.4 (A2), U17.5 (D2), U19.4 (A2); also elsewhere on the board
/ALU/BUS3: U14.6 (D3), U16.5 (A3), U17.6 (D3), U19.5 (A3); also elsewhere on the board
/ALU/BUS4: U15.3 (D0), U16.6 (A4), U18.3 (D0), U19.6 (A4); also elsewhere on the board
/ALU/BUS5: U15.4 (D1), U16.7 (A5), U18.4 (D1), U19.7 (A5); also elsewhere on the board
/ALU/BUS6: U15.5 (D2), U16.8 (A6), U18.5 (D2), U19.8 (A6); also elsewhere on the board
/ALU/BUS7: U15.6 (D3), U16.9 (A7), U18.6 (D3), U19.9 (A7); also elsewhere on the board
/Control Logic/CE: U14.7 (CEP), U14.10 (CET), U15.7 (CEP), U17.7 (CEP), U18.7 (CEP); also elsewhere on the board
/Control Logic/~CIH: U17.9 (~PE), U18.9 (~PE); also elsewhere on the board
/Control Logic/~CIL: U14.9 (~PE), U15.9 (~PE); also elsewhere on the board
/Control Logic/~COH: U19.19 (CE); also elsewhere on the board
/Control Logic/~COL: U16.19 (CE); also elsewhere on the board
CLOCK1: U14.2 (CP), U15.2 (CP), U17.2 (CP), U18.2 (CP); also elsewhere on the board
GND: U14.8 (GND), U15.8 (GND), U16.1 (A->B), U16.10 (GND), U17.8 (GND), U18.8 (GND), U19.1 (A->B), U19.10 (GND); also elsewhere on the board
unnamed: U14.11 (Q3), U16.15 (B3)
unnamed: U14.12 (Q2), U16.16 (B2)
unnamed: U14.13 (Q1), U16.17 (B1)
unnamed: U14.14 (Q0), U16.18 (B0)
unnamed: U14.15 (TC), U15.10 (CET)
unnamed: U15.11 (Q3), U16.11 (B7)
unnamed: U15.12 (Q2), U16.12 (B6)
unnamed: U15.13 (Q1), U16.13 (B5)
unnamed: U15.14 (Q0), U16.14 (B4)
unnamed: U15.15 (TC), U17.10 (CET)
unnamed: U17.11 (Q3), U19.15 (B3)
unnamed: U17.12 (Q2), U19.16 (B2)
unnamed: U17.13 (Q1), U19.17 (B1)
unnamed: U17.14 (Q0), U19.18 (B0)
unnamed: U17.15 (TC), U18.10 (CET)
unnamed: U18.11 (Q3), U19.11 (B7)
unnamed: U18.12 (Q2), U19.12 (B6)
unnamed: U18.13 (Q1), U19.13 (B5)
unnamed: U18.14 (Q0), U19.14 (B4)
~RESET: U14.1 (~MR), U15.1 (~MR), U17.1 (~MR), U18.1 (~MR); also elsewhere on the board

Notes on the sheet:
PROGRAM COUNTER MSB
PROGRAM COUNTER LSB

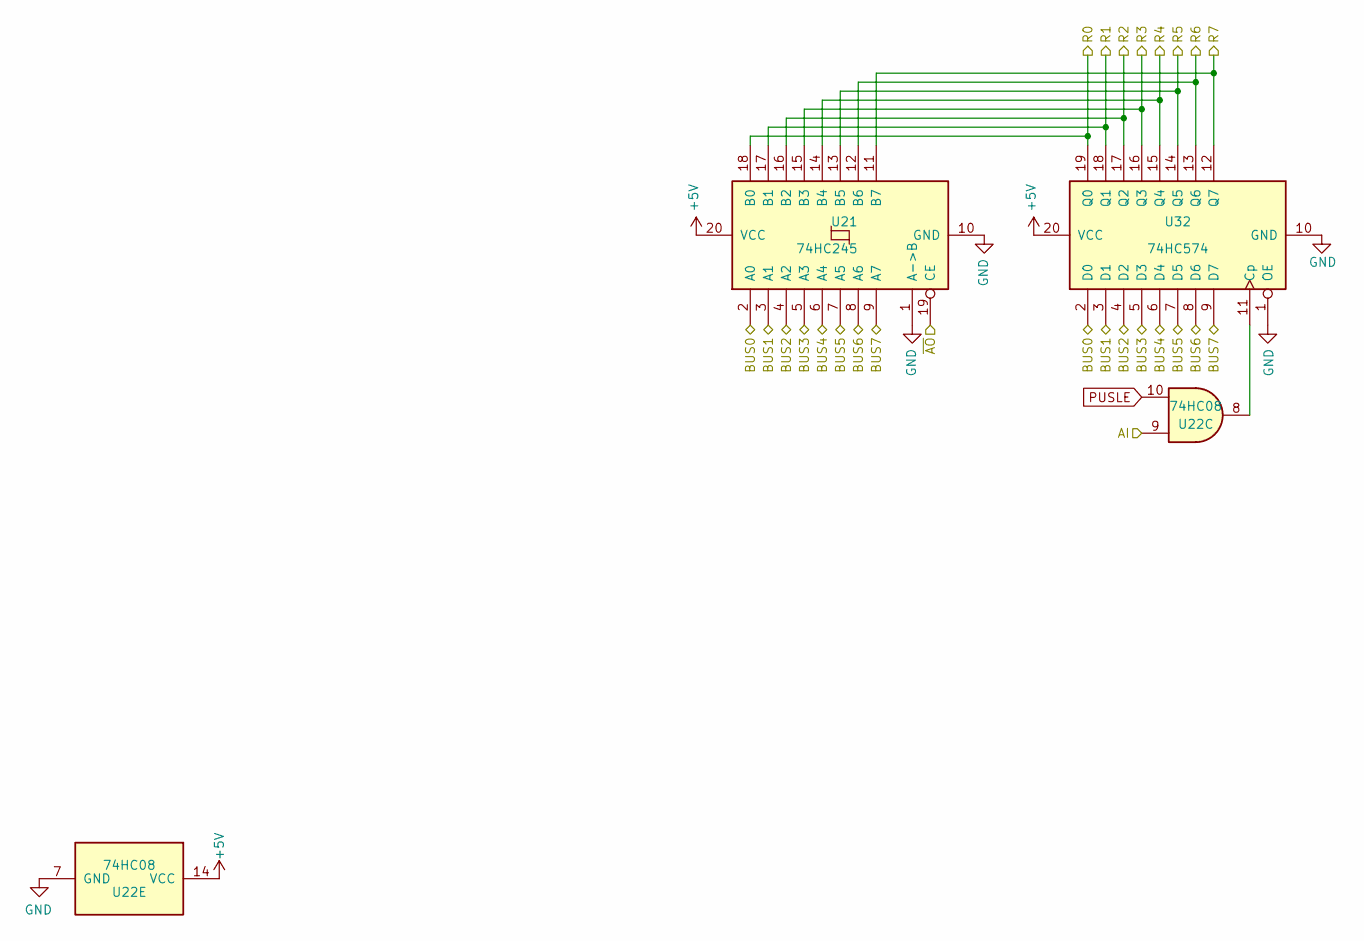
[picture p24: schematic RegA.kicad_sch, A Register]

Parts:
U21: 74HC245; DIP-20_W7.62mm
U22: 74HC08; DIP-14_W7.62mm
U32: 74HC574; DIP-20_W7.62mm

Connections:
+5V: U21.20 (VCC), U22.14 (VCC), U32.20 (VCC); also elsewhere on the board
/ALU/A0: U21.18 (B0), U32.19 (Q0); also elsewhere on the board
/ALU/A1: U21.17 (B1), U32.18 (Q1); also elsewhere on the board
/ALU/A2: U21.16 (B2), U32.17 (Q2); also elsewhere on the board
/ALU/A3: U21.15 (B3), U32.16 (Q3); also elsewhere on the board
/ALU/A4: U21.14 (B4), U32.15 (Q4); also elsewhere on the board
/ALU/A5: U21.13 (B5), U32.14 (Q5); also elsewhere on the board
/ALU/A6: U21.12 (B6), U32.13 (Q6); also elsewhere on the board
/ALU/A7: U21.11 (B7), U32.12 (Q7); also elsewhere on the board
/ALU/BUS0: U21.2 (A0), U32.2 (D0); also elsewhere on the board
/ALU/BUS1: U21.3 (A1), U32.3 (D1); also elsewhere on the board
/ALU/BUS2: U21.4 (A2), U32.4 (D2); also elsewhere on the board
/ALU/BUS3: U21.5 (A3), U32.5 (D3); also elsewhere on the board
/ALU/BUS4: U21.6 (A4), U32.6 (D4); also elsewhere on the board
/ALU/BUS5: U21.7 (A5), U32.7 (D5); also elsewhere on the board
/ALU/BUS6: U21.8 (A6), U32.8 (D6); also elsewhere on the board
/ALU/BUS7: U21.9 (A7), U32.9 (D7); also elsewhere on the board
/Control Logic/AI: U22.9; also elsewhere on the board
/Control Logic/~AO: U21.19 (CE); also elsewhere on the board
GND: U21.1 (A->B), U21.10 (GND), U22.7 (GND), U32.1 (OE), U32.10 (GND); also elsewhere on the board
unnamed: U22.8, U32.11 (Cp)
PUSLE: U22.10

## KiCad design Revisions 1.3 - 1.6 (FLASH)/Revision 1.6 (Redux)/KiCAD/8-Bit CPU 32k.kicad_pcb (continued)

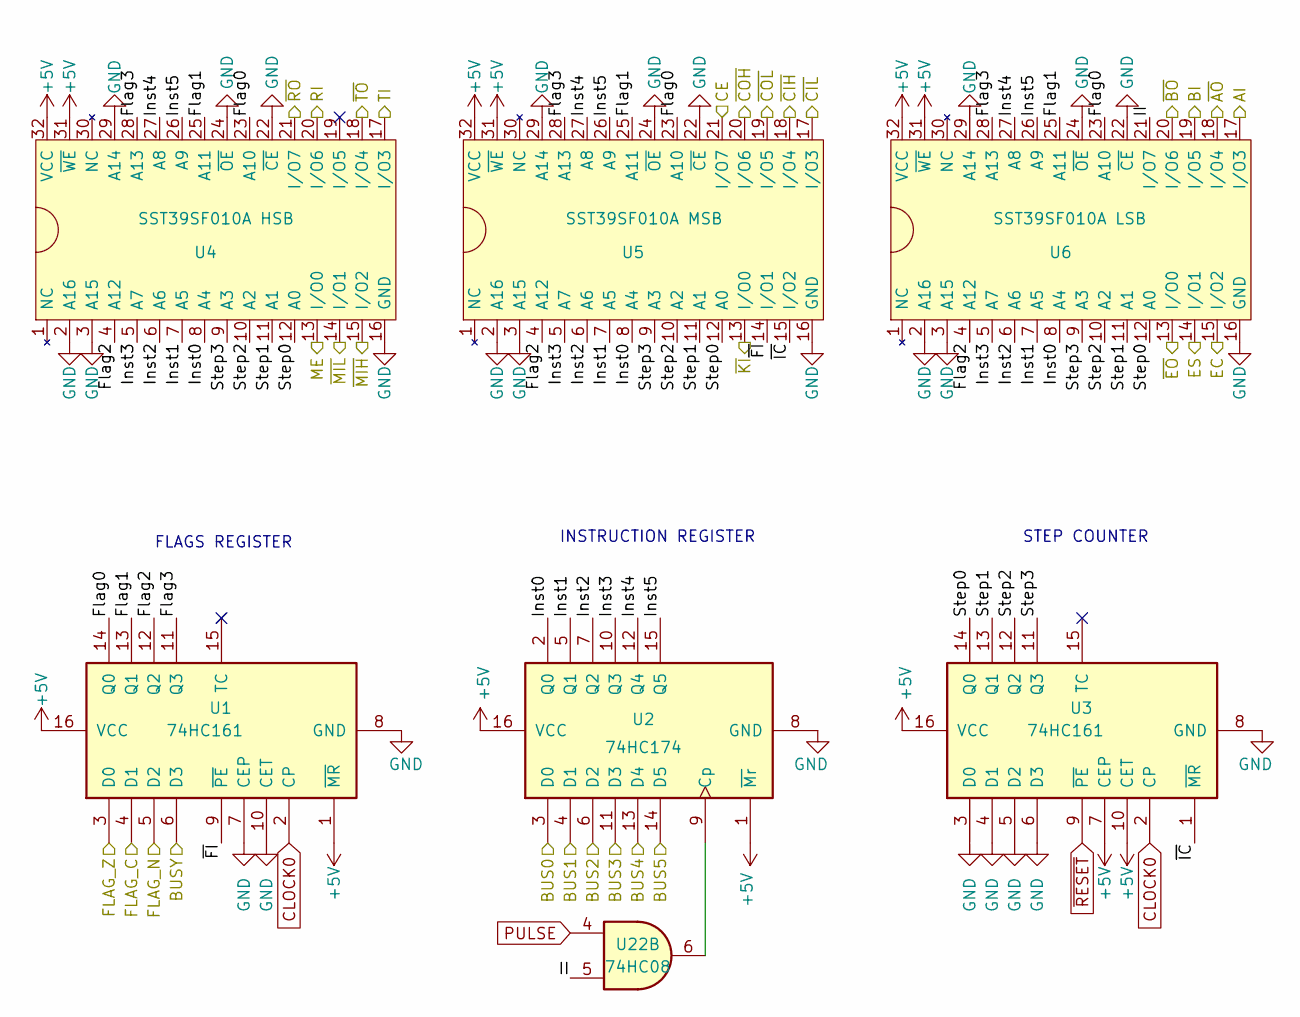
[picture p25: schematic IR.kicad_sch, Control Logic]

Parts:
U1, U3: 74HC161; DIP-16_W7.62mm
U2: 74HC174; DIP-16_W7.62mm
U4: SST39SF010A HSB; DIP-32_W15.24mm_Socket
U5: SST39SF010A MSB; DIP-32_W15.24mm_Socket
U6: SST39SF010A LSB; DIP-32_W15.24mm_Socket
U22: 74HC08; DIP-14_W7.62mm

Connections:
+5V: U1.1 (~MR), U1.16 (VCC), U2.1 (~Mr), U2.16 (VCC), U3.7 (CEP), U3.10 (CET), U3.16 (VCC), U4.31 (~WE), U4.32 (VCC), U5.31 (~WE), U5.32 (VCC), U6.31 (~WE), U6.32 (VCC); also elsewhere on the board
/ALU/BUS0: U2.3 (D0); also elsewhere on the board
/ALU/BUS1: U2.4 (D1); also elsewhere on the board
/ALU/BUS2: U2.6 (D2); also elsewhere on the board
/ALU/BUS3: U2.11 (D3); also elsewhere on the board
/ALU/BUS4: U2.13 (D4); also elsewhere on the board
/ALU/BUS5: U2.14 (D5); also elsewhere on the board
/ALU/EC: U6.15 (I/O2); also elsewhere on the board
/ALU/ES: U6.14 (I/O1); also elsewhere on the board
/ALU/FLAG_C: U1.4 (D1); also elsewhere on the board
/ALU/FLAG_N: U1.5 (D2); also elsewhere on the board
/ALU/FLAG_Z: U1.3 (D0); also elsewhere on the board
/ALU/~EO: U6.13 (I/O0); also elsewhere on the board
/Control Logic/AI: U6.17 (I/O3); also elsewhere on the board
/Control Logic/BI: U6.19 (I/O5); also elsewhere on the board
/Control Logic/BUSY: U1.6 (D3); also elsewhere on the board
/Control Logic/CE: U5.21 (I/O7); also elsewhere on the board
/Control Logic/Flag0: U1.14 (Q0), U4.23 (A10), U5.23 (A10), U6.23 (A10)
/Control Logic/Flag1: U1.13 (Q1), U4.25 (A11), U5.25 (A11), U6.25 (A11)
/Control Logic/Flag2: U1.12 (Q2), U4.4 (A12), U5.4 (A12), U6.4 (A12)
/Control Logic/Flag3: U1.11 (Q3), U4.28 (A13), U5.28 (A13), U6.28 (A13)
/Control Logic/II: U6.21 (I/O7), U22.5
/Control Logic/Inst0: U2.2 (Q0), U4.8 (A4), U5.8 (A4), U6.8 (A4)
/Control Logic/Inst1: U2.5 (Q1), U4.7 (A5), U5.7 (A5), U6.7 (A5)
/Control Logic/Inst2: U2.7 (Q2), U4.6 (A6), U5.6 (A6), U6.6 (A6)
/Control Logic/Inst3: U2.10 (Q3), U4.5 (A7), U5.5 (A7), U6.5 (A7)
/Control Logic/Inst4: U2.12 (Q4), U4.27 (A8), U5.27 (A8), U6.27 (A8)
/Control Logic/Inst5: U2.15 (Q5), U4.26 (A9), U5.26 (A9), U6.26 (A9)
/Control Logic/ME: U4.13 (I/O0); also elsewhere on the board
/Control Logic/RI: U4.20 (I/O6); also elsewhere on the board
/Control Logic/Step0: U3.14 (Q0), U4.12 (A0), U5.12 (A0), U6.12 (A0)
/Control Logic/Step1: U3.13 (Q1), U4.11 (A1), U5.11 (A1), U6.11 (A1)
/Control Logic/Step2: U3.12 (Q2), U4.10 (A2), U5.10 (A2), U6.10 (A2)
/Control Logic/Step3: U3.11 (Q3), U4.9 (A3), U5.9 (A3), U6.9 (A3)
/Control Logic/TI: U4.17 (I/O3); also elsewhere on the board
/Control Logic/~AO: U6.18 (I/O4); also elsewhere on the board
/Control Logic/~BO: U6.20 (I/O6); also elsewhere on the board
/Control Logic/~CIH: U5.18 (I/O4); also elsewhere on the board
/Control Logic/~CIL: U5.17 (I/O3); also elsewhere on the board
/Control Logic/~COH: U5.20 (I/O6); also elsewhere on the board
/Control Logic/~COL: U5.19 (I/O5); also elsewhere on the board
/Control Logic/~FI: U1.9 (~PE), U5.14 (I/O1)
/Control Logic/~IC: U3.1 (~MR), U5.15 (I/O2)
/Control Logic/~KI: U5.13 (I/O0); also elsewhere on the board
/Control Logic/~MIH: U4.15 (I/O2); also elsewhere on the board
/Control Logic/~MIL: U4.14 (I/O1); also elsewhere on the board
/Control Logic/~RO: U4.21 (I/O7); also elsewhere on the board
/Control Logic/~TO: U4.18 (I/O4); also elsewhere on the board
CLOCK0: U1.2 (CP), U3.2 (CP); also elsewhere on the board
GND: U1.7 (CEP), U1.8 (GND), U1.10 (CET), U2.8 (GND), U3.3 (D0), U3.4 (D1), U3.5 (D2), U3.6 (D3), U3.8 (GND), U4.2 (A16), U4.3 (A15), U4.16 (GND), U4.22 (~CE), U4.24 (~OE), U4.29 (A14), U5.2 (A16), U5.3 (A15), U5.16 (GND), U5.22 (~CE), U5.24 (~OE), U5.29 (A14), U6.2 (A16), U6.3 (A15), U6.16 (GND), U6.22 (~CE), U6.24 (~OE), U6.29 (A14); also elsewhere on the board
unnamed: U2.9 (Cp), U22.6
PULSE: U22.4; also elsewhere on the board
~RESET: U3.9 (~PE); also elsewhere on the board

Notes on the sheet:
FLAGS REGISTER
INSTRUCTION REGISTER
STEP COUNTER

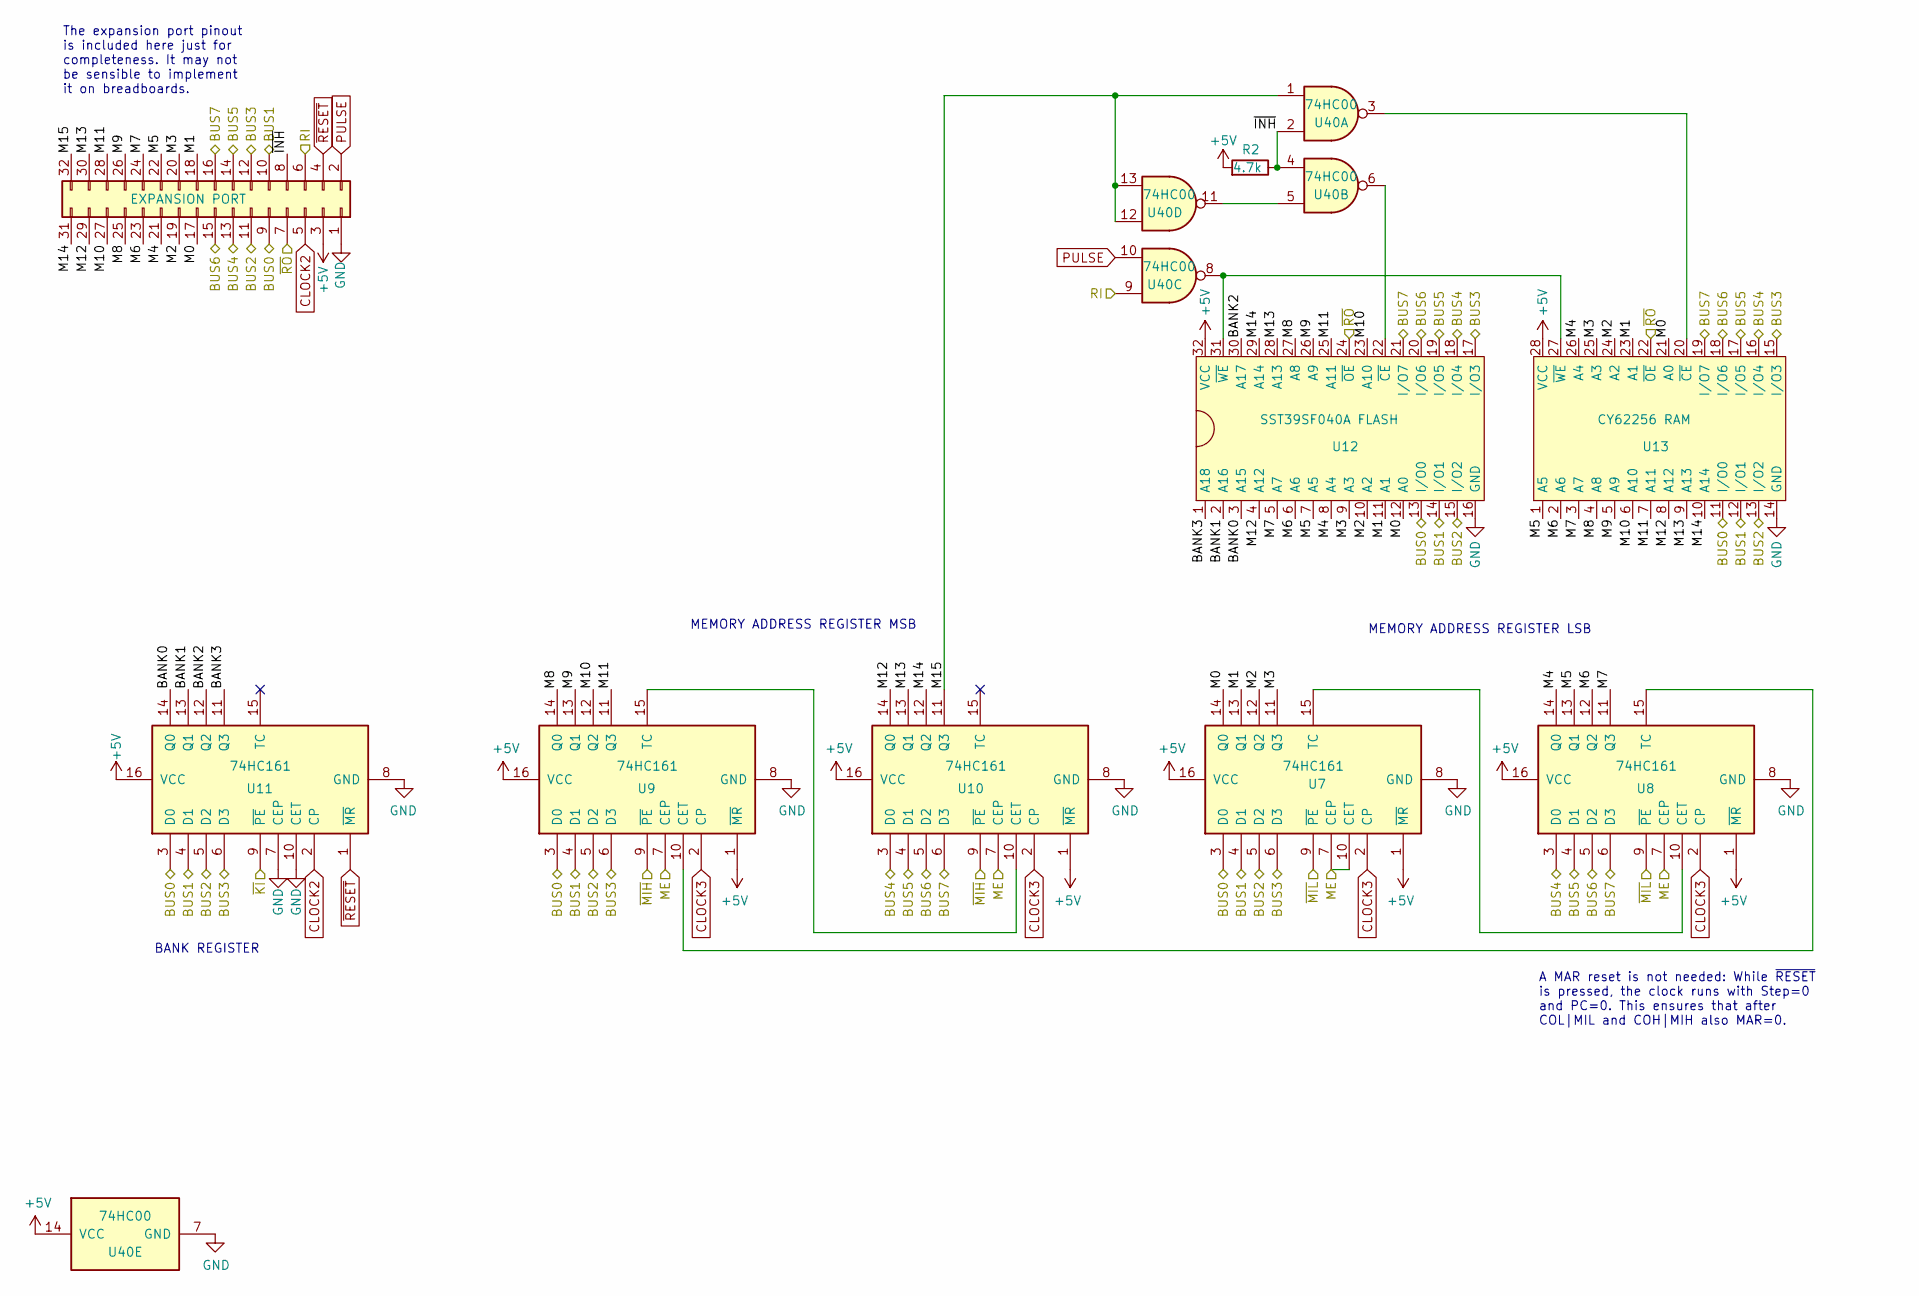
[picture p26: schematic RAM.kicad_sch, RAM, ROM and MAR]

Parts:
J2: EXPANSION PORT; PinSocket_2x16_P2.54mm_Vertical
R2: 4.7k; R_Axial_DIN0207_L6.3mm_D2.5mm_P7.62mm_Horizontal
U7, U8, U9, U10, U11: 74HC161; DIP-16_W7.62mm
U12: SST39SF040A FLASH; DIP-32_W15.24mm_Socket
U13: CY62256 RAM; DIP-28_W15.24mm
U40: 74HC00; DIP-14_W7.62mm

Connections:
+5V: J2.3, R2.2, U7.1 (~MR), U7.16 (VCC), U8.1 (~MR), U8.16 (VCC), U9.1 (~MR), U9.16 (VCC), U10.1 (~MR), U10.16 (VCC), U11.16 (VCC), U12.32 (VCC), U13.28 (VCC), U40.14 (VCC); also elsewhere on the board
/ALU/BUS0: J2.9, U7.3 (D0), U9.3 (D0), U11.3 (D0), U12.13 (I/O0), U13.11 (I/O0); also elsewhere on the board
/ALU/BUS1: J2.10, U7.4 (D1), U9.4 (D1), U11.4 (D1), U12.14 (I/O1), U13.12 (I/O1); also elsewhere on the board
/ALU/BUS2: J2.11, U7.5 (D2), U9.5 (D2), U11.5 (D2), U12.15 (I/O2), U13.13 (I/O2); also elsewhere on the board
/ALU/BUS3: J2.12, U7.6 (D3), U9.6 (D3), U11.6 (D3), U12.17 (I/O3), U13.15 (I/O3); also elsewhere on the board
/ALU/BUS4: J2.13, U8.3 (D0), U10.3 (D0), U12.18 (I/O4), U13.16 (I/O4); also elsewhere on the board
/ALU/BUS5: J2.14, U8.4 (D1), U10.4 (D1), U12.19 (I/O5), U13.17 (I/O5); also elsewhere on the board
/ALU/BUS6: J2.15, U8.5 (D2), U10.5 (D2), U12.20 (I/O6), U13.18 (I/O6); also elsewhere on the board
/ALU/BUS7: J2.16, U8.6 (D3), U10.6 (D3), U12.21 (I/O7), U13.19 (I/O7); also elsewhere on the board
/Control Logic/ME: U7.7 (CEP), U7.10 (CET), U8.7 (CEP), U9.7 (CEP), U10.7 (CEP); also elsewhere on the board
/Control Logic/RI: J2.6, U40.9; also elsewhere on the board
/Control Logic/~KI: U11.9 (~PE); also elsewhere on the board
/Control Logic/~MIH: U9.9 (~PE), U10.9 (~PE); also elsewhere on the board
/Control Logic/~MIL: U7.9 (~PE), U8.9 (~PE); also elsewhere on the board
/Control Logic/~RO: J2.7, U12.24 (~OE), U13.22 (~OE); also elsewhere on the board
/Memory/BANK0: U11.14 (Q0), U12.3 (A15)
/Memory/BANK1: U11.13 (Q1), U12.2 (A16)
/Memory/BANK2: U11.12 (Q2), U12.30 (A17)
/Memory/BANK3: U11.11 (Q3), U12.1 (A18)
/Memory/M0: J2.17, U7.14 (Q0), U12.12 (A0), U13.21 (A0)
/Memory/M1: J2.18, U7.13 (Q1), U12.11 (A1), U13.23 (A1)
/Memory/M2: J2.19, U7.12 (Q2), U12.10 (A2), U13.24 (A2)
/Memory/M3: J2.20, U7.11 (Q3), U12.9 (A3), U13.25 (A3)
/Memory/M4: J2.21, U8.14 (Q0), U12.8 (A4), U13.26 (A4)
/Memory/M5: J2.22, U8.13 (Q1), U12.7 (A5), U13.1 (A5)
/Memory/M6: J2.23, U8.12 (Q2), U12.6 (A6), U13.2 (A6)
/Memory/M7: J2.24, U8.11 (Q3), U12.5 (A7), U13.3 (A7)
/Memory/M8: J2.25, U9.14 (Q0), U12.27 (A8), U13.4 (A8)
/Memory/M9: J2.26, U9.13 (Q1), U12.26 (A9), U13.5 (A9)
/Memory/M10: J2.27, U9.12 (Q2), U12.23 (A10), U13.6 (A10)
/Memory/M11: J2.28, U9.11 (Q3), U12.25 (A11), U13.7 (A11)
/Memory/M12: J2.29, U10.14 (Q0), U12.4 (A12), U13.8 (A12)
/Memory/M13: J2.30, U10.13 (Q1), U12.28 (A13), U13.9 (A13)
/Memory/M14: J2.31, U10.12 (Q2), U12.29 (A14), U13.10 (A14)
/Memory/M15: J2.32, U10.11 (Q3), U40.1, U40.12, U40.13
/Memory/~INH: J2.8, R2.1, U40.2, U40.4
CLOCK2: J2.5, U11.2 (CP); also elsewhere on the board
CLOCK3: U7.2 (CP), U8.2 (CP), U9.2 (CP), U10.2 (CP); also elsewhere on the board
GND: J2.1, U7.8 (GND), U8.8 (GND), U9.8 (GND), U10.8 (GND), U11.7 (CEP), U11.8 (GND), U11.10 (CET), U12.16 (GND), U13.14 (GND), U40.7 (GND); also elsewhere on the board
unnamed: U7.15 (TC), U8.10 (CET)
unnamed: U8.15 (TC), U9.10 (CET)
unnamed: U9.15 (TC), U10.10 (CET)
unnamed: U12.22 (~CE), U40.6
unnamed: U12.31 (~WE), U13.27 (~WE), U40.8
unnamed: U13.20 (~CE), U40.3
unnamed: U40.5, U40.11
PULSE: J2.2, U40.10; also elsewhere on the board
~RESET: J2.4, U11.1 (~MR); also elsewhere on the board

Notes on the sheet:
MEMORY ADDRESS REGISTER MSB
A MAR reset is not needed: While ~{RESET} is pressed, the clock runs with Step=0 and PC=0. This ensures that after COL|MIL and COH|MIH also MAR=0.
MEMORY ADDRESS REGISTER LSB
BANK REGISTER
The expansion port pinout is included here just for completeness. It may not be sensible to implement it on breadboards.

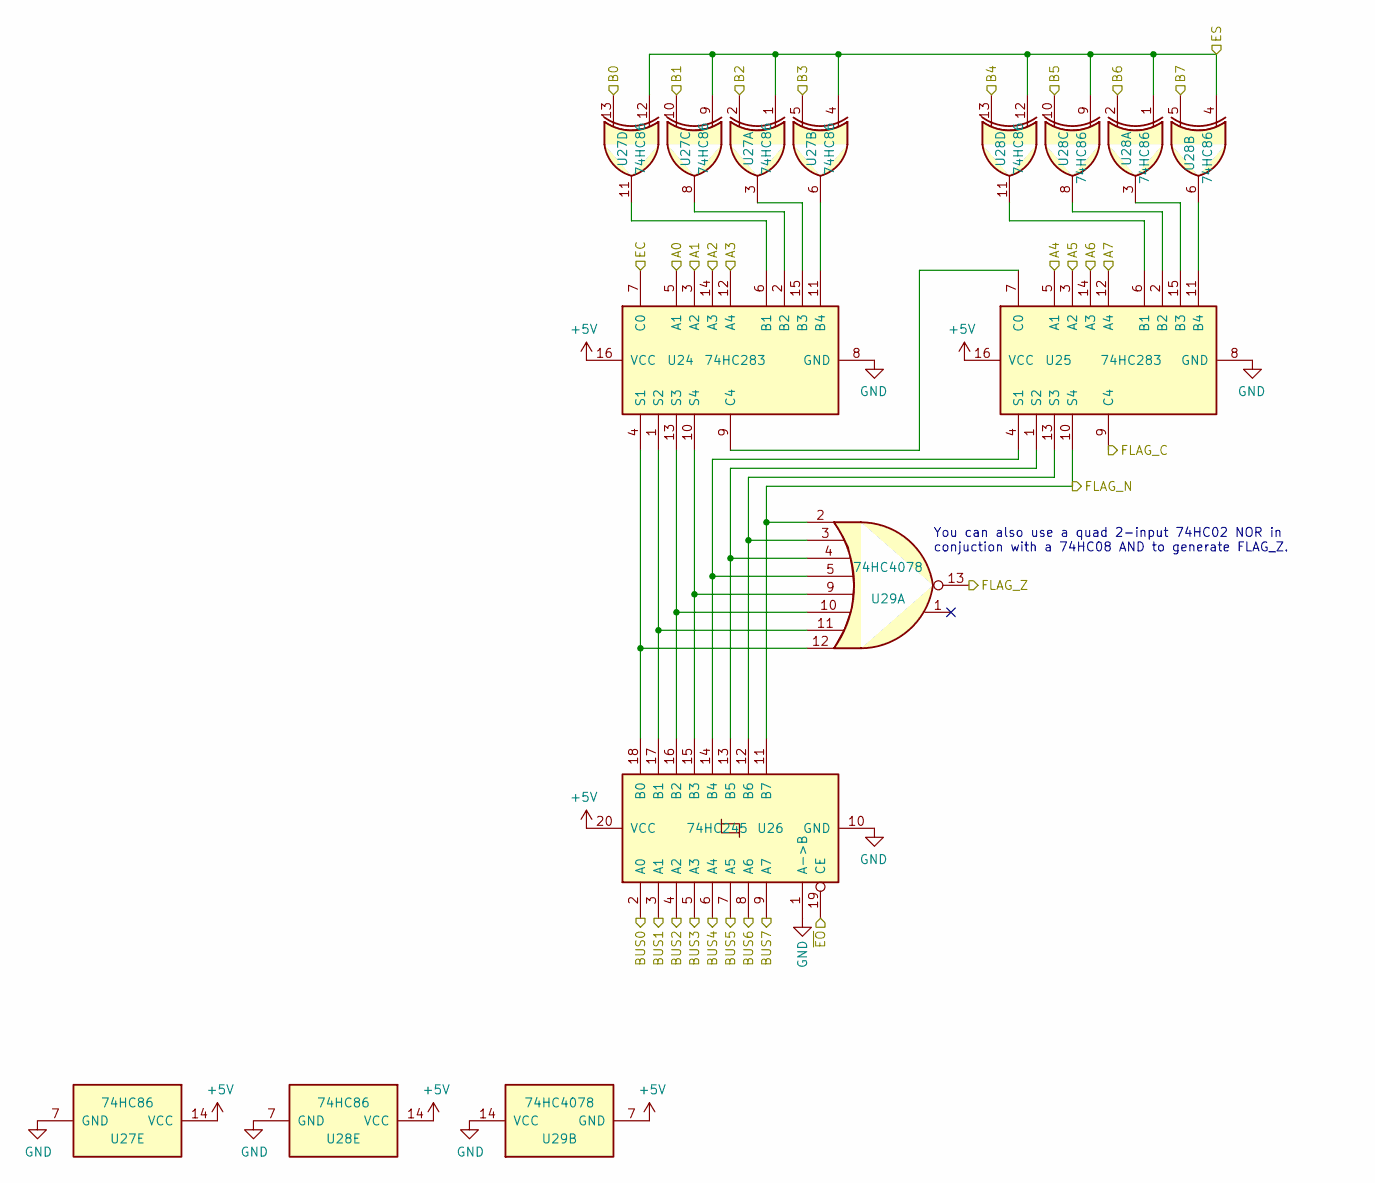
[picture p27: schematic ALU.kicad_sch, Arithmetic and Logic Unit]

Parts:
U24, U25: 74HC283; DIP-16_W7.62mm
U26: 74HC245; DIP-20_W7.62mm
U27, U28: 74HC86; DIP-14_W7.62mm
U29: 74HC4078; DIP-14_W7.62mm

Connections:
+5V: U24.16 (VCC), U25.16 (VCC), U26.20 (VCC), U27.14 (VCC), U28.14 (VCC), U29.7 (GND); also elsewhere on the board
/ALU/A0: U24.5 (A1); also elsewhere on the board
/ALU/A1: U24.3 (A2); also elsewhere on the board
/ALU/A2: U24.14 (A3); also elsewhere on the board
/ALU/A3: U24.12 (A4); also elsewhere on the board
/ALU/A4: U25.5 (A1); also elsewhere on the board
/ALU/A5: U25.3 (A2); also elsewhere on the board
/ALU/A6: U25.14 (A3); also elsewhere on the board
/ALU/A7: U25.12 (A4); also elsewhere on the board
/ALU/B0: U27.13; also elsewhere on the board
/ALU/B1: U27.10; also elsewhere on the board
/ALU/B2: U27.2; also elsewhere on the board
/ALU/B3: U27.5; also elsewhere on the board
/ALU/B4: U28.13; also elsewhere on the board
/ALU/B5: U28.10; also elsewhere on the board
/ALU/B6: U28.2; also elsewhere on the board
/ALU/B7: U28.5; also elsewhere on the board
/ALU/BUS0: U26.2 (A0); also elsewhere on the board
/ALU/BUS1: U26.3 (A1); also elsewhere on the board
/ALU/BUS2: U26.4 (A2); also elsewhere on the board
/ALU/BUS3: U26.5 (A3); also elsewhere on the board
/ALU/BUS4: U26.6 (A4); also elsewhere on the board
/ALU/BUS5: U26.7 (A5); also elsewhere on the board
/ALU/BUS6: U26.8 (A6); also elsewhere on the board
/ALU/BUS7: U26.9 (A7); also elsewhere on the board
/ALU/EC: U24.7 (C0); also elsewhere on the board
/ALU/ES: U27.1, U27.4, U27.9, U27.12, U28.1, U28.4, U28.9, U28.12; also elsewhere on the board
/ALU/FLAG_C: U25.9 (C4); also elsewhere on the board
/ALU/FLAG_N: U25.10 (S4), U26.11 (B7), U29.2; also elsewhere on the board
/ALU/FLAG_Z: U29.13; also elsewhere on the board
/ALU/~EO: U26.19 (CE); also elsewhere on the board
GND: U24.8 (GND), U25.8 (GND), U26.1 (A->B), U26.10 (GND), U27.7 (GND), U28.7 (GND), U29.14 (VCC); also elsewhere on the board
unnamed: U24.1 (S2), U26.17 (B1), U29.11
unnamed: U24.2 (B2), U27.8
unnamed: U24.4 (S1), U26.18 (B0), U29.12
unnamed: U24.6 (B1), U27.11
unnamed: U24.9 (C4), U25.7 (C0)
unnamed: U24.10 (S4), U26.15 (B3), U29.9
unnamed: U24.11 (B4), U27.6
unnamed: U24.13 (S3), U26.16 (B2), U29.10
unnamed: U24.15 (B3), U27.3
unnamed: U25.1 (S2), U26.13 (B5), U29.4
unnamed: U25.2 (B2), U28.8
unnamed: U25.4 (S1), U26.14 (B4), U29.5
unnamed: U25.6 (B1), U28.11
unnamed: U25.11 (B4), U28.6
unnamed: U25.13 (S3), U26.12 (B6), U29.3
unnamed: U25.15 (B3), U28.3

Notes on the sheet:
You can also use a quad 2-input 74HC02 NOR in conjuction with a 74HC08 AND to generate FLAG_Z.

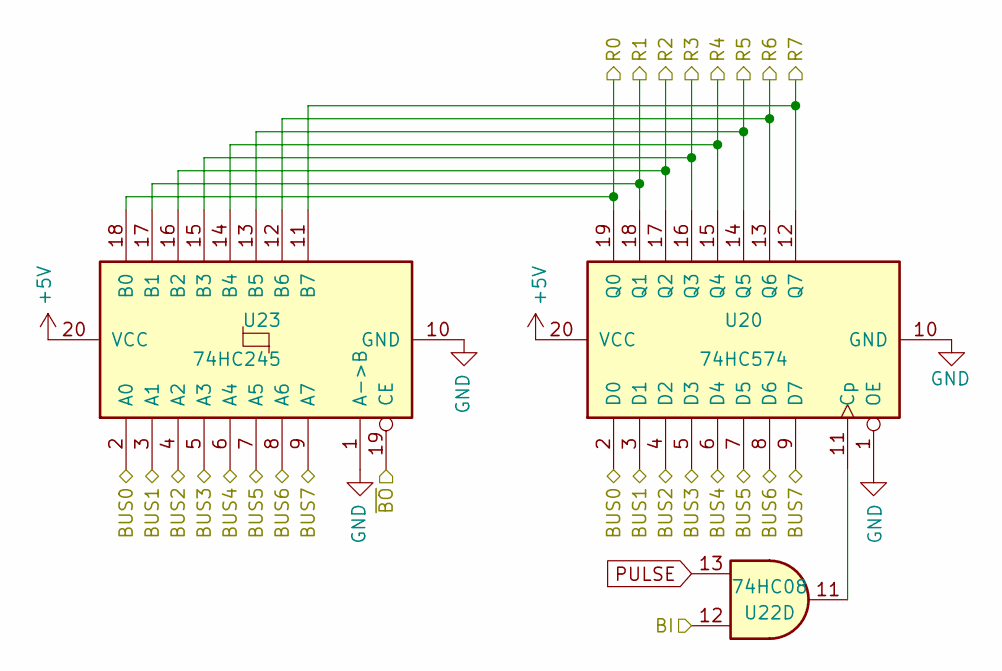
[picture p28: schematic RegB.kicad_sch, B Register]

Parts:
U20: 74HC574; DIP-20_W7.62mm
U22: 74HC08; DIP-14_W7.62mm
U23: 74HC245; DIP-20_W7.62mm

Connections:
+5V: U20.20 (VCC), U23.20 (VCC); also elsewhere on the board
/ALU/B0: U20.19 (Q0), U23.18 (B0); also elsewhere on the board
/ALU/B1: U20.18 (Q1), U23.17 (B1); also elsewhere on the board
/ALU/B2: U20.17 (Q2), U23.16 (B2); also elsewhere on the board
/ALU/B3: U20.16 (Q3), U23.15 (B3); also elsewhere on the board
/ALU/B4: U20.15 (Q4), U23.14 (B4); also elsewhere on the board
/ALU/B5: U20.14 (Q5), U23.13 (B5); also elsewhere on the board
/ALU/B6: U20.13 (Q6), U23.12 (B6); also elsewhere on the board
/ALU/B7: U20.12 (Q7), U23.11 (B7); also elsewhere on the board
/ALU/BUS0: U20.2 (D0), U23.2 (A0); also elsewhere on the board
/ALU/BUS1: U20.3 (D1), U23.3 (A1); also elsewhere on the board
/ALU/BUS2: U20.4 (D2), U23.4 (A2); also elsewhere on the board
/ALU/BUS3: U20.5 (D3), U23.5 (A3); also elsewhere on the board
/ALU/BUS4: U20.6 (D4), U23.6 (A4); also elsewhere on the board
/ALU/BUS5: U20.7 (D5), U23.7 (A5); also elsewhere on the board
/ALU/BUS6: U20.8 (D6), U23.8 (A6); also elsewhere on the board
/ALU/BUS7: U20.9 (D7), U23.9 (A7); also elsewhere on the board
/Control Logic/BI: U22.12; also elsewhere on the board
/Control Logic/~BO: U23.19 (CE); also elsewhere on the board
GND: U20.1 (OE), U20.10 (GND), U23.1 (A->B), U23.10 (GND); also elsewhere on the board
unnamed: U20.11 (Cp), U22.11
PULSE: U22.13; also elsewhere on the board

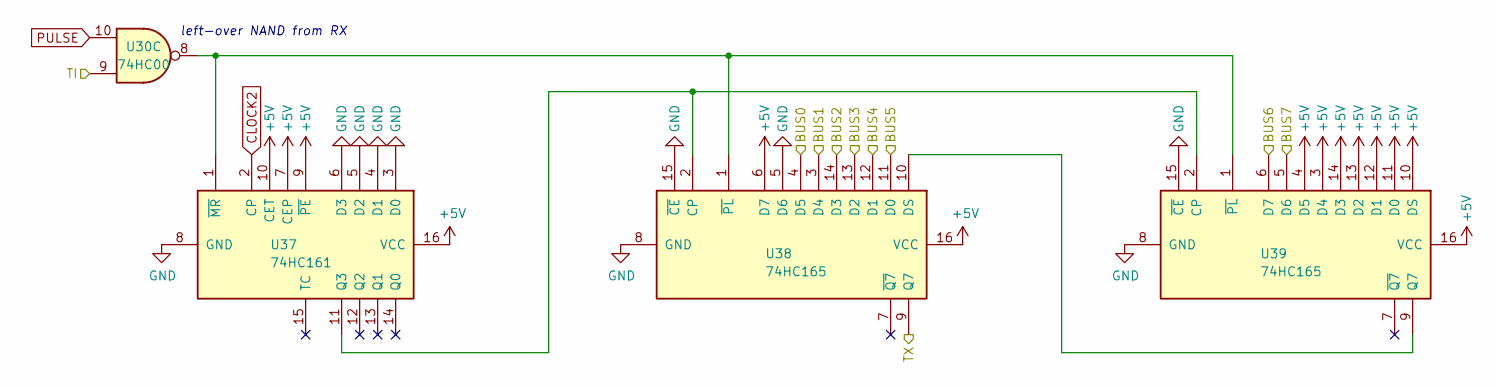
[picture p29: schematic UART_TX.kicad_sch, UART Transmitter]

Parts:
U30: 74HC00; DIP-14_W7.62mm
U37: 74HC161; DIP-16_W7.62mm
U38, U39: 74HC165; DIP-16_W7.62mm

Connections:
+5V: U37.7 (CEP), U37.9 (~PE), U37.10 (CET), U37.16 (VCC), U38.6 (D7), U38.16 (VCC), U39.3 (D4), U39.4 (D5), U39.10 (DS), U39.11 (D0), U39.12 (D1), U39.13 (D2), U39.14 (D3), U39.16 (VCC); also elsewhere on the board
/ALU/BUS0: U38.4 (D5); also elsewhere on the board
/ALU/BUS1: U38.3 (D4); also elsewhere on the board
/ALU/BUS2: U38.14 (D3); also elsewhere on the board
/ALU/BUS3: U38.13 (D2); also elsewhere on the board
/ALU/BUS4: U38.12 (D1); also elsewhere on the board
/ALU/BUS5: U38.11 (D0); also elsewhere on the board
/ALU/BUS6: U39.6 (D7); also elsewhere on the board
/ALU/BUS7: U39.5 (D6); also elsewhere on the board
/Control Logic/TI: U30.9; also elsewhere on the board
/UART Transmitter/TX: U38.9 (Q7); also elsewhere on the board
CLOCK2: U37.2 (CP); also elsewhere on the board
GND: U37.3 (D0), U37.4 (D1), U37.5 (D2), U37.6 (D3), U37.8 (GND), U38.5 (D6), U38.8 (GND), U38.15 (~CE), U39.8 (GND), U39.15 (~CE); also elsewhere on the board
unnamed: U30.8, U37.1 (~MR), U38.1 (~PL), U39.1 (~PL)
unnamed: U37.11 (Q3), U38.2 (CP), U39.2 (CP)
unnamed: U38.10 (DS), U39.9 (Q7)
PULSE: U30.10; also elsewhere on the board

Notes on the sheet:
left-over NAND from RX

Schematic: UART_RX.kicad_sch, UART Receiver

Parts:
U30: 74HC00; DIP-14_W7.62mm
U33: 74HC161; DIP-16_W7.62mm
U34: 74HC193; DIP-16_W7.62mm
U35: 74HC595; DIP-16_W7.62mm

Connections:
+5V: U30.14 (VCC), U33.7 (CEP), U33.9 (~PE), U33.16 (VCC), U34.1 (D1), U34.5 (CPU), U34.9 (D3), U34.16 (VCC), U35.10 (~SRCLR), U35.16 (VCC); also elsewhere on the board
/ALU/BUS0: U35.7 (QH); also elsewhere on the board
/ALU/BUS1: U35.6 (QG); also elsewhere on the board
/ALU/BUS2: U35.5 (QF); also elsewhere on the board
/ALU/BUS3: U35.4 (QE); also elsewhere on the board
/ALU/BUS4: U35.3 (QD); also elsewhere on the board
/ALU/BUS5: U35.2 (QC); also elsewhere on the board
/ALU/BUS6: U35.1 (QB); also elsewhere on the board
/ALU/BUS7: U35.15 (QA); also elsewhere on the board
/Control Logic/BUSY: U33.10 (CET), U34.13 (~TCD); also elsewhere on the board
/Control Logic/~TO: U30.5, U35.13 (~OE); also elsewhere on the board
/UART Receiver/RTS: U30.3, U30.4, U33.1 (~MR), U34.11 (~PL); also elsewhere on the board
/UART Receiver/RX: U30.1, U35.14 (SER); also elsewhere on the board
CLOCK2: U33.2 (CP); also elsewhere on the board
GND: U30.7 (GND), U30.12, U30.13, U33.3 (D0), U33.4 (D1), U33.5 (D2), U33.6 (D3), U33.8 (GND), U34.8 (GND), U34.10 (D2), U34.14 (MR), U34.15 (D0), U35.8 (GND); also elsewhere on the board
unnamed: U30.2, U30.6
unnamed: U33.11 (Q3), U34.4 (CPD), U35.11 (SRCLK), U35.12 (RCLK)

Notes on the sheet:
DESCRIPTION OF THE DATA ACQUISITION CYCLE: 1) Prior to receiving a datum: Q=LOW is reseting the timer and loading "9" into the bit counter. This also implies ~{TCD}=BUSY=HIGH. 2) An incoming datum, starting with a falling edge at RX, sets Q=HIGH, ending the reset of the timer and the loading of the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
The order of the bits is intentionally reversed.
You can connect the RTS output ("I am ready to receive") to the CTS input ("You are clear to send" input) of your receiver IC and use RTS/CTS flow control. Only CH340G ICs seem to work.
~{Q}
left-over NAND used in TX
~{TCD}=BUSY goes LOW with the falling edge of CPD. Nominally, this coincides with the rising edge of the first stop bit.
~{S}
~{R}

Board: 2 copper layers, 46 parts (0 on the bottom side), 150 nets, no tracks yet.

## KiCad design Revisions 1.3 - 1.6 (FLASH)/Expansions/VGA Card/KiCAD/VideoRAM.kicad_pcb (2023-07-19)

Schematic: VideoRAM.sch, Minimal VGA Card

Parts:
C1: 47µF; CP_Radial_D6.3mm_P2.50mm
C2, C3, C4, C5, C6, C7, C8, C9, C10, C12, C13, C14: 100nF; C_Disc_D3.8mm_W2.6mm_P2.50mm
C11: 100pF; C_Disc_D3.8mm_W2.6mm_P2.50mm
J1: EXPANSION PORT; PinSocket_2x16_P2.54mm_Vertical
J2: VGA connector; VGA DSUB15HD_female
J3: EXT CLOCK; PinHeader_1x02_P2.54mm_Vertical
R1, R2: 75; R_Axial_DIN0207_L6.3mm_D2.5mm_P7.62mm_Horizontal
R3: 150; R_Axial_DIN0207_L6.3mm_D2.5mm_P7.62mm_Horizontal
U1, U8: 74HC32; DIP-14_W7.62mm
U2, U4: 74HC21; DIP-14_W7.62mm
U3: 74HC04; DIP-14_W7.62mm
U5, U6: 74HC590; DIP-16_W7.62mm
U7, U11, U19: 74HC00; DIP-14_W7.62mm
U9, U10, U14: 74HC245; DIP-20_W7.62mm
U12: CY62256; DIP-28_W15.24mm
U13: 74HC165; DIP-16_W7.62mm
U15, U16, U17, U18: 74HC173; DIP-16_W7.62mm

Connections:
2MHz: U3.4, U5.11 (CPC), U5.13 (CPR), U6.11 (CPC), U6.13 (CPR), U15.7 (Cp), U16.7 (Cp), U17.7 (Cp), U18.7 (Cp)
4MHz: C11.1, J3.1, U1.12
16MHz: J3.2, U11.9, U11.10
+5V: C1.1, C2.1, C3.1, C4.1, C5.1, C6.1, C7.1, C8.1, C9.1, C10.1, C12.1, C13.1, C14.1, J1.3, U1.14 (VCC), U2.14, U3.14 (VCC), U4.14, U5.16 (VCC), U6.16 (VCC), U7.14 (VCC), U8.14 (VCC), U9.20 (VCC), U10.20 (VCC), U11.14 (VCC), U12.28 (VCC), U13.16 (VCC), U14.20 (VCC), U15.16 (VCC), U16.16 (VCC), U17.16 (VCC), U18.16 (VCC), U19.14 (VCC)
/Bus0: J1.9, U14.18 (B0), U16.14 (D0), U18.14 (D0)
/Bus1: J1.10, U14.17 (B1), U16.13 (D1), U18.13 (D1)
/Bus2: J1.11, U14.16 (B2), U16.12 (D2), U18.12 (D2)
/Bus3: J1.12, U14.15 (B3), U16.11 (D3), U18.11 (D3)
/Bus4: J1.13, U14.14 (B4), U15.14 (D0), U17.14 (D0)
/Bus5: J1.14, U14.13 (B5), U15.13 (D1), U17.13 (D1)
/Bus6: J1.15, U14.12 (B6), U15.12 (D2), U17.12 (D2)
/Bus7: J1.16, U14.11 (B7), U15.11 (D3), U17.11 (D3)
/CLOCK: J1.5, U1.13, U3.1
/H1: U6.15 (Q0), U10.18 (B0)
/H2: U6.1 (Q1), U10.17 (B1)
/H4: U6.2 (Q2), U10.16 (B2)
/H8: U1.2, U6.3 (Q3), U10.15 (B3)
/H16: U1.1, U6.4 (Q4), U10.14 (B4)
/H32: U1.5, U6.5 (Q5), U10.13 (B5)
/M2: J1.19, U11.12
/M3: J1.20, U2.9
/M4: J1.21, U2.1
/M5: J1.22, U2.2
/M6: J1.23, U2.4
/M7: J1.24, U2.5
/M8: J1.25, U4.9
/M9: J1.26, U4.10
/M10: J1.27, U4.12
/M11: J1.28, U4.13
/M12: J1.29, U4.1
/M13: J1.30, U3.9
/M14: J1.31, U4.4
/M15: J1.32, U4.5
/RI: J1.6, U3.5, U8.1
/RO: U3.10, U8.2, U14.1 (A->B)
/V1: U6.7 (Q7), U7.12, U7.13, U10.11 (B7)
/V2: U5.15 (Q0), U9.18 (B0)
/V4: U5.1 (Q1), U7.1, U9.17 (B1)
/V8: U5.2 (Q2), U9.16 (B2)
/V16: U5.3 (Q3), U9.15 (B3)
/V32: U5.4 (Q4), U9.14 (B4)
/V64: U5.5 (Q5), U9.13 (B5)
/V128: U5.6 (Q6), U9.12 (B6)
/V256: U5.7 (Q7), U7.2, U9.11 (B7)
/~INH: J1.8, U8.5, U8.13, U11.11
/~RI: U3.6, U8.12, U15.10 (E2), U16.10 (E2), U17.10 (E2), U18.10 (E2)
/~RO: J1.7, U3.11
GND: C1.2, C2.2, C3.2, C4.2, C5.2, C6.2, C7.2, C8.2, C9.2, C10.2, C11.2, C12.2, C13.2, C14.2, J1.1, J2.5, J2.6, J2.7, J2.8, J2.10, U1.7 (GND), U2.7, U3.7 (GND), U3.13, U4.7, U5.8 (GND), U5.14 (~OE), U6.8 (GND), U6.12 (~CE), U6.14 (~OE), U7.7 (GND), U8.7 (GND), U9.1 (A->B), U9.10 (GND), U10.1 (A->B), U10.10 (GND), U11.7 (GND), U12.10 (A14), U12.14 (GND), U12.20 (~CE), U12.22 (~OE), U13.8 (GND), U13.10 (DS), U13.15 (~CE), U14.10 (GND), U15.8 (GND), U15.15 (Mr), U16.8 (GND), U16.15 (Mr), U17.8 (GND), U17.15 (Mr), U18.8 (GND), U18.15 (Mr), U19.7 (GND), U19.12, U19.13
unnamed: J2.1, J2.2, J2.3, R3.1
unnamed: J2.13, R2.1
unnamed: J2.14, R1.1
unnamed: R1.2, U7.5, U7.8
unnamed: R2.2, U1.6
unnamed: R3.2, U13.9 (Q7)
unnamed: U1.3, U1.4
unnamed: U1.9, U1.10, U1.11, U19.5
unnamed: U2.6, U2.10
unnamed: U2.12, U4.8
unnamed: U2.13, U4.6
unnamed: U3.8, U4.2
unnamed: U5.10 (~MRC), U6.10 (~MRC), U7.3, U7.4
unnamed: U5.12 (~CE), U6.9 (~RCO)
unnamed: U7.6, U7.9
unnamed: U7.10, U7.11
unnamed: U8.10, U8.11
unnamed: U10.2 (A0), U12.21 (A0), U18.3 (Q0)
unnamed: U10.3 (A1), U12.23 (A1), U18.4 (Q1)
unnamed: U10.4 (A2), U12.24 (A2), U18.5 (Q2)
unnamed: U10.5 (A3), U12.25 (A3), U18.6 (Q3)
unnamed: U10.6 (A4), U12.26 (A4), U17.3 (Q0)
unnamed: U10.7 (A5), U12.1 (A5), U17.4 (Q1)
unnamed: U10.9 (A7), U12.2 (A6), U17.5 (Q2)
unnamed: U6.6 (Q6), U10.12 (B6)
unnamed: U11.3, U17.9 (E1), U18.9 (E1)
unnamed: U11.6, U15.9 (E1), U16.9 (E1)
unnamed: U9.2 (A0), U12.3 (A7), U17.6 (Q3)
unnamed: U9.3 (A1), U12.4 (A8), U16.3 (Q0)
unnamed: U9.4 (A2), U12.5 (A9), U16.4 (Q1)
unnamed: U9.5 (A3), U12.6 (A10), U16.5 (Q2)
unnamed: U9.6 (A4), U12.7 (A11), U16.6 (Q3)
unnamed: U9.7 (A5), U12.8 (A12), U15.3 (Q0)
unnamed: U9.8 (A6), U12.9 (A13), U15.4 (Q1)
unnamed: U12.11 (I/O0), U13.11 (D0), U14.2 (A0)
unnamed: U12.12 (I/O1), U13.12 (D1), U14.3 (A1)
unnamed: U12.13 (I/O2), U13.13 (D2), U14.4 (A2)
unnamed: U12.15 (I/O3), U13.14 (D3), U14.5 (A3)
unnamed: U12.16 (I/O4), U13.3 (D4), U14.6 (A4)
unnamed: U12.17 (I/O5), U13.4 (D5), U14.7 (A5)
unnamed: U12.18 (I/O6), U13.5 (D6), U14.8 (A6)
unnamed: U12.19 (I/O7), U13.6 (D7), U14.9 (A7)
unnamed: U8.8, U12.27 (~WE)
unnamed: U13.1 (~PL), U19.6
unnamed: U8.6, U14.19 (CE)
unnamed: U8.4, U19.8
unnamed: U8.3, U19.9
PIXEL: U11.8, U13.2 (CP)
T_VRAM: U1.8, U9.19 (CE), U10.19 (CE), U19.1, U19.2, U19.10
~2MHz: U3.2, U3.3, U8.9
~T_VRAM: U15.1 (Oe1), U15.2 (Oe2), U16.1 (Oe1), U16.2 (Oe2), U17.1 (Oe1), U17.2 (Oe2), U18.1 (Oe1), U18.2 (Oe2), U19.3, U19.4

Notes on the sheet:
~HSYNC
~VSYNC
During the first phase, the VRAM address is controlled by the timer.
During the second phase, the VRAM address is controlled by the MSB/LSB access register.
The address LSB is sampled from the bus if ~VGA_RANGE~=LOW and M0=1, e. g. MAR=0xdff9, and RI is active.
~PL~ happens in the middle of the first half of the clock cycle when the VRAM output is still controlled by the VGA timer.
The address MSB is sampled from the bus if ~VGA_RANGE~=LOW and M1=1, e. g. MAR=0xdffa, and RI is active.
~INH~ is only LOW if MAR = 0b11011111111111xx = 0xdffc-0xdfff, i. e. data I/O ~INH~ deactivates RAM/FLASH access on the main board.
Buffer is only active while VRAM is accessed by th CPU. In case of a write access (RI) the data on the bus is present on the RAM's I/O lines. At the same time ~WE~ is LOW forcing the RAM's I/O lines to read mode. In case of a read access (RO) data from the RAM's I/O lines drives the bus.
For a stable ~PL~, signals must rise simultaneously. Since CLOCK drives a lot of ICs, 4MHz needs an additional capacitive load.
buffers the system clock to reduce capacitive load
aligns pixel shift with parallel load
VGA_RANGE is HIGH if MAR = 0b1101111111111xxx = 0xdff8-0xdfff

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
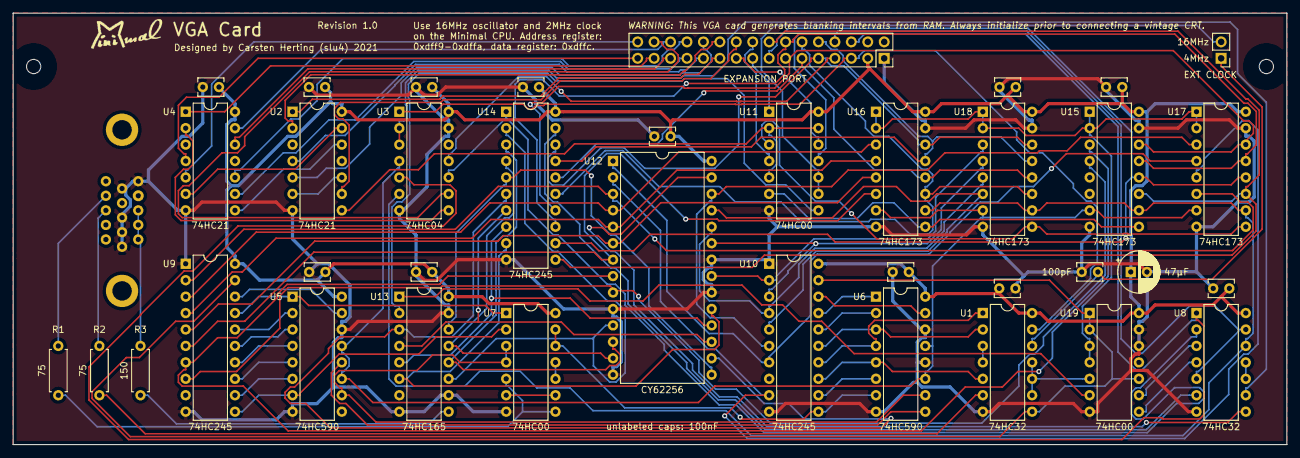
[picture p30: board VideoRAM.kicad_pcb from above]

Board: 2 copper layers, 196.8 x 66.7 mm, 41 parts (0 on the bottom side), 102 nets.

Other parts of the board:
REF1, REF2: MountingHole_2.2mm_M2

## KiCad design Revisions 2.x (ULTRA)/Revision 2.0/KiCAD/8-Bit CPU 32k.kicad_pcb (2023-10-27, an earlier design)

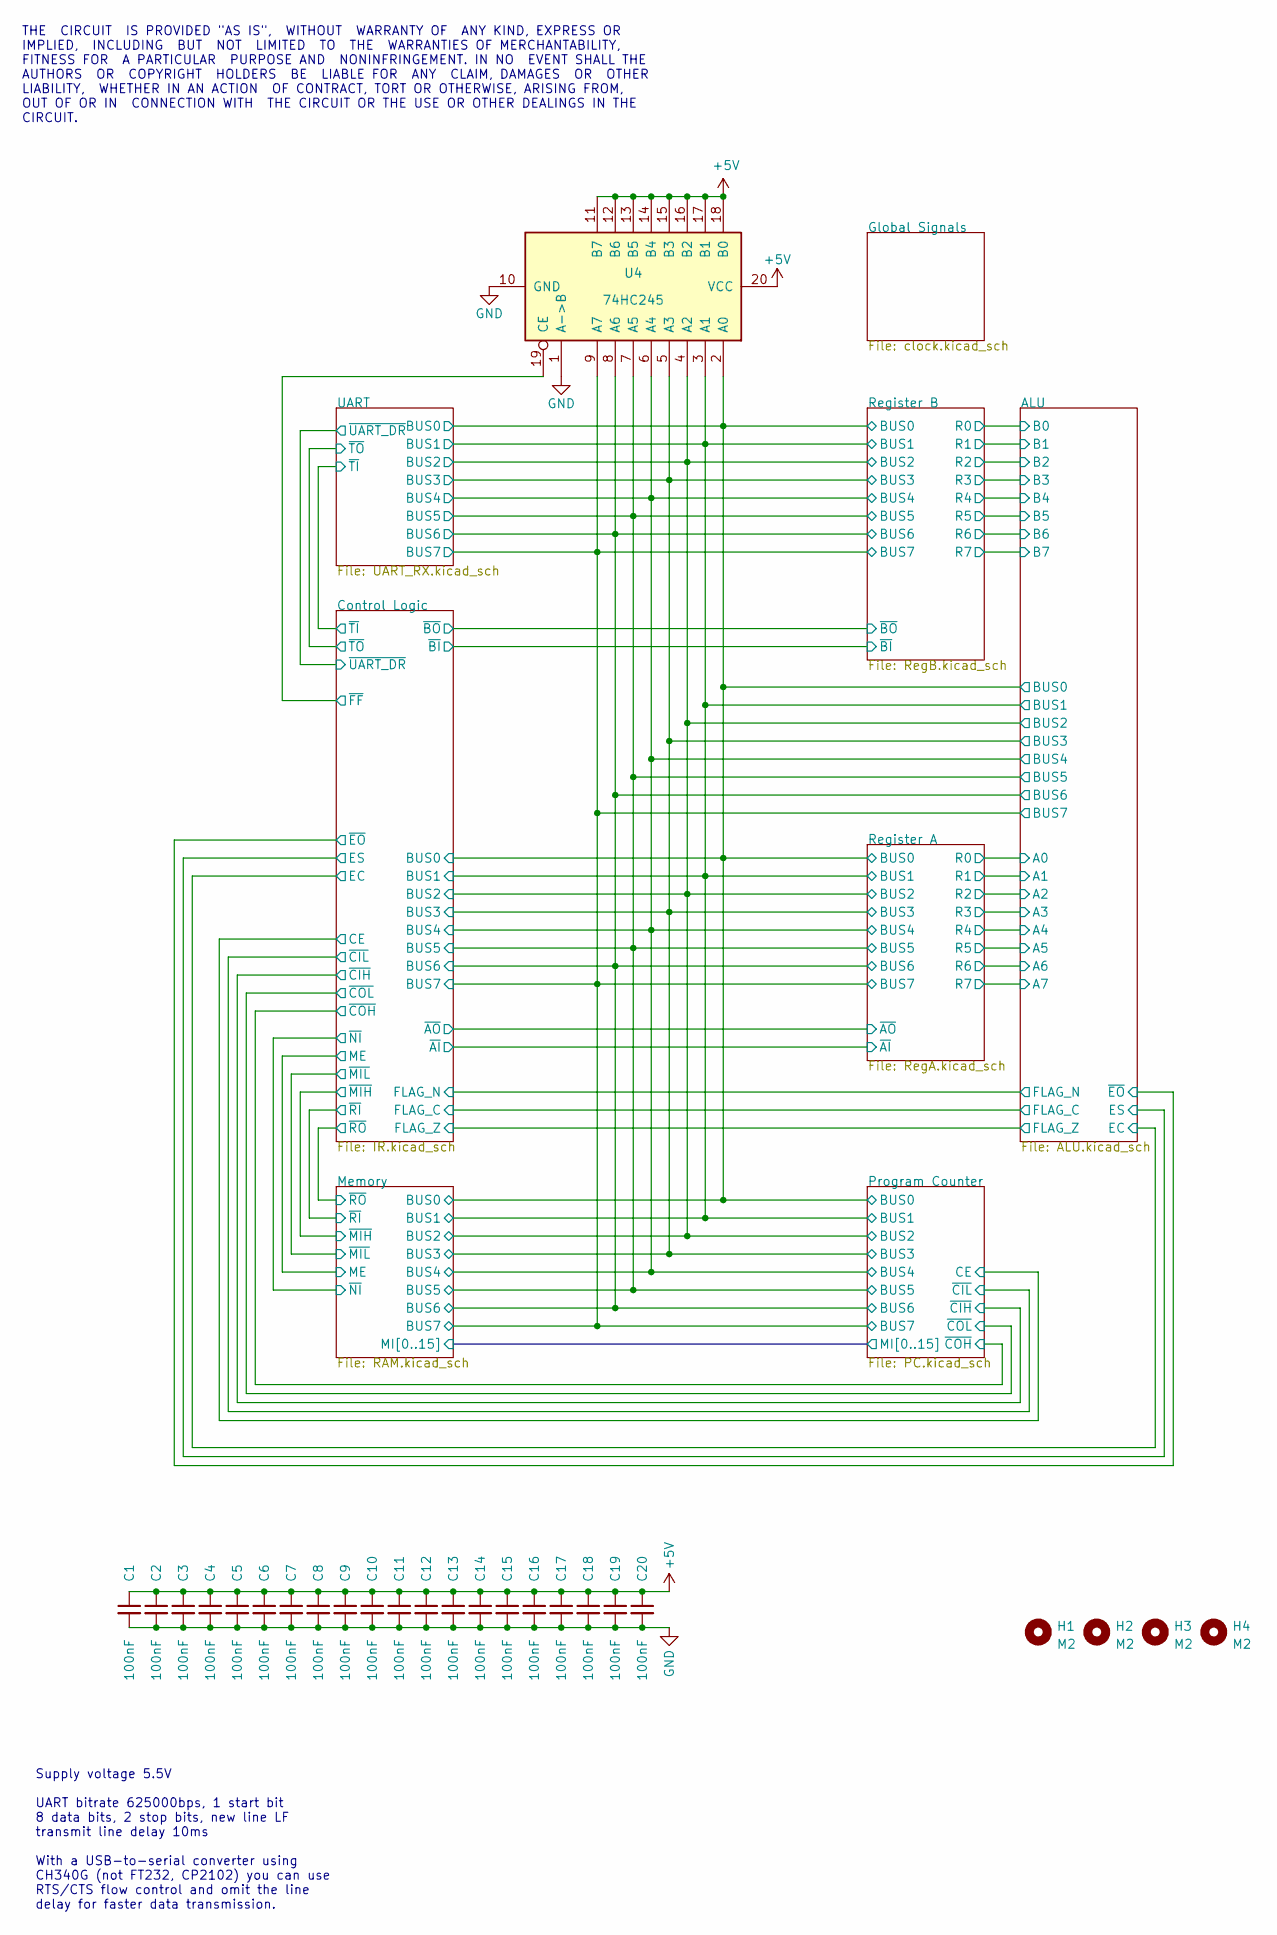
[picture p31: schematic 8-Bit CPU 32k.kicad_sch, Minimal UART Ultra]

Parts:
C1, C2, C3, C4, C5, C6, C7, C8, C9, C10, C11, C12, C13, C14, C15, C16, C17, C18, C19, C20: 100nF; C_Disc_D3.4mm_W2.1mm_P2.50mm
H1, H2, H3, H4: M2; MountingHole_2.2mm_M2
U4: 74HC245; DIP-20_W7.62mm

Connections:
+5V: C1.1, C2.1, C3.1, C4.1, C5.1, C6.1, C7.1, C8.1, C9.1, C10.1, C11.1, C12.1, C13.1, C14.1, C15.1, C16.1, C17.1, C18.1, C19.1, C20.1, U4.11 (B7), U4.12 (B6), U4.13 (B5), U4.14 (B4), U4.15 (B3), U4.16 (B2), U4.17 (B1), U4.18 (B0), U4.20 (VCC); also elsewhere on the board
/ALU/BUS0: U4.2 (A0); also elsewhere on the board
/ALU/BUS1: U4.3 (A1); also elsewhere on the board
/ALU/BUS2: U4.4 (A2); also elsewhere on the board
/ALU/BUS3: U4.5 (A3); also elsewhere on the board
/ALU/BUS4: U4.6 (A4); also elsewhere on the board
/ALU/BUS5: U4.7 (A5); also elsewhere on the board
/ALU/BUS6: U4.8 (A6); also elsewhere on the board
/ALU/BUS7: U4.9 (A7); also elsewhere on the board
/Control Logic/~FF: U4.19 (CE); also elsewhere on the board
GND: C1.2, C2.2, C3.2, C4.2, C5.2, C6.2, C7.2, C8.2, C9.2, C10.2, C11.2, C12.2, C13.2, C14.2, C15.2, C16.2, C17.2, C18.2, C19.2, C20.2, U4.1 (A->B), U4.10 (GND); also elsewhere on the board

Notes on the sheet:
Supply voltage 5.5V UART bitrate 625000bps, 1 start bit 8 data bits, 2 stop bits, new line LF transmit line delay 10ms With a USB-to-serial converter using CH340G (not FT232, CP2102) you can use RTS/CTS flow control and omit the line delay for faster data transmission.
THE CIRCUIT IS PROVIDED "AS IS", WITHOUT WARRANTY OF ANY KIND, EXPRESS OR IMPLIED, INCLUDING BUT NOT LIMITED TO THE WARRANTIES OF MERCHANTABILITY, FITNESS FOR A PARTICULAR PURPOSE AND NONINFRINGEMENT. IN NO EVENT SHALL THE AUTHORS OR COPYRIGHT HOLDERS BE LIABLE FOR ANY CLAIM, DAMAGES OR OTHER LIABI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


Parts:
U14, U15, U18, U23: 74HC161; DIP-16_W7.62mm
U17, U21, U36, U44: 74HC245; DIP-20_W7.62mm
U40: 74HC02; DIP-14_W7.62mm

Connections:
+5V: U14.10 (CET), U14.16 (VCC), U15.16 (VCC), U17.20 (VCC), U18.16 (VCC), U21.20 (VCC), U23.16 (VCC), U36.20 (VCC), U44.20 (VCC); also elsewhere on the board
/ALU/BUS0: U14.3 (D0), U18.3 (D0), U36.2 (A0), U44.2 (A0); also elsewhere on the board
/ALU/BUS1: U14.4 (D1), U18.4 (D1), U36.3 (A1), U44.3 (A1); also elsewhere on the board
/ALU/BUS2: U14.5 (D2), U18.5 (D2), U36.4 (A2), U44.4 (A2); also elsewhere on the board
/ALU/BUS3: U14.6 (D3), U18.6 (D3), U36.5 (A3), U44.5 (A3); also elsewhere on the board
/ALU/BUS4: U15.3 (D0), U23.3 (D0), U36.6 (A4), U44.6 (A4); also elsewhere on the board
/ALU/BUS5: U15.4 (D1), U23.4 (D1), U36.7 (A5), U44.7 (A5); also elsewhere on the board
/ALU/BUS6: U15.5 (D2), U23.5 (D2), U36.8 (A6), U44.8 (A6); also elsewhere on the board
/ALU/BUS7: U15.6 (D3), U23.6 (D3), U36.9 (A7), U44.9 (A7); also elsewhere on the board
/Control Logic/CE: U14.7 (CEP), U15.7 (CEP), U18.7 (CEP), U23.7 (CEP); also elsewhere on the board
/Control Logic/~CIH: U18.9 (~PE), U23.9 (~PE); also elsewhere on the board
/Control Logic/~CIL: U14.9 (~PE), U15.9 (~PE); also elsewhere on the board
/Control Logic/~COH: U17.19 (CE), U36.1 (A->B), U40.12; also elsewhere on the board
/Control Logic/~COL: U21.19 (CE), U40.11, U44.1 (A->B); also elsewhere on the board
/Memory/MI0: U21.2 (A0), U44.18 (B0); also elsewhere on the board
/Memory/MI1: U21.3 (A1), U44.17 (B1); also elsewhere on the board
/Memory/MI2: U21.4 (A2), U44.16 (B2); also elsewhere on the board
/Memory/MI3: U21.5 (A3), U44.15 (B3); also elsewhere on the board
/Memory/MI4: U21.6 (A4), U44.14 (B4); also elsewhere on the board
/Memory/MI5: U21.7 (A5), U44.13 (B5); also elsewhere on the board
/Memory/MI6: U21.8 (A6), U44.12 (B6); also elsewhere on the board
/Memory/MI7: U21.9 (A7), U44.11 (B7); also elsewhere on the board
/Memory/MI8: U17.2 (A0), U36.18 (B0); also elsewhere on the board
/Memory/MI9: U17.3 (A1), U36.17 (B1); also elsewhere on the board
/Memory/MI10: U17.4 (A2), U36.16 (B2); also elsewhere on the board
/Memory/MI11: U17.5 (A3), U36.15 (B3); also elsewhere on the board
/Memory/MI12: U17.6 (A4), U36.14 (B4); also elsewhere on the board
/Memory/MI13: U17.7 (A5), U36.13 (B5); also elsewhere on the board
/Memory/MI14: U17.8 (A6), U36.12 (B6); also elsewhere on the board
/Memory/MI15: U17.9 (A7), U36.11 (B7); also elsewhere on the board
CLK_PC: U14.2 (CP), U15.2 (CP), U18.2 (CP), U23.2 (CP); also elsewhere on the board
GND: U14.8 (GND), U15.8 (GND), U17.1 (A->B), U17.10 (GND), U18.8 (GND), U21.1 (A->B), U21.10 (GND), U23.8 (GND), U36.10 (GND), U44.10 (GND); also elsewhere on the board
unnamed: U14.11 (Q3), U21.15 (B3)
unnamed: U14.12 (Q2), U21.16 (B2)
unnamed: U14.13 (Q1), U21.17 (B1)
unnamed: U14.14 (Q0), U21.18 (B0)
unnamed: U14.15 (TC), U15.10 (CET)
unnamed: U15.11 (Q3), U21.11 (B7)
unnamed: U15.12 (Q2), U21.12 (B6)
unnamed: U15.13 (Q1), U21.13 (B5)
unnamed: U15.14 (Q0), U21.14 (B4)
unnamed: U15.15 (TC), U18.10 (CET)
unnamed: U17.11 (B7), U23.11 (Q3)
unnamed: U17.12 (B6), U23.12 (Q2)
unnamed: U17.13 (B5), U23.13 (Q1)
unnamed: U17.14 (B4), U23.14 (Q0)
unnamed: U17.15 (B3), U18.11 (Q3)
unnamed: U17.16 (B2), U18.12 (Q2)
unnamed: U17.17 (B1), U18.13 (Q1)
unnamed: U17.18 (B0), U18.14 (Q0)
unnamed: U18.15 (TC), U23.10 (CET)
unnamed: U36.19 (CE), U40.13, U44.19 (CE)
~RESET: U14.1 (~MR), U15.1 (~MR), U18.1 (~MR), U23.1 (~MR); also elsewhere on the board

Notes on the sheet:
PROGRAM COUNTER MSB
PROGRAM COUNTER LSB


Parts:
U32: 74HC245; DIP-20_W7.62mm
U42, U43: 74HC161; DIP-16_W7.62mm

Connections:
+5V: U32.20 (VCC), U42.1 (~MR), U42.16 (VCC), U43.1 (~MR), U43.16 (VCC); also elsewhere on the board
/ALU/A0: U32.18 (B0), U42.14 (Q0); also elsewhere on the board
/ALU/A1: U32.17 (B1), U42.13 (Q1); also elsewhere on the board
/ALU/A2: U32.16 (B2), U42.12 (Q2); also elsewhere on the board
/ALU/A3: U32.15 (B3), U42.11 (Q3); also elsewhere on the board
/ALU/A4: U32.14 (B4), U43.14 (Q0); also elsewhere on the board
/ALU/A5: U32.13 (B5), U43.13 (Q1); also elsewhere on the board
/ALU/A6: U32.12 (B6), U43.12 (Q2); also elsewhere on the board
/ALU/A7: U32.11 (B7), U43.11 (Q3); also elsewhere on the board
/ALU/BUS0: U32.2 (A0), U42.3 (D0); also elsewhere on the board
/ALU/BUS1: U32.3 (A1), U42.4 (D1); also elsewhere on the board
/ALU/BUS2: U32.4 (A2), U42.5 (D2); also elsewhere on the board
/ALU/BUS3: U32.5 (A3), U42.6 (D3); also elsewhere on the board
/ALU/BUS4: U32.6 (A4), U43.3 (D0); also elsewhere on the board
/ALU/BUS5: U32.7 (A5), U43.4 (D1); also elsewhere on the board
/ALU/BUS6: U32.8 (A6), U43.5 (D2); also elsewhere on the board
/ALU/BUS7: U32.9 (A7), U43.6 (D3); also elsewhere on the board
/Control Logic/~AI: U42.9 (~PE), U43.9 (~PE); also elsewhere on the board
/Control Logic/~AO: U32.19 (CE); also elsewhere on the board
CLK_CTRL_AB: U42.2 (CP), U43.2 (CP); also elsewhere on the board
GND: U32.1 (A->B), U32.10 (GND), U42.7 (CEP), U42.8 (GND), U42.10 (CET), U43.7 (CEP), U43.8 (GND), U43.10 (CET); also elsewhere on the board


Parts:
U2, U3, U5, U20: 74HC161; DIP-16_W7.62mm
U6, U12, U30: SST39SF040 512KB; DIP-32_W15.24mm_Socket

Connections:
+5V: U2.1 (~MR), U2.16 (VCC), U3.7 (CEP), U3.10 (CET), U3.16 (VCC), U5.1 (~MR), U5.16 (VCC), U6.31 (~WE), U6.32 (VCC), U12.31 (~WE), U12.32 (VCC), U20.1 (~MR), U20.16 (VCC), U30.31 (~WE), U30.32 (VCC); also elsewhere on the board
/ALU/BUS0: U2.3 (D0); also elsewhere on the board
/ALU/BUS1: U2.4 (D1); also elsewhere on the board
/ALU/BUS2: U2.5 (D2); also elsewhere on the board
/ALU/BUS3: U2.6 (D3); also elsewhere on the board
/ALU/BUS4: U20.3 (D0); also elsewhere on the board
/ALU/BUS5: U20.4 (D1); also elsewhere on the board
/ALU/BUS6: U20.5 (D2); also elsewhere on the board
/ALU/BUS7: U20.6 (D3); also elsewhere on the board
/ALU/EC: U30.15 (I/O2); also elsewhere on the board
/ALU/ES: U30.14 (I/O1); also elsewhere on the board
/ALU/FLAG_C: U5.4 (D1); also elsewhere on the board
/ALU/FLAG_N: U5.5 (D2); also elsewhere on the board
/ALU/FLAG_Z: U5.3 (D0); also elsewhere on the board
/ALU/~EO: U30.13 (I/O0); also elsewhere on the board
/Control Logic/CE: U12.21 (I/O7); also elsewhere on the board
/Control Logic/Flag0: U5.14 (Q0), U6.25 (A11), U12.25 (A11), U30.25 (A11)
/Control Logic/Flag1: U5.13 (Q1), U6.4 (A12), U12.4 (A12), U30.4 (A12)
/Control Logic/Flag2: U5.12 (Q2), U6.28 (A13), U12.28 (A13), U30.28 (A13)
/Control Logic/Flag3: U5.11 (Q3), U6.29 (A14), U12.29 (A14), U30.29 (A14)
/Control Logic/Inst0: U2.14 (Q0), U6.8 (A4), U12.8 (A4), U30.8 (A4)
/Control Logic/Inst1: U2.13 (Q1), U6.7 (A5), U12.7 (A5), U30.7 (A5)
/Control Logic/Inst2: U2.12 (Q2), U6.6 (A6), U12.6 (A6), U30.6 (A6)
/Control Logic/Inst3: U2.11 (Q3), U6.5 (A7), U12.5 (A7), U30.5 (A7)
/Control Logic/Inst4: U6.27 (A8), U12.27 (A8), U20.14 (Q0), U30.27 (A8)
/Control Logic/Inst5: U6.26 (A9), U12.26 (A9), U20.13 (Q1), U30.26 (A9)
/Control Logic/Inst6: U6.23 (A10), U12.23 (A10), U20.12 (Q2), U30.23 (A10)
/Control Logic/ME: U6.13 (I/O0); also elsewhere on the board
/Control Logic/Step0: U3.14 (Q0), U6.12 (A0), U12.12 (A0), U30.12 (A0)
/Control Logic/Step1: U3.13 (Q1), U6.11 (A1), U12.11 (A1), U30.11 (A1)
/Control Logic/Step2: U3.12 (Q2), U6.10 (A2), U12.10 (A2), U30.10 (A2)
/Control Logic/Step3: U3.11 (Q3), U6.9 (A3), U12.9 (A3), U30.9 (A3)
/Control Logic/~AI: U30.19 (I/O5); also elsewhere on the board
/Control Logic/~AO: U30.20 (I/O6); also elsewhere on the board
/Control Logic/~BI: U30.17 (I/O3); also elsewhere on the board
/Control Logic/~BO: U30.18 (I/O4); also elsewhere on the board
/Control Logic/~CIH: U12.18 (I/O4); also elsewhere on the board
/Control Logic/~CIL: U12.17 (I/O3); also elsewhere on the board
/Control Logic/~COH: U12.20 (I/O6); also elsewhere on the board
/Control Logic/~COL: U12.19 (I/O5); also elsewhere on the board
/Control Logic/~FF: U6.19 (I/O5); also elsewhere on the board
/Control Logic/~FI: U5.9 (~PE), U12.14 (I/O1)
/Control Logic/~IC: U3.9 (~PE), U12.15 (I/O2)
/Control Logic/~II: U2.9 (~PE), U12.13 (I/O0), U20.9 (~PE)
/Control Logic/~MIH: U6.15 (I/O2); also elsewhere on the board
/Control Logic/~MIL: U6.14 (I/O1); also elsewhere on the board
/Control Logic/~NI: U30.21 (I/O7); also elsewhere on the board
/Control Logic/~RI: U6.20 (I/O6); also elsewhere on the board
/Control Logic/~RO: U6.21 (I/O7); also elsewhere on the board
/Control Logic/~TI: U6.17 (I/O3); also elsewhere on the board
/Control Logic/~TO: U6.18 (I/O4); also elsewhere on the board
/Control Logic/~UART_DR: U5.6 (D3); also elsewhere on the board
CLK_CTRL_AB: U2.2 (CP), U3.2 (CP), U5.2 (CP), U20.2 (CP); also elsewhere on the board
GND: U2.7 (CEP), U2.8 (GND), U2.10 (CET), U3.3 (D0), U3.4 (D1), U3.5 (D2), U3.6 (D3), U3.8 (GND), U5.7 (CEP), U5.8 (GND), U5.10 (CET), U6.1 (A18), U6.2 (A16), U6.3 (A15), U6.16 (GND), U6.22 (~CE), U6.24 (~OE), U6.30 (A17), U12.1 (A18), U12.2 (A16), U12.3 (A15), U12.16 (GND), U12.22 (~CE), U12.24 (~OE), U12.30 (A17), U20.7 (CEP), U20.8 (GND), U20.10 (CET), U30.1 (A18), U30.2 (A16), U30.3 (A15), U30.16 (GND), U30.22 (~CE), U30.24 (~OE), U30.30 (A17); also elsewhere on the board
~RESET: U3.1 (~MR); also elsewhere on the board

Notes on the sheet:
FLAGS REGISTER
INSTRUCTION REGISTER
STEP COUNTER


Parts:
U7, U8, U9, U10, U11: 74HC161; DIP-16_W7.62mm
U13: AS6C1008 SRAM; DIP-32_W15.24mm
U31: 74HC32; DIP-14_W7.62mm
U41: SST39SF040 512KB; DIP-32_W15.24mm_Socket

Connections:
+5V: U7.10 (CET), U7.16 (VCC), U8.16 (VCC), U9.16 (VCC), U10.16 (VCC), U11.16 (VCC), U13.32 (VCC), U41.32 (VCC); also elsewhere on the board
/ALU/BUS0: U11.3 (D0), U13.13 (I/O0), U41.13 (I/O0); also elsewhere on the board
/ALU/BUS1: U11.4 (D1), U13.14 (I/O1), U41.14 (I/O1); also elsewhere on the board
/ALU/BUS2: U11.5 (D2), U13.15 (I/O2), U41.15 (I/O2); also elsewhere on the board
/ALU/BUS3: U11.6 (D3), U13.17 (I/O3), U41.17 (I/O3); also elsewhere on the board
/ALU/BUS4: U13.18 (I/O4), U41.18 (I/O4); also elsewhere on the board
/ALU/BUS5: U13.19 (I/O5), U41.19 (I/O5); also elsewhere on the board
/ALU/BUS6: U13.20 (I/O6), U41.20 (I/O6); also elsewhere on the board
/ALU/BUS7: U13.21 (I/O7), U41.21 (I/O7); also elsewhere on the board
/Control Logic/ME: U7.7 (CEP), U8.7 (CEP), U9.7 (CEP), U10.7 (CEP); also elsewhere on the board
/Control Logic/~MIH: U9.9 (~PE), U10.9 (~PE); also elsewhere on the board
/Control Logic/~MIL: U7.9 (~PE), U8.9 (~PE); also elsewhere on the board
/Control Logic/~NI: U11.9 (~PE); also elsewhere on the board
/Control Logic/~RI: U31.2; also elsewhere on the board
/Control Logic/~RO: U13.24 (~OE), U41.24 (~OE); also elsewhere on the board
/Memory/A0: U7.14 (Q0), U13.12 (A0), U41.12 (A0)
/Memory/A1: U7.13 (Q1), U13.11 (A1), U41.11 (A1)
/Memory/A2: U7.12 (Q2), U13.10 (A2), U41.10 (A2)
/Memory/A3: U7.11 (Q3), U13.9 (A3), U41.9 (A3)
/Memory/A4: U8.14 (Q0), U13.8 (A4), U41.8 (A4)
/Memory/A5: U8.13 (Q1), U13.7 (A5), U41.7 (A5)
/Memory/A6: U8.12 (Q2), U13.6 (A6), U41.6 (A6)
/Memory/A7: U8.11 (Q3), U13.5 (A7), U41.5 (A7)
/Memory/A8: U9.14 (Q0), U13.27 (A8), U41.27 (A8)
/Memory/A9: U9.13 (Q1), U13.26 (A9), U41.26 (A9)
/Memory/A10: U9.12 (Q2), U13.23 (A10), U41.23 (A10)
/Memory/A11: U9.11 (Q3), U13.25 (A11), U41.25 (A11)
/Memory/A12: U10.14 (Q0), U13.4 (A12), U41.4 (A12)
/Memory/A13: U10.13 (Q1), U13.28 (A13), U41.28 (A13)
/Memory/A14: U10.12 (Q2), U13.3 (A14), U41.29 (A14)
/Memory/A15: U10.11 (Q3), U13.30 (CE2), U41.22 (~CE)
/Memory/BANK0: U11.14 (Q0), U41.3 (A15)
/Memory/BANK1: U11.13 (Q1), U41.2 (A16)
/Memory/BANK2: U11.12 (Q2), U41.30 (A17)
/Memory/BANK3: U11.11 (Q3), U41.1 (A18)
/Memory/MI0: U7.3 (D0); also elsewhere on the board
/Memory/MI1: U7.4 (D1); also elsewhere on the board
/Memory/MI2: U7.5 (D2); also elsewhere on the board
/Memory/MI3: U7.6 (D3); also elsewhere on the board
/Memory/MI4: U8.3 (D0); also elsewhere on the board
/Memory/MI5: U8.4 (D1); also elsewhere on the board
/Memory/MI6: U8.5 (D2); also elsewhere on the board
/Memory/MI7: U8.6 (D3); also elsewhere on the board
/Memory/MI8: U9.3 (D0); also elsewhere on the board
/Memory/MI9: U9.4 (D1); also elsewhere on the board
/Memory/MI10: U9.5 (D2); also elsewhere on the board
/Memory/MI11: U9.6 (D3); also elsewhere on the board
/Memory/MI12: U10.3 (D0); also elsewhere on the board
/Memory/MI13: U10.4 (D1); also elsewhere on the board
/Memory/MI14: U10.5 (D2); also elsewhere on the board
/Memory/MI15: U10.6 (D3); also elsewhere on the board
CLK_MAR: U7.2 (CP), U8.2 (CP), U9.2 (CP), U10.2 (CP), U11.2 (CP); also elsewhere on the board
GND: U7.8 (GND), U8.8 (GND), U9.8 (GND), U10.8 (GND), U11.7 (CEP), U11.8 (GND), U11.10 (CET), U13.2 (A16), U13.16 (GND), U13.22 (~CE), U13.31 (A15), U41.16 (GND); also elsewhere on the board
unnamed: U7.15 (TC), U8.10 (CET)
unnamed: U8.15 (TC), U9.10 (CET)
unnamed: U9.15 (TC), U10.10 (CET)
unnamed: U13.29 (~WE), U31.3, U41.31 (~WE)
~CLK_PULSE: U31.1; also elsewhere on the board
~RESET: U7.1 (~MR), U8.1 (~MR), U9.1 (~MR), U10.1 (~MR), U11.1 (~MR); also elsewhere on the board

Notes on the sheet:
MEMORY ADDRESS REGISTER MSB
MEMORY ADDRESS REGISTER LSB
BANK REGISTER


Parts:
U24, U25: 74HC283; DIP-16_W7.62mm
U26: 74HC245; DIP-20_W7.62mm
U27, U28: 74HC86; DIP-14_W7.62mm
U29: 74HC4078; DIP-14_W7.62mm
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

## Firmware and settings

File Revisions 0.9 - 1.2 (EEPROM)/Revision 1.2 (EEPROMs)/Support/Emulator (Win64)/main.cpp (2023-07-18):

// Minimal UART Emulator by Carsten Herting (2020/2021) Version 1.02
// Compile with g++ main.cpp -Os -s
// Have fun!

#include <iostream>											// console output
#include <windows.h>										// simple windows timing
#include <conio.h>											// keyboard input, ancient and non-portable :-)
#include <memory>
#include <vector>
#include <fstream>

#define BO   		0b0000000000000001			// definition of control lines within control word
#define BI  		0b0000000000000010
#define AO   		0b0000000000000100
#define AI   		0b0000000000001000
#define RO   		0b0000000000010000
#define RI   		0b0000000000100000
#define MI   		0b0000000001000000
#define HI   		0b0000000010000000
#define EOFI 		0b0000000100000000
#define ES   		0b0000001000000000
#define EC   		0b0000010000000000
#define IC   		0b0000100000000000
#define II   		0b0001000000000000
#define CEME 		0b0010000000000000
#define CO   		0b0100000000000000
#define CI   		0b1000000000000000
#define ACTLOW 	0b1101100101111111    	// 1: control signal is active low

class Component													// component interface class of the CPU
{
public:
	virtual void Reset() {}								// virtual defines that this Function will be overwritten in derived classes
	virtual void FallingEdge() {}
	virtual void BeingLow() {}	
	virtual void RisingEdge() {}	
	virtual void GettingHigh() {}
	virtual void BeingHigh() {}	
};

class Register : public Component				// modeled after 74LS161 / 74HC161 (4-Bit Counter) bzw. 74HC173 (4-Bit Register Latch)
{
public:	
	Register(uint8_t& port, uint16_t& ctrl, uint16_t inmask, uint16_t outmask, uint16_t countmask, uint16_t himask)
	: mPortLines(port), mCtrlLines(ctrl), mInMask(inmask), mOutMask(outmask), mCountMask(countmask), mHiMask(himask) {}
	void Reset() { mStore = 0; }
	void BeingLow()
	{
		if (mCtrlLines & mOutMask)
		{
			if (mCtrlLines & mHiMask) mPortLines = mStore>>8;
			else mPortLines = mStore & 0x00ff;
		}
	}
	void RisingEdge()
	{
		if (mCtrlLines & mInMask)
		{
			if (mCtrlLines & mHiMask) mStore = (mStore & 0x00ff) | mPortLines<<8;
			else mStore = (mStore & 0xff00) | mPortLines;
		}
		else if ((mCtrlLines & mCountMask) || mCountMask == 0xffff) mStore++;
	}
	uint16_t Get() { return mStore; }			// direct access (used by ALU and RAM)
private:
	uint16_t mStore;											// internal storage
	uint8_t& mPortLines;
	uint16_t& mCtrlLines;									// reference to the IO lines the component is connected to
	uint16_t mInMask, mOutMask, mCountMask, mHiMask;
};

class Adder : public Component
{
public:	
	Adder(uint8_t& port, uint16_t& ctrl, uint16_t outmask, uint16_t invmask, uint16_t cinmask, std::shared_ptr<Register> a, std::shared_ptr<Register> b, uint8_t& flags)
	: mPortLines(port), mCtrlLines(ctrl), mOutMask(outmask), mInvMask(invmask), mCinMask(cinmask), mRegA(a), mRegB(b), mFlagLines(flags) {}
	void BeingLow()
	{	
		int a, b;																													// A and B registers
		a = int(mRegA->Get()) & 0xff;
		if (mCtrlLines & mInvMask) b = int(~(mRegB->Get()) & 0xff);
		else b = int(mRegB->Get()) & 0xff;
		int result = a + b + bool(mCtrlLines & mCinMask);									// add operation with carry in
		if ((result & 0xff) == 0) mFlagLines |= 1; else mFlagLines &= ~1;	// zero flag
		if (result > 0xff) mFlagLines |= 2; else mFlagLines &= ~2;				// carry flag
		if (result & 0x80) mFlagLines |= 4; else mFlagLines &= ~4;				// negative flag
		if (mCtrlLines & mOutMask) mPortLines = uint8_t(result);					// output result if EO is active
	}
	void GettingHigh() { BeingLow(); }			// 74HC283 works asynchroneous, use "EO|AI, EO|RI" instead of "EO|AI|RI" (same for BI)
private:
	uint8_t& mPortLines;										// reference to the IO lines the component is connected to
	uint16_t& mCtrlLines;										// reference to the control word	
	uint16_t mOutMask, mInvMask, mCinMask;
	std::shared_ptr<Register> mRegA, mRegB;
	uint8_t& mFlagLines;										// connection to the flag lines (ALU outputs flags)
};

class Memory : public Component
{
public:	
	Memory(uint8_t& port, uint16_t& ctrl, uint16_t inmask, uint16_t outmask, std::shared_ptr<Register> mar, std::string& inbuf)
	: mPortLines(port), mCtrlLines(ctrl), mInMask(inmask), mOutMask(outmask), mMAR(mar), mInBuf(inbuf)
	{
		std::ifstream rom;
		rom.open("ROM.bin", std::ios::binary | std::ios::in);
		if (rom.is_open()) rom.read((char*)mStore, 0x2000);		
	}
	void BeingLow()
	{	
		if (mCtrlLines & mOutMask)
		{
			if (mMAR->Get() & 0x8000)									// Terminal -> Port
			{
				if (mInBuf.size() > 0) { mPortLines = mInBuf[0]; mInBuf = mInBuf.substr(1); }
				else mPortLines = 0;
			}
			else mPortLines = mStore[mMAR->Get()];		// RAM -> Port
		}
	}
	void BeingHigh()
	{
		if ((mCtrlLines & mInMask))
		{
			if((mMAR->Get() & 0x8000) == 0x8000 && mPortLines != 0) std::cout << mPortLines;	// 0x8000-0xffff: schreiben in UART
			else if (mMAR->Get() >= 0x2000) mStore[mMAR->Get()] = mPortLines;									// 0x2000-0x7fff: RAM, do not overwrite ROM 0x0000-0x1fff																																			// 0x0000-0x7fff: schreiben in RAM
		}		
	}
private:
	uint8_t& mPortLines;									// reference to the IO lines the component is connected to
	uint16_t& mCtrlLines;									// reference to the control word	
	uint16_t mInMask, mOutMask;
	std::shared_ptr<Register> mMAR;
	uint8_t mStore[32768];
	std::string& mInBuf;									// reference to the input buffer
};

class Control : public Component
{
public:	
	Control(uint8_t& port, uint16_t& ctrl, std::shared_ptr<Register> ireg, std::shared_ptr<Register> freg, std::shared_ptr<Register> sreg)
	: mPortLines(port), mCtrlLines(ctrl), mRegInstr(ireg), mRegFlags(freg), mRegSteps(sreg)
	{
		std::ifstream lsb("CTRL_LSB.bin", std::ios::binary | std::ios::in), msb("CTRL_MSB.bin", std::ios::binary | std::ios::in);
		if (lsb.is_open() && msb.is_open())
			for(int i=0; i<0x2000; i++) { lsb.read((char*)&mMicrocode[i]+0, 1); msb.read((char*)&mMicrocode[i]+1, 1); mMicrocode[i] ^= ACTLOW; }
	}
	void FallingEdge()						// set the control lines according to flags, instruction & step
	{
		mCtrlLines = mMicrocode[((mRegFlags->Get() & 0b111)<<10) | ((mRegInstr->Get() & 0b111111)<<4) | (mRegSteps->Get() & 0b1111)];
		if (mCtrlLines & IC)				// immediate asnychroneous reset
		{
			mRegSteps->Reset();
			mCtrlLines = mMicrocode[((mRegFlags->Get() & 0b111)<<10) | ((mRegInstr->Get() & 0b111111)<<4) | (mRegSteps->Get() & 0b1111)];
		}
		if (mCtrlLines & HI) mPortLines = 0x7f; else mPortLines = 0xff;				// also set the state of the port (pull-up to +5V)
	}	
private:
	uint8_t& mPortLines;									// reference to the IO lines the component is connected to
	uint16_t& mCtrlLines;									// reference to the control word	
	std::shared_ptr<Register> mRegInstr, mRegFlags, mRegSteps;
	uint16_t mMicrocode[8192];
};

class Computer
{
public:
	Computer()
	{
		std::shared_ptr<Register> areg = std::make_shared<Register>(mBusLines, mCtrlLines, AI, AO, 0, 0);
		std::shared_ptr<Register> breg = std::make_shared<Register>(mBusLines, mCtrlLines, BI, BO, 0, 0);
		std::shared_ptr<Register> ireg = std::make_shared<Register>(mBusLines, mCtrlLines, II, 0, 0, 0);
		std::shared_ptr<Register> freg = std::make_shared<Register>(mFlagLines, mCtrlLines, EOFI, 0, 0, 0);
		std::shared_ptr<Register> sreg = std::make_shared<Register>(mBusLines, mCtrlLines, 0, 0, 0xffff, 0);	// always counting
		std::shared_ptr<Register> pc = std::make_shared<Register>(mBusLines, mCtrlLines, CI, CO, CEME, HI);
		std::shared_ptr<Register> mar = std::make_shared<Register>(mBusLines, mCtrlLines, MI, 0, CEME, HI);
		std::shared_ptr<Control> ctrl = std::make_shared<Control>(mBusLines, mCtrlLines, ireg, freg, sreg);
		std::shared_ptr<Adder> alu = std::make_shared<Adder>(mBusLines, mCtrlLines, EOFI, ES, EC, areg, breg, mFlagLines);
		std::shared_ptr<Memory> ram = std::make_shared<Memory>(mBusLines, mCtrlLines, RI, RO, mar, mInput);
		mComponents.emplace_back(areg); mComponents.emplace_back(breg);
		mComponents.emplace_back(ireg); mComponents.emplace_back(freg); mComponents.emplace_back(sreg);
		mComponents.emplace_back(pc); mComponents.emplace_back(mar);
		mComponents.emplace_back(ctrl); mComponents.emplace_back(alu); mComponents.emplace_back(ram);	
		Reset();
	}
	void Reset()
	{
		for (auto& c : mComponents) c->Reset();
		mInput = ""; mSimTime = 0.0f;
		mLastTicks = GetTickCount();
	}
	void Update()
	{
		uint32_t nowticks = GetTickCount();
		mSimTime += (nowticks - mLastTicks)*0.001f;
		mLastTicks = nowticks;		
		while (mSimTime > 1.0f / 1843200.0f)
		{
			for(auto& c : mComponents) c->FallingEdge();
			for(auto& c : mComponents) c->BeingLow();
			for(auto& c : mComponents) c->RisingEdge();
			for(auto& c : mComponents) c->GettingHigh();
			for(auto& c : mComponents) c->BeingHigh();
			mSimTime -= 1.0f / 1843200.0f;
		}
	}
	void Input(char s) { mInput += s; }
protected:
	std::string mInput;
	uint32_t mLastTicks;
	float mSimTime;
	uint8_t mBusLines;
	uint8_t mFlagLines;
	uint16_t mCtrlLines;
	std::vector<std::shared_ptr<Component>> mComponents;
};

int main()
{
	SetConsoleMode(GetStdHandle(STD_OUTPUT_HANDLE), 0b111);		// enable ANSI control sequences in WINDOWS console
	Computer cpu;
	bool running = true;
	while (running)
	{
		while (kbhit())
		{
			static char lastch = 0;
			char ch = getch();												// read-in of a character code
			switch(lastch)
			{
				case -32:
					switch(ch)
					{
						case 79: running = false; break;		// END
						case 71: cpu.Reset(); break;				// POS1 = Reset
						default: break;
					}
					break;
				default:
					switch(ch)														// expecting "single key"
					{
						case -32: break;										// move to special key mode
						case 13: cpu.Input('\n'); break;
						default: cpu.Input(ch); break;
					}
					break;
			}
			lastch = ch;
		}		
		cpu.Update();
		Sleep(1);
	}
	return 0;
}

/*
------------------------------------------------------------------------------
This software is available under 2 licenses -- choose whichever you prefer.
------------------------------------------------------------------------------
ALTERNATIVE A - MIT License
Copyright (c) 2020 Carsten Herting
Permission is hereby granted, free of charge, to any person obtaining a copy of
this software and associated documentation files (the "Software"), to deal in
the Software without restriction, including without limitation the rights to
use, copy, modify, merge, publish, distribute, sublicense, and/or sell copies
of the Software, and to permit persons to whom the Software is furnished to do
so, subject to the following conditions:
The above copyright notice and this permission notice shall be included in all
copies or substantial portions of the Software.
THE SOFTWARE IS PROVIDED "AS IS", WITHOUT WARRANTY OF ANY KIND, EXPRESS OR
IMPLIED, INCLUDING BUT NOT LIMITED TO THE WARRANTIES OF MERCHANTABILITY,
FITNESS FOR A PARTICULAR PURPOSE AND NONINFRINGEMENT. IN NO EVENT SHALL THE
AUTHORS OR COPYRIGHT HOLDERS BE LIABLE FOR ANY CLAIM, DAMAGES OR OTHER
LIABILITY, WHETHER IN AN ACTION OF CONTRACT, TORT OR OTHERWISE, ARISING FROM,
OUT OF OR IN CONNECTION WITH THE SOFTWARE OR THE USE OR OTHER DEALINGS IN THE
SOFTWARE.
------------------------------------------------------------------------------
ALTERNATIVE B - Public Domain (www.unlicense.org)
This is free and unencumbered software released into the public domain.
Anyone is free to copy, modify, publish, use, compile, sell, or distribute this
software, either in source code form or as a compiled binary, for any purpose,
commercial or non-commercial, and by any means.
In jurisdictions that recognize copyright laws, the author or authors of this
software dedicate any and all copyright interest in the software to the public
domain. We make this dedication for the benefit of the public at large and to
the detriment of our heirs and successors. We intend this dedication to be an
overt act of relinquishment in perpetuity of all present and future rights to
this software under copyright law.
THE SOFTWARE IS PROVIDED "AS IS", WITHOUT WARRANTY OF ANY KIND, EXPRESS OR
IMPLIED, INCLUDING BUT NOT LIMITED TO THE WARRANTIES OF MERCHANTABILITY,
FITNESS FOR A PARTICULAR PURPOSE AND NONINFRINGEMENT. IN NO EVENT SHALL THE
AUTHORS BE LIABLE FOR ANY CLAIM, DAMAGES OR OTHER LIABILITY, WHETHER IN AN
ACTION OF CONTRACT, TORT OR OTHERWISE, ARISING FROM, OUT OF OR IN CONNECTION
WITH THE SOFTWARE OR THE USE OR OTHER DEALINGS IN THE SOFTWARE.
------------------------------------------------------------------------------
*/

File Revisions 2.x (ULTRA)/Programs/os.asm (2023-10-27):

; ****************************************************************
; *****                                                      *****
; ***** MinOS2 Operating System for the 'Minimal UART Ultra' *****
; *****                                                      *****
; ***** by Carsten Herting (slu4)  -  updated 2023 Sept 23th *****
; *****                                                      *****
; ****************************************************************

#org 0x0000                                                    ; Bank 0, Address 0 = entry point after RESET

OS_Bootloader:  ; LDI 'A' OUT                                    ; for debug only
                ; NOP NOP NOP NOP NOP NOP
                ; NOP NOP NOP NOP NOP
                
                LDI <OS_Image STA 0xfffc                       ; move image source address to 0xfffc/d
                LDI >OS_Image STA 0xfffd
                LDI <_Kernel STA 0xfffe                        ; move kernel destination address to 0xfffe/f
                LDI >_Kernel STA 0xffff

  imcopyloop:   ; LDA 0xffff SBI 0xf0 ADI '0' OUT                ; for debug only
                ; NOP NOP NOP NOP NOP NOP
                ; NOP NOP NOP NOP NOP
                
                LDR 0xfffc STR 0xfffe                          ; copy the OS image to kernel RAM area
                INW 0xfffc INW 0xfffe
                LDA 0xfffe CPI <OS_Beyond BNE imcopyloop       ; destination LSB < kernel LSB? Note: BNE instead of BCS!
                  LDA 0xffff CPI >OS_Beyond BCC imcopyloop     ; destination MSB < kernel MSB?

                    ; LDI 'B' OUT                                ; for debug only
                    ; NOP NOP NOP NOP NOP NOP
                    ; NOP NOP NOP NOP NOP

; **********************************************************************************************************

OS_Image:                                                      ; OS image starts HERE on bank 0

  #mute                                                        ; do not emit origin address...
  #org 0xf000                                                  ; ... but assemble for kernel destination
  #emit                                                        ; begin emitting code here

  _Kernel:        JPA OS_Start                                 ; KERNEL START WITH JUMP TABLE
  _Prompt:        JPA OS_Prompt
  _MemMove:       JPA OS_MemMove
  _Random:        JPA OS_Random

  _ReadLine:      JPA OS_ReadLine
  _SkipSpace:     JPA OS_SkipSpace
  _ReadHex:       JPA OS_ReadHex
  _Print:         JPA OS_Print
  _PrintHex:      JPA OS_PrintHex
  _Wait:          JPA OS_Wait

  _FlashErase:    JPA OS_FlashErase
  _FlashWrite:    JPA OS_FlashWrite
  _FlashPtrA:     JPA OS_FlashPtrA

  _FindFile:      JPA OS_FindFile
  _LoadFile:      JPA OS_LoadFile
  _SaveFile:      JPA OS_SaveFile

  _Clear:         JPA OS_Clear
  _ClearRow:      JPA OS_ClearRow
  _CursorOn:      JPA OS_CursorOn
  _CursorOff:     JPA OS_CursorOff
  _CursorX:       JPA OS_CursorX
  _CursorY:       JPA OS_CursorY
  _MoveX:         JPA OS_MoveX
  _MoveY:         JPA OS_MoveY

OS_Start:       LDI 0xfe STA 0xffff                            ; init stack

                LDI <logotxt PHS LDI >logotxt PHS              ; print splash screen
                JPS OS_Print PLS PLS

  OS_Prompt:    LDI 0xfe STA 0xffff                        ; switch off FLASH and init stack
                LDI <readytxt PHS LDI >readytxt PHS
                JPS OS_Print PLS PLS

  newline:      LDI <_ReadBuffer STA _ReadPtr+0                ; parse a line of user input
                LDI >_ReadBuffer STA _ReadPtr+1
                JPS OS_ReadLine                                ; MAIN LOOP: read in a line of user input
                JPS OS_SkipSpace                               ; omit leading spaces
                LDR _ReadPtr CPI 10 BEQ newline                ; empty line?
                  JPS OS_LoadFile CPI 0 BEQ OS_Error           ; load the file (=instruction)
                    JPR PtrD                                   ; run a loaded program with command line ptr on stack

  OS_Error:     LDI <errortxt PHS LDI >errortxt PHS JPS OS_Print
                JPA OS_Prompt

  logotxt:      27, '[H', 27, '[J', 27, '[?25h',               ; clear screen and show cursor
                27, '[8G', 'Minimal UART Ultra CPU with MinOS2', 10, 10
                27, '[8G', '32KB RAM - 512KB SSD - 10MHz Clock', 10, 10, 0
  readytxt:     'READY.', 10, 0
  errortxt:     'File not found.', 10, 0

; -------------------------------------------------------------------------------------
; Reads a line of input into _ReadBuffer starting from _ReadPtr
; set _ReadPtr to the desired position within _ReadBuffer buffer (1-50 chars)
; modifies: _ReadPtr
; -------------------------------------------------------------------------------------
OS_ReadLine:    LDA _ReadPtr+0 PHS LDA _ReadPtr+1 PHS       ; save desired buffer start
  waitchar:     WIN CPI 0x80 BCS waitchar                   ; ignore unprintable chars (UP, DN, PgUp, etc.)
                  CPI 9 BEQ waitchar                        ; ignore TAB
                  CPI 27 BNE checkback                      ; ESC invalidates input data
                    PLS STA _ReadPtr+1 PLS STA _ReadPtr+0   ; move back to start of input buffer
                    LDI 10 STR _ReadPtr OUT RTS             ; quit with ENTER at beginning
  checkback:      CPI 8 BNE havenoback                      ; check for BACKSPACE
                    OUT LDS 2 CPA _ReadPtr+0 BEQ waitchar
                      DEB _ReadPtr+0 JPA waitchar
  havenoback:     STR _ReadPtr CPI 10 BEQ haveenter         ; store char & check for ENTER
                    LDA _ReadPtr+0 CPI <ReadLast BEQ waitchar ; end of line reached? => don't print!
                      LDR _ReadPtr OUT INB _ReadPtr+0 JPA waitchar ; enough space => print it
  haveenter:      PLS STA _ReadPtr+1 PLS STA _ReadPtr+0     ; move pointer back to start of input buffer
                  LDI 10 OUT RTS                            ; perform 'ENTER'

; ---------------------------------------------------------------------------------------
; Advances the input line pointer _ReadPtr over SPACES, " and ' to the next relevant char
; modifies: _ReadPtr
; ---------------------------------------------------------------------------------------
OS_SkipSpace:   LDR _ReadPtr CPI 32 BCC ps_useit            ; use < SPACE
                  CPI 40 BCS ps_useit                       ; use above code 39 (above " and ')
                    INB _ReadPtr+0 JPA OS_SkipSpace
  ps_useit:     RTS
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

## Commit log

2021-06-06 Out now!
    [8-Bit CPU 32k.dsn, 8-Bit CPU 32k.kicad_pcb, 8-Bit CPU 32k.sch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]
2022-06-22 Revision 1.6 Redux
    [8-Bit CPU 32k.dsn, 8-Bit CPU 32k.kicad_pcb, 8-Bit CPU 32k.kicad_sch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]
2022-07-08 4.9MHz upgrade
    [8-Bit CPU 32k.dsn, 8-Bit CPU 32k.kicad_pcb, 8-Bit CPU 32k.kicad_sch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]
2022-07-16 Revision 1.6.1
    [8-Bit CPU 32k.dsn, 8-Bit CPU 32k.kicad_pcb, 8-Bit CPU 32k.kicad_sch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]
2023-10-27 Minimal UART Ultra is out!
2023-10-27 Minimal UART Ultra out now!

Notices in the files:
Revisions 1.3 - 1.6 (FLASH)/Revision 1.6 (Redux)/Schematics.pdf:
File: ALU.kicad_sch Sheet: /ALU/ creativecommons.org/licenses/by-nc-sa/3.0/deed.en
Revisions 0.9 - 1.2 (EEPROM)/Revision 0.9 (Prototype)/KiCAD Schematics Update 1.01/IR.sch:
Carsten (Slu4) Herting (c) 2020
